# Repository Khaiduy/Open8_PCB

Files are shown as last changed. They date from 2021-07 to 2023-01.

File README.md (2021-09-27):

# Open8_PCB

The folder TR4_PGA257 contain:
1. Schematic and layout for PGA257 Socket (PGA257_Socket).
2. Schematic and layout for TEE-PCB version 4.0(TR4).
3. Schematic of the TEE-PGA257_v3.0, used as reference.
4. Pin map and port declaration of chip.
5. Folder ROHM_PCB_thuc is the new PCB that apply Thuc's suggestion.
  - Change SD card and Flash to Pmod module.
    Link: SD card: https://digilent.com/reference/pmod/pmodmicrosd/reference-manual?redirect=1
          Flash: https://digilent.com/reference/pmod/pmodsf3/reference-manual?redirect=
  - Change USB-UART to module: https://www.marutsu.co.jp/GoodsDetail.jsp?q=PL2303SA&salesGoodsCode=137791&shopNo=3
  - Supply clock from SMA only.

Two PCBs for EAGLE is contained:
1. QFP160 socket: the socket and pin connection only.
2. demo_open8: demo board for Open8 in SOTB with pin connection to QFP160 socket.

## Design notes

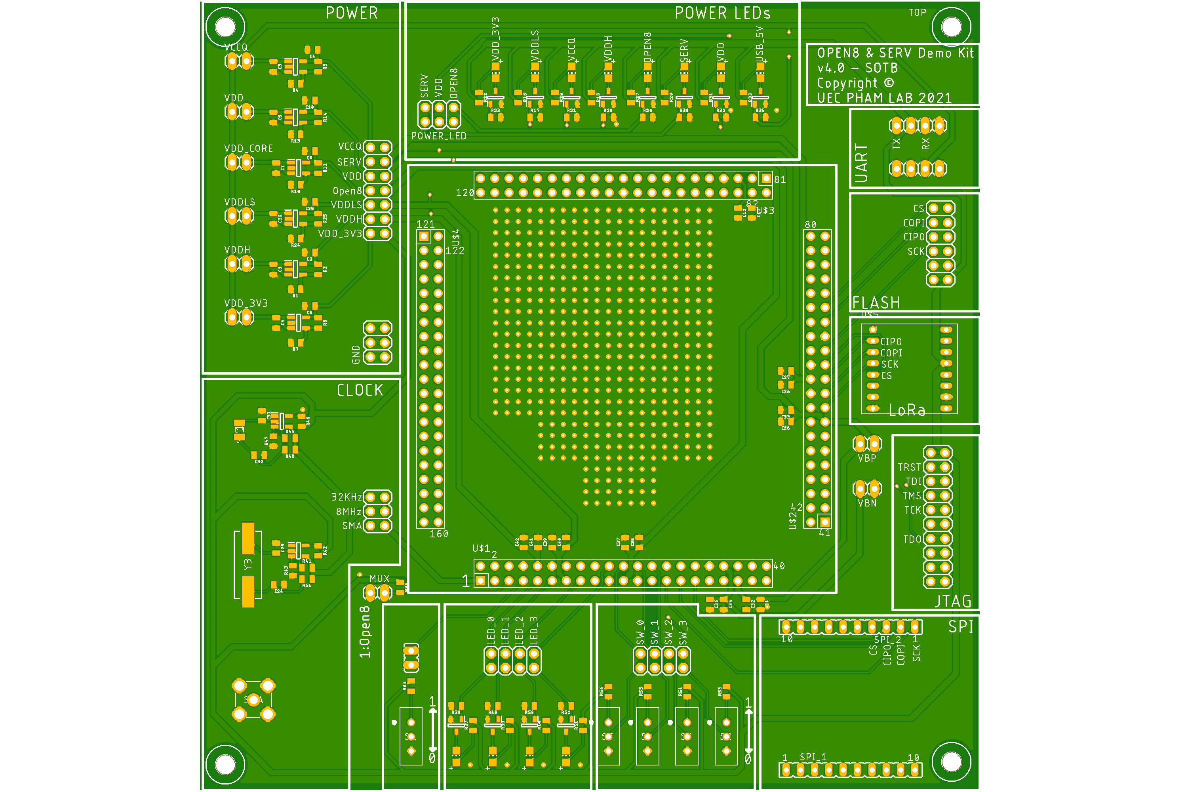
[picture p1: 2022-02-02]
SERV_Open8_SOTB_PCB/serv_open8_sotb_top.png

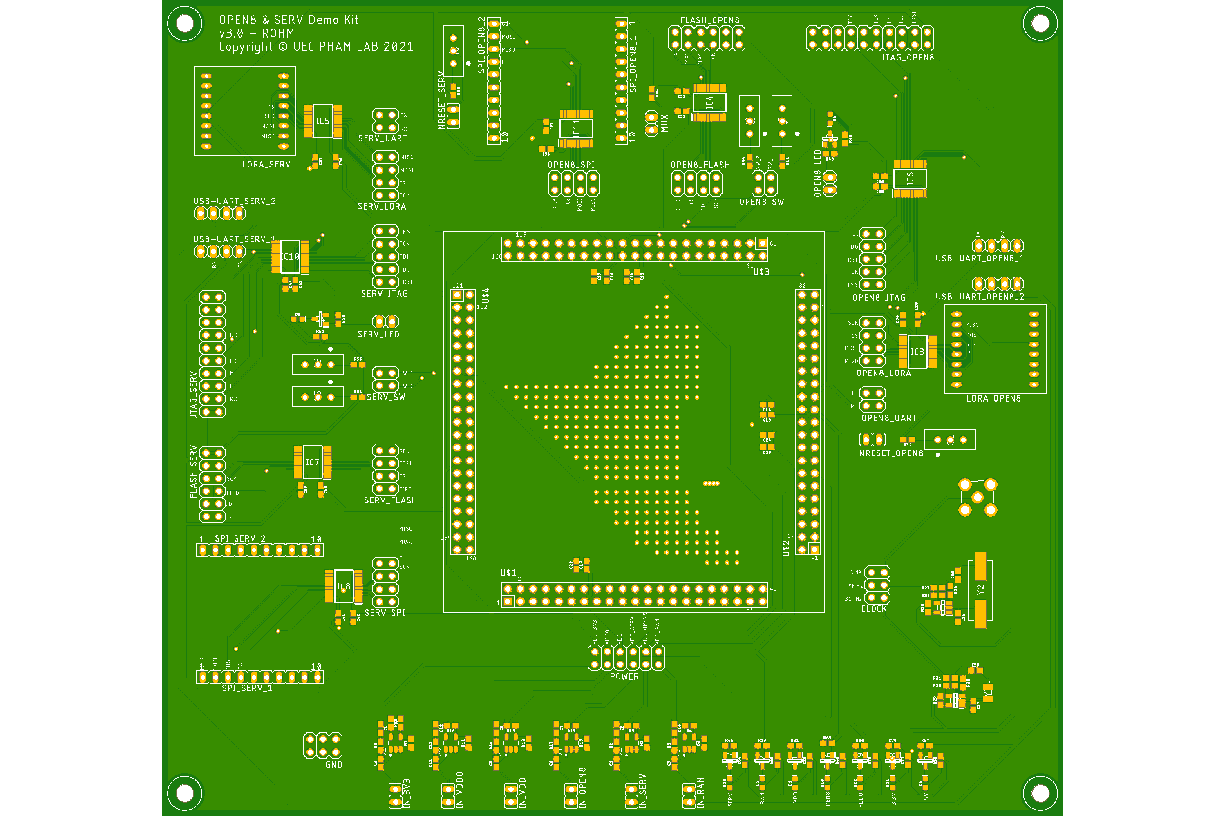
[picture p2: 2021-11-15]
SERV_Open8_ROHM_PCB/serv_open8_rohm_top.png

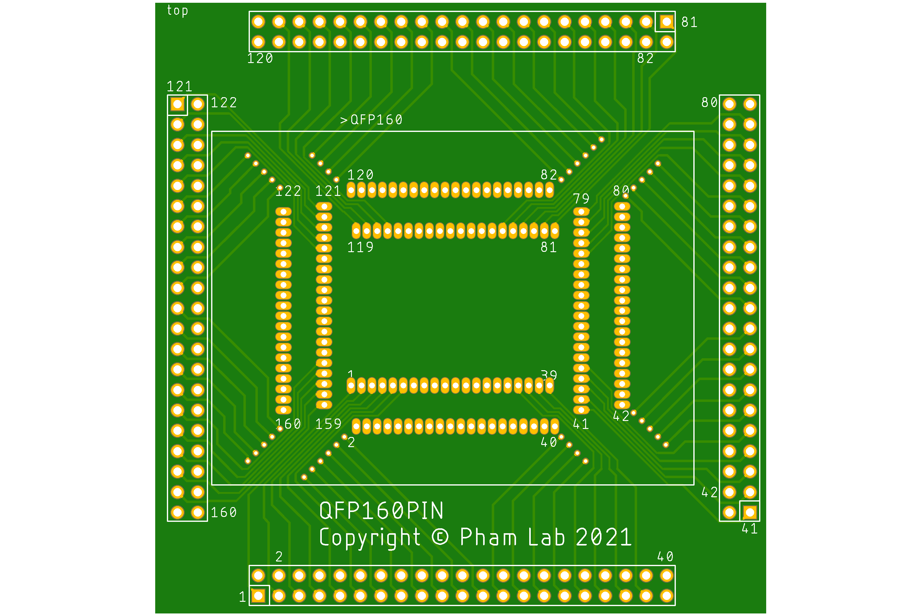
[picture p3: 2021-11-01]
QFP160_new_socket/qfp160_socket_new_top.png

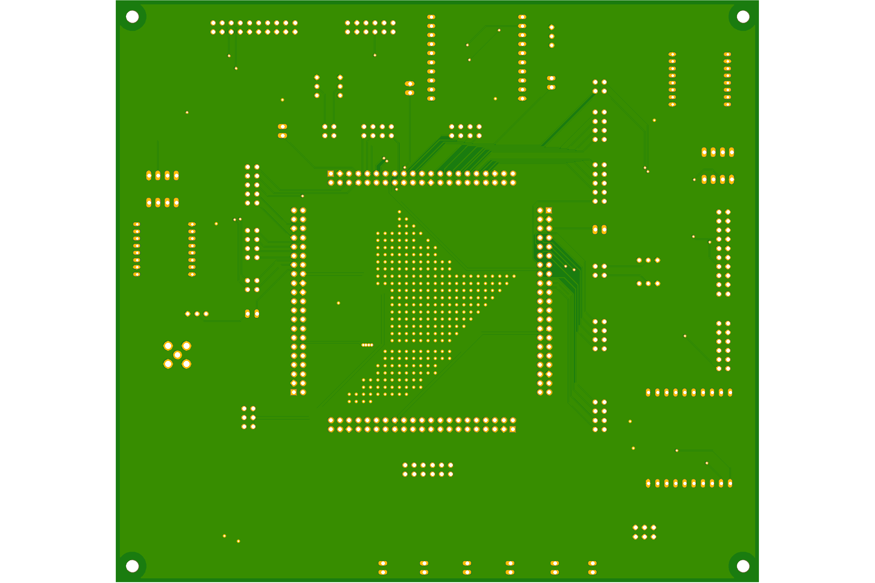
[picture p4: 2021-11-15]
SERV_Open8_ROHM_PCB/serv_open8_rohm_bottom.png

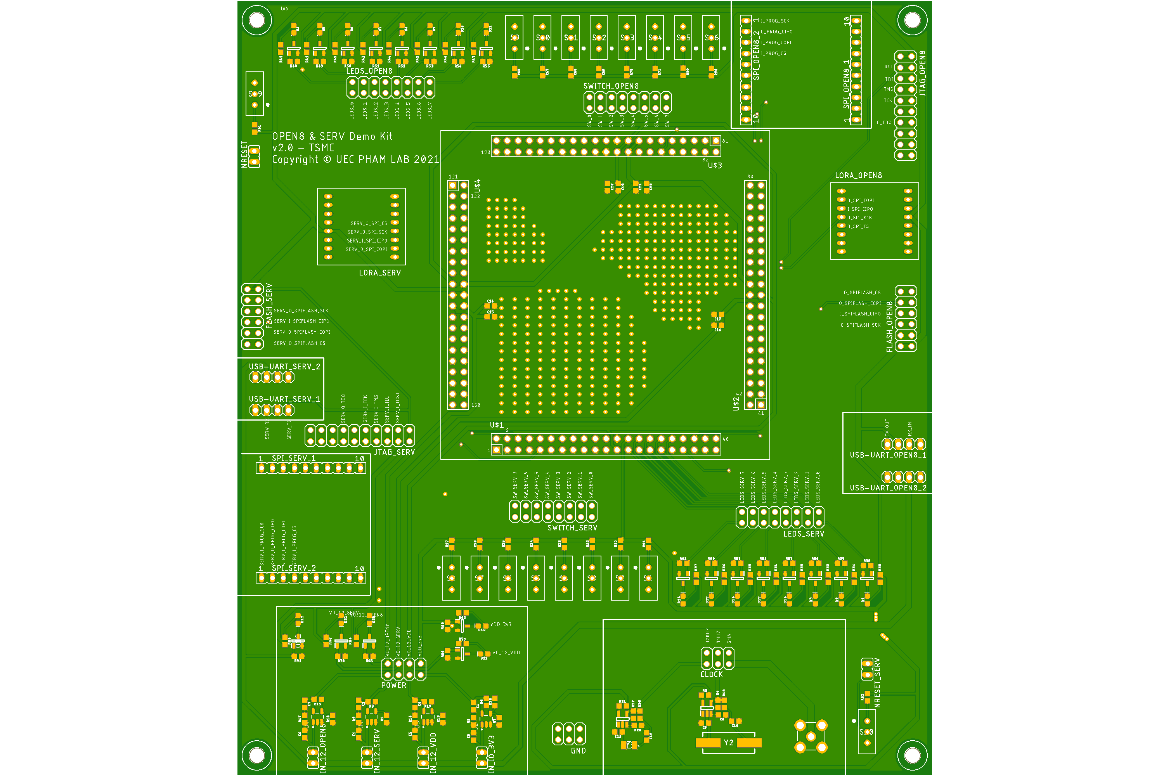
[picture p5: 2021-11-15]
SERV_Open8_TSMC_PCB/serv_open8_tsmc_top.png

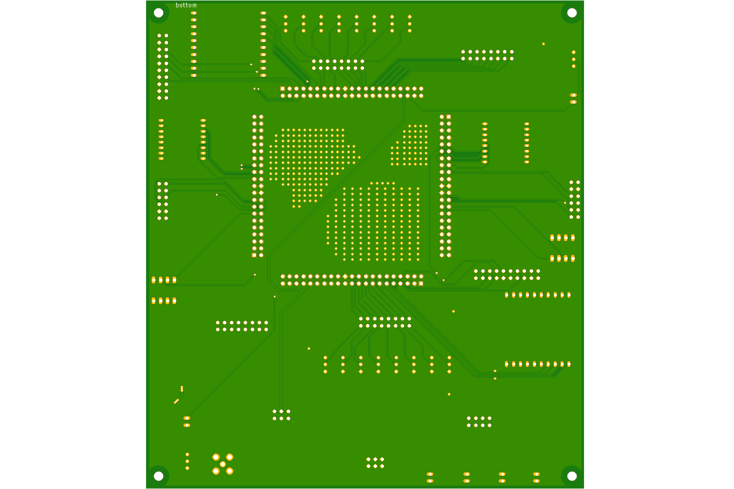
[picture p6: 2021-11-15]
SERV_Open8_TSMC_PCB/serv_open8_tsmc_bottom.png

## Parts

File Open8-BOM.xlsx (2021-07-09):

Comment | Designator | Footprint | LCSC Part #（optional）
100nF | C12, C14, C16, C17, C18, C19 | 603 | C14663
1Ω | R14, R17, R21 | 603 | C22936
1uF | C1, C3, C6, C9 | 603 | C105504
1.5kΩ | R11 | 603 | C22843
10kΩ | R18 | 603 | C25804
10uF | C5, C11, C13, C15, C20, C21, C22 | 603 | C96446
240Ω | R19 | 603 | C23350
27Ω | R9, R10 | 603 | C25190
3.3kΩ | R12 | 603 | C22978
330Ω | R1, R2, R3, R4, R5, R6, R7, R8, R22, R23, R24, R25, R26, R27 | 603 | C23138
4.7uF | C4, C7, C10 | 603 | C19666
43kΩ | R15 | 603 | C23172
62kΩ | R13, R16, R20 | 603 | C23221
BSH103,235 | FPGA_33, Q1, Q2, Q4, Q5 | SOT-23-3 | C88711
LED | D1 , D2, D3, D4, D5, D6, D7, D8, D9, D10, D11, D12, D13, D14 | LED_0603 | C72044
USB SOP-8 | IC1 | SOP-8_3.9x4.9x1.27P | C57946
Dropout Regulators | U3, U4, U5 | SOT-23-5 | C13997
USB Connectors | J3 | USB-MINI-SMD | C145778
Pin Header 2 1 | LORA_DIO0, LORA_NSS, LORA_RESET, J1, IN_33, IN_07, IN_12, OUT_07, OUT_12, VBN, VBP, VDD, VCCQ, VDDH, VDDLS | HDR-TH_2P-P2.54-V | C160332
Pin Header 6 1 | SV3, SV4 | 2.54mm 1X6 | C37208
Pin Header 40 2 | JP1, JP2, JP3, JP4 | HDR-TH_40P-P2.54-V-M-R2-C20-S2.54 | C124383
Pin Header 6 2 | GND | HDR-TH_6P-P2.54-V-R2-C3-S2.54 | C124384
Pin Header 3 1 | PIN_OUT | HDR-TH_3P-P2.54-V | C124376
Female Header 10 1 Straight | SV1, SV2 | 2.54mm | C35445
Pin Header 8 2 | SWITCH | HDR-TH_8P-P2.54-V-R2-C4-S2.54 | C124386
Pin Header 4 2 Straight | UART, OUT_33 | HDR-TH_4P-P2.54-V-R2-C2-S2.54 | C124362

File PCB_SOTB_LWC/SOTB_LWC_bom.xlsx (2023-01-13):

Comment | Designator | Footprint | LCSC Part #（optional）
LEDCHIPLED_0805 | LED3, LED4, LED5, LW_O0, LW_O1 | 805 | C34499
0.1uF | C15, C17, C19, C21, C23, C27, C29, C31, C33, C35, C37, C39, C41, C43, C45, C47, C49, C51, C53 | 1206 | C110255
10uF | C1, C3, C4, C6, C7, C9, C14, C16, C18, C20, C22, C26, C28, C30, C32, C34, C36, C38, C40, C42, C44, C46, C48, C50, C52 | 1206 | C13585
100pF | C54 | 805 | C1790
25pF | C24, C25 | 805 | C1807
50pF | C55 | 805 | C1823
2.7nF | C8 | 1206 | C1860
3.3nF | C5 | 1206 | C282859
4.7nF | C2 | 1206 | C9192
1.07k | R1 | 1206 | C290176
1.4k | R3 | 1206 | C102090
1.78k | R2 | 1206 | C706404
100 | R10 | 1206 | C118845
10k | R9 | 1206 | C132649
1k | R4, R7, R11, R14, R18 | 1206 | C1469
2.2M | R8 | 1206 | C111535
2k | R5 | 1206 | C17944
330 | R20 | 1206 | C114944
357 | R6 | 1206 | C205334
LP38511MR-ADJ_NOPB | IC1, IC2, IC3 | SOIC127P600X170 | C113276
Q13FC1350000400 | Y2 | SMD3215-2P | C32346
SN74LVC1G14DCKR | IC5 | SOT65P210X110-5N | C2976657
SN74LVC1GU04DCKR | IC4 | SOT65P210X110-5N | C485082

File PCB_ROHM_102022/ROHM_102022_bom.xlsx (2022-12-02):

Comment | Designator | Footprint | LCSC Part #（optional）
LEDCHIPLED_0805 | LED1, LED2, LED3, LED4, LOADED | 805 | C84256
0.1uF | C11, C12, C23, C25, C26, C29, C30, C33, C34, C15, C16, C17, C18, C21, C37, C38, C39, C40, C41, C42 | 1206 | C110255
100uF | C7, C9, C19 | 1206 | C15008
10pF | C3, C4 | 1206 | C107172
10uF | C13, C14, C24, C27, C28, C31, C32, C35, C36, C22 | 1206 | C13585
15pF | C5, C6 | 1206 | C1887
22uF | C8, C10, C20 | 1206 | C12891
10k | R1, R2, R11 | 1206 | C17902
330 | R3, R4, R5, R6, R14 | 1206 | C114944
AMS1117-1.8 | IC1, IC4, IC5 | SOT-223 | C6185
Q13FC1350000400 | Y2 | SMD3215-2P | C32346
Q22FA1280034500 | Y1 | SMD2016-4P | C255901
TXB0108PWR | IC7, IC10 | TSSOP-20 | C53406
W9825G6KH-6I | IC3 | TSOP-54 | C97572

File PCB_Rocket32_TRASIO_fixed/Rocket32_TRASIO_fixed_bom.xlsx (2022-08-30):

Comment | Designator | Footprint | LCSC Part #（optional）
LED | D1, D2, D3, D4 | 1206 | C434439
0.1uF | C1, C2, C3, C4, C11, C12 | 1206 | C110255
100uF | C5, C9 | 1206 | C15008
10k | R10, R12, R14, R16 | 1206 | C17902
10uF | C13, C14 | 1206 | C13585
22uF | C6, C10 | 1206 | C90146
330 | R11, R13, R15, R17 | 1206 | C25374
AMS1117-1.8 | IC3, IC5 | SOT-223 | C6185
2N7002K-7 | Q5, Q6, Q7, Q8 | SOT-23-3 | C705095
TXB0108PWR | IC1, IC2 | TSSOP-20 | C53406

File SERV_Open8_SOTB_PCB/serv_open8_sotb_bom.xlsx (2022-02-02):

Comment | Designator | Footprint | LCSC Part #（optional）
LED | LED1, LED2, LED3, LED4, LED5, LED6, LED7, LED8, LED9, LED10, LED11, LED12 | 805 | C2290
0.1uF | C12, C27, C33, C34, C36, C38, C40, C42 | 805 | C476766
1.0uF | C1, C3, C5, C7, C9, C22 | 805 | C24123
10M | R41, R45 | 805 | C26108
10k | R17, R19, R21, R23, R28, R30, R32, R34, R35, R36, R38, R40, R50, R52, R53, R54, R55, R56 | 805 | C115309
10uF | C11, C26, C28, C32, C35, C37, C39, C41 | 805 | C15850
133k | R2, R11, R14 | 805 | C17452
22pF | C30, C31 | 805 | C1804
2k | R44 | 805 | C17604
300k | R48 | 805 | C17616
330 | R16, R18, R20, R22, R27, R29, R31, R33, R37, R39, R49, R51 | 805 | C17630
36pF | C24, C29 | 805 | C327231
4.7uF | C2, C4, C6, C8, C10, C25 | 805 | C1779
47k | R42, R43, R46, R47 | 805 | C17713
482k | R5, R8 | 805 | C17717
66.5k | R1, R4, R7, R10, R13, R24, R25 | 805 | C17791
AP7331-WG-7 | IC1, IC2, IC5, IC7, IC8, IC9 | SOT-25 | C212322
BSH103,235 | Q1, Q2, Q3, Q4, Q5, Q6, Q7, Q8, Q9, Q10, Q11, Q12 | SOT-23-3 | C88711
HC-49SM8MHZ20PF30PPM | Y3 | SMD-CRY-3.8x13.5_2P | C107426
SN74LVC1GU04DBVR | IC12, IC13 | SOT-23-5 | C81934
Q13FC1350000400 | Y1 | SMD-3215_2P | C32346

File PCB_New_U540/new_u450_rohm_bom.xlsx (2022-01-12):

Comment | Designator | Footprint | LCSC Part #（optional）
LED | D1, D2, D3, D4 | 1206 | C93094
0.1uF | C1, C2, C3, C4, C11, C12 | 1206 | C110253
100uF | C5, C7, C9 | 1206 | C76656
10uF | C13, C14 | 1206 | C92797
10kOhm | R10, R12, R14, R16 | 1206 | C118075
22uF | C6, C8, C10 | 1206 | C386093
300Ohm | R11, R13, R15, R17 | 1206 | C229537
AMS1117-1.8 | IC3, IC4, IC5 | SOT-223 | C6185
CJ2301 S1 | Q1, Q2, Q3, Q4 | SOT-23-3 | C8547
TXB0108PWR | IC1, IC2 | SSOP-20_4 | C53406

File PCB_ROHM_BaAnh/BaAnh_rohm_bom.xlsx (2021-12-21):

Comment | Designator | Footprint | LCSC Part #（optional）
LED | LED1, LED2, LED3, LED4, LED5, LED6, LED7, LED8, LED9, LED10, LED11, LED12, LED13, LED14, LED15, LED16, LED17, LED18, LED19, LED20, LED21 | 805 | C165984
0.1uF | C1, C2, C3, C4, C5, C6, C7, C8 | 805 | C476766
1ohm | R45, R48, R59 | 805 | C247113
1uF | C9, C11, C13, C15, C17, C19, C21, C22, C24, C27, C29 | 805 | C28323
10k | R2, R4, R6, R8, R10, R12, R14, R16, R18, R20, R22, R24, R25, R26, R27, R28, R29, R30, R31, R32, R33, R34, R35, R36, R38, R40, R41, R42, R50, R52, R53, R54, R55, R56, R61, R63, R65, R67, R69 | 805 | C17414
10pF | C14, C16, C18, C20, C23, C26, C28, C30 | 805 | C1785
113k | R44, R47 | 805 | C17424
2198LPST | S1, S2 | 2198LPST | C314503
243k | R58 | 805 | C17573
330ohm | R1, R3, R5, R7, R9, R11, R13, R15, R17, R19, R21, R23, R37, R39, R49, R51, R60, R62, R64, R66, R68 | 805 | C17630
4.7uF | C10, C12, C25 | 805 | C98195
66.5k | R43, R46, R57 | 805 | C17791
BSH103,235 | Q1, Q2, Q3, Q4, Q5, Q6, Q7, Q8, Q9, Q10, Q11, Q12, Q13, Q14, Q15, Q16, Q17, Q18, Q19, Q20, Q21 | SOT-23-3 | C88711
TPS76201DBVR | IC3, IC5, IC7 | SOT-23-5 | C13997
TXB0108PWR | IC1, IC2, IC4, IC6 | TSSOP-20_4.4x6.5x0.65P | C53406

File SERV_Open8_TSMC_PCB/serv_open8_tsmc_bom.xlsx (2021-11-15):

Comment | Designator | Footprint | LCSC Part #（optional）
0.1uF | C14, C16, C19, C21 | 603 | C77055
1 OHM | R2, R8, R14, R17 | 603 | C247057
1.0uF | C1, C3, C5, C6 | 603 | C1689
10M OHM | R4, R20 | 603 | C7250
10kOHM | R11, R12, R22, R23, R24, R25, R26, R27, R38, R39, R48, R49, R50, R51, R52, R53, R54, R55, R56, R57, R58, R59, R60, R61, R63, R65, R66, R67, R68, R69, R70, R71, R78, R80, R81, R82, R89, R90, R91 | 603 | C25804
10uF | C15, C17, C20, C22 | 603 | C85713
22pF | C11, C12 | 603 | C1653
243kOHM | R10 | 603 | C23351
2kOHM | R18 | 603 | C22900
300kOHM | R29 | 603 | C23024
330OHM | R30, R31, R32, R33, R34, R35, R36, R37, R40, R41, R42, R43, R44, R45, R46, R47, R62, R64, R77, R79, R88 | 603 | C23138
36pF | C9, C10 | 603 | C159790
3kOHM | R9 | 603 | C4211
4.7uF | C2, C4, C7, C8 | 603 | C19666
47kOHM | R5, R6, R21, R28 | 603 | C25819
53.6kOHM | R3, R15, R19 | 603 | C23074
66.5KOHM | R1, R7, R13, R16 | 603 | C23225
BSH103,235 | Q1, Q2, Q3, Q4, Q5, Q6, Q7, Q8, Q9, Q10, Q11, Q14, Q15, Q16, Q17, Q18, Q19, Q25, Q26, Q27, Q28 | SOT-23-3 | C88711
HC-49SM8MHZ20PF30PPM | Y2 | SMD-CRY-3.8x13.5_2P | C107426
LED | D1, D2, D3, D4, D5, D6, D7, D8, D9, D10, D11, D12, D16, D17, D18, D19, D20, D21, D22, D27, D28 | 603 | C2286
Q13FC1350000400 | Y3 | SMD-3215_2P | C32346
SN74LVC1GU04DBVR | IC1, IC2 | SOT-23-5 | C81934
TPS76201DBVR | U1, U2, U3, U4 | SOT-23-5 | C13997

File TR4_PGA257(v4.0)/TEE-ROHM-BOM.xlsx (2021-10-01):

Comment | Designator | Footprint | LCSC Part #（optional）
0.1uF | C1, C2, C3, C4, C5, C6, C19, C21 | 603 | C77055
100uF | C14, C16, C18 | 603
10KOHM | R7, R8, R9, R22, R23, R24, R25, R26, R27, R28, R29, R30, R31, R32, R33, R58, R59, R60, R61, R62, R63, R64, R65, R66, R67, R68, R69, R70, R71 | 603 | C25804
10uF | C13, C15, C17, C20, C22 | 603 | C1691
15KOHM | R1, R3, R5 | 603 | C22809
Switch | S1_DIP8 | 2198LPST | C314503
330OHM | R46, R47, R48, R49, R50, R51, R52, R53, R54, R55, R56, R57 | 603 | C23138
6.8KOHM | R2, R4, R6 | 603 | C23212
BSH103,235 | Q3, Q4, Q5, Q6, Q7, Q8, Q9, Q10, Q11, Q12, Q13 | SOT-23-3 | C88711
DSHP03TSGET | S1 | SW-SMD | C50844
LED0 | D4, D5, D6, D7, D8, D9, D10, D11, D12, D13, D14, D15 | LED-0603 | C2286
LM1117IMPX-ADJ/NOPB | IC7, IC8, IC9 | SOT-223 | C19228
SN74AVC4T774RSVR | IC1, IC2, IC3 | UQFN-16 | C779392

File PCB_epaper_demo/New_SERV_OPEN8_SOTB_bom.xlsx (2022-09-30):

Comment | Designator | Footprint | LCSC Part #（optional）
0.01uF | C17 | 805 | C1710
0.1uF | C9, C12, C27, C33, C34, C36, C38, C40, C42 | 805 | C49678
1uF | C1, C3 | 805 | C24123
100uF | C16 | 805 | C141660
10uF | C5, C6, C7, C8, C10, C11, C26, C28, C32, C35, C37, C39, C41 | 805 | C17024
2.2uF | C2 | 805 | C87994
4.7uF | C4 | 805 | C92762
100k | R4, R3 | 805 | C149504
10k | R5, R7, R36 | 805 | C17414
560k | R2 | 805 | C352198
SN74AUP1G00DCKR | IC4, IC5 | SC-70-5 | C206053
SN74AUP1G14DBVR | U3 | SOT-23-5 | C2682131
SN74LVC1G32DBVR | U1 | SOT-23-5 | C10096
LM358AMX_NOPB | IC6 | SOIC-8 | C5423
1k | R11 | 805 | C17513
2.2k | R6 | 805 | C17520
110k | R1 | 805 | C413317

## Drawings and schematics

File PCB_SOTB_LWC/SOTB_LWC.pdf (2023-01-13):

2985-6004

## SN74LVC1GU04DCKR

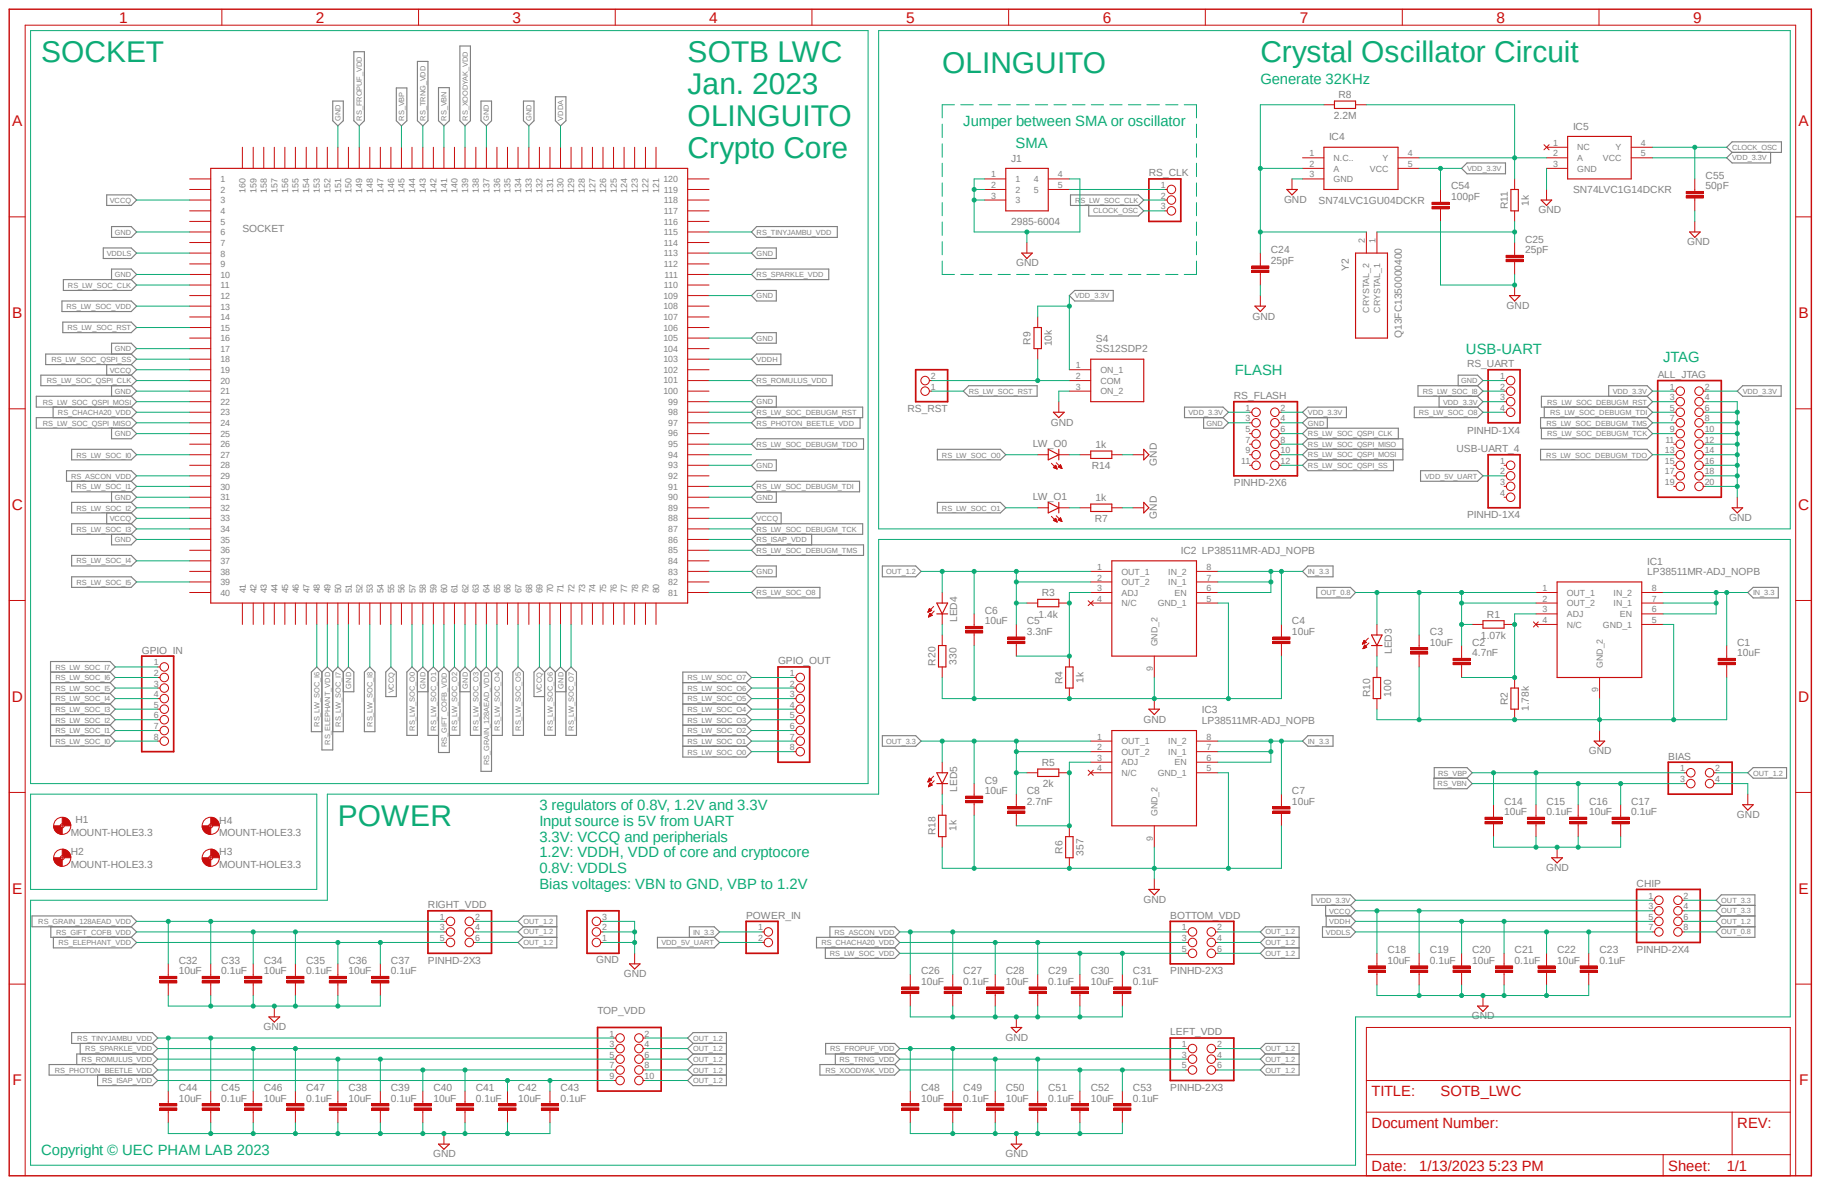
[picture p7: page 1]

Jumper between SMA or oscillator

3 | RS_LW_SOC_CLK CLOCK_OSC | 2 3

CHIP R¹⁰ R²⁰ R¹⁸
PINHD-2X4 ¹⁰⁰ ³³⁰ ¹k

Input source is 5V from UART
3.3V: VCCQ and peripherials
1.2V: VDDH, VDD of core and cryptocore
0.8V: VDDLS
Bias voltages: VBN to GND, VBP to 1.2V

Document Number: | REV:

Copyright © UEC PHAM LAB 2023

Date: 1/13/2023 5:23 PM | Sheet: 1/1

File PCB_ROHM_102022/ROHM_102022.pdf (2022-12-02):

## W9825G6KH-6I

## GND

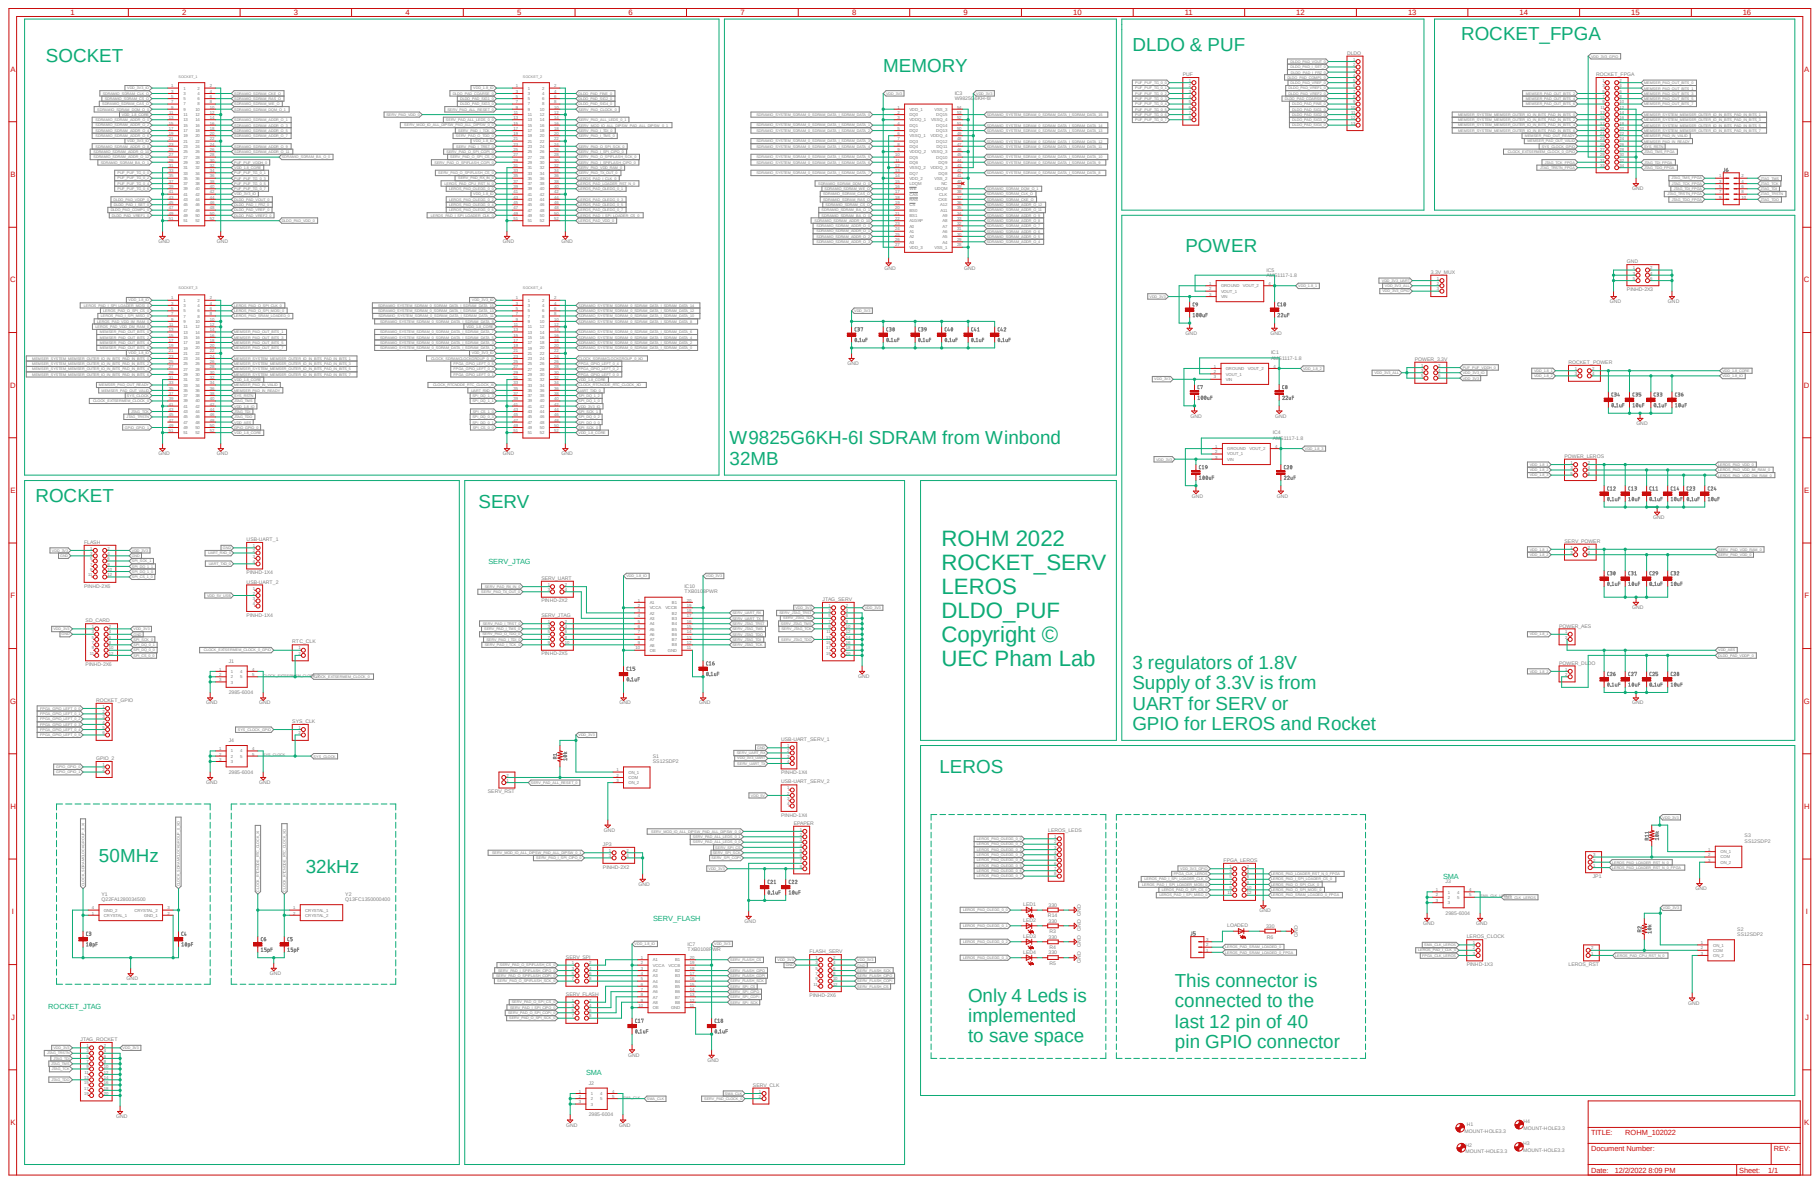
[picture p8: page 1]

3 regulators of 1.8V
Supply of 3.3V is from
UART for SERV or
GPIO for LEROS and Rocket

Document Number: | REV:

Date: 12/2/2022 8:09 PM | Sheet: 1/1

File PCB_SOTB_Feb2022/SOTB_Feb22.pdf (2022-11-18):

# GND ¹⁰k

# K_LEROS_RAM_2_VDD K_FL_ADDR[3]

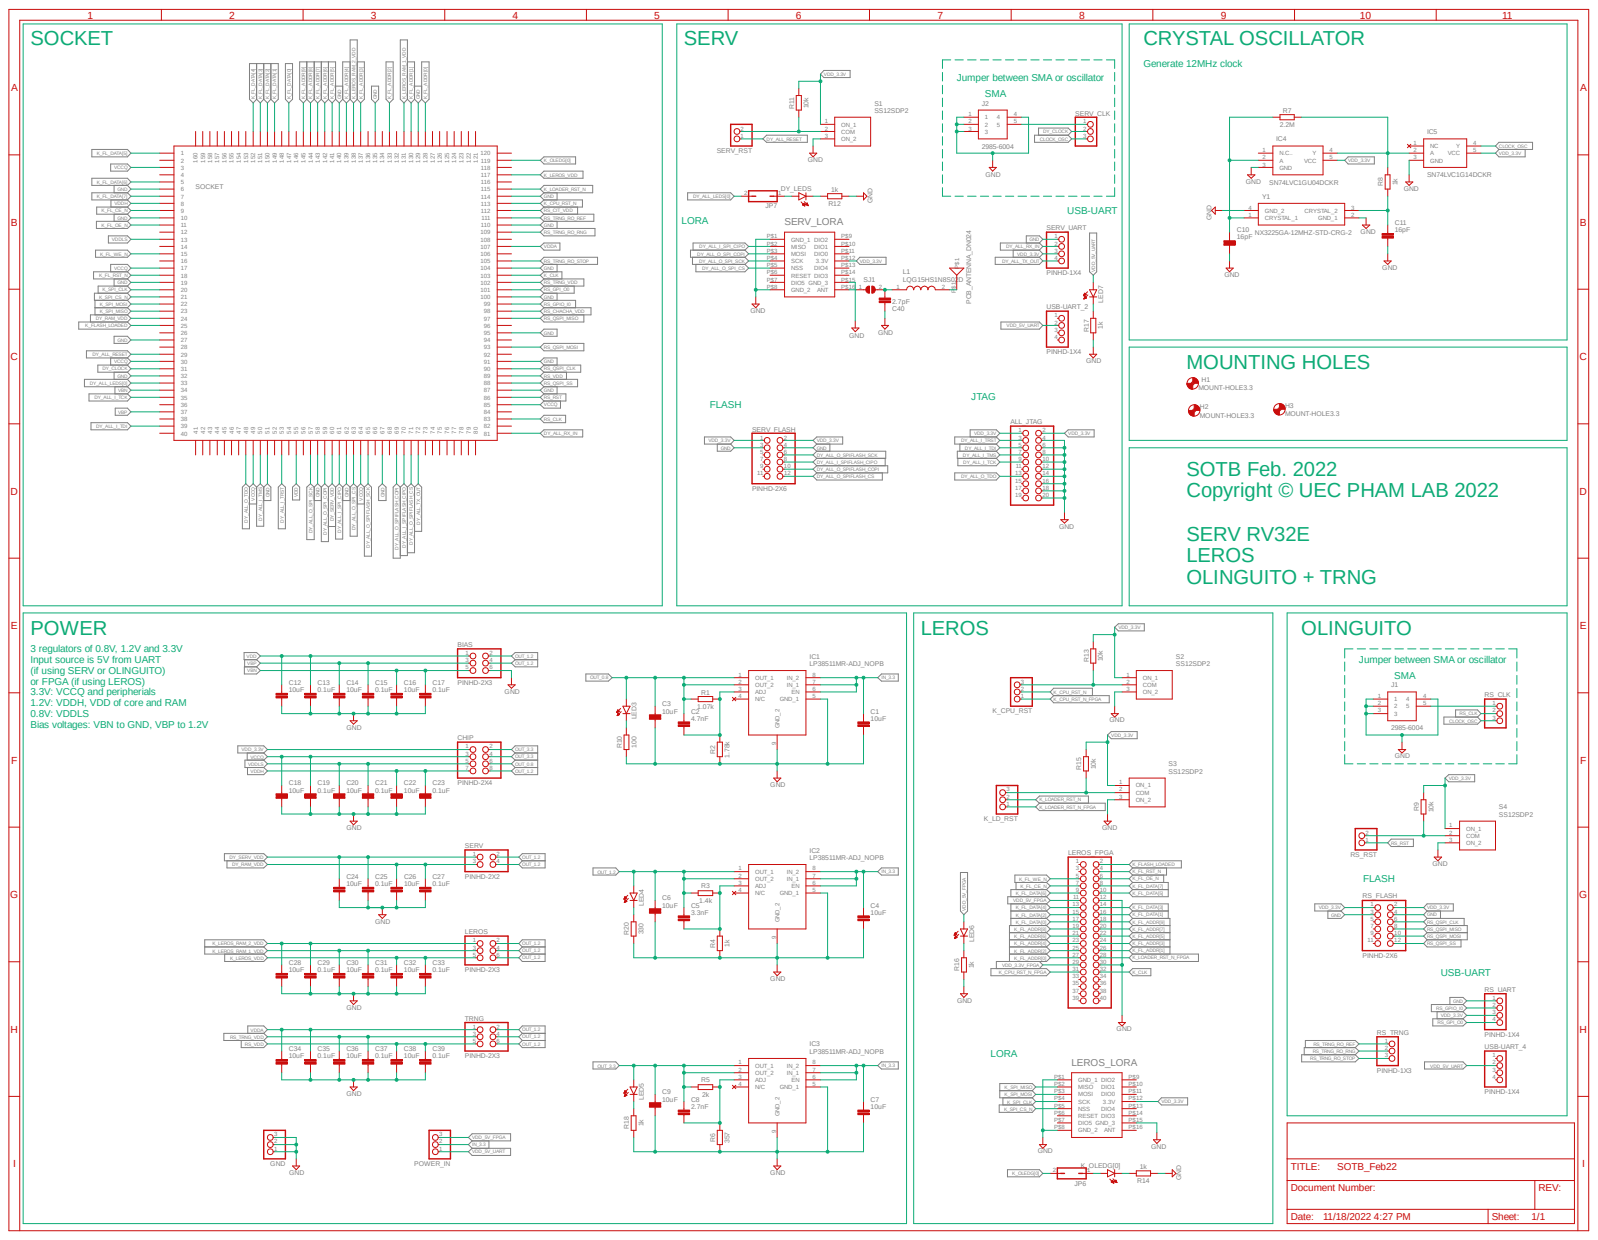
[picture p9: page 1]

Jumper between SMA or oscillator | Generate 12MHz clock

Copyright © UEC PHAM LAB 2022

VDD | | DY_ALL_O_SPI_SCK

BIAS | VDD_3.3V | | Jumper between SMA or oscillator SMA J1

3 regulators of 0.8V, 1.2V and 3.3V
Input source is 5V from UART
(if using SERV or OLINGUITO)
or FPGA (if using LEROS)
3.3V: VCCQ and peripherials
1.2V: VDDH, VDD of core and RAM
0.8V: VDDLS

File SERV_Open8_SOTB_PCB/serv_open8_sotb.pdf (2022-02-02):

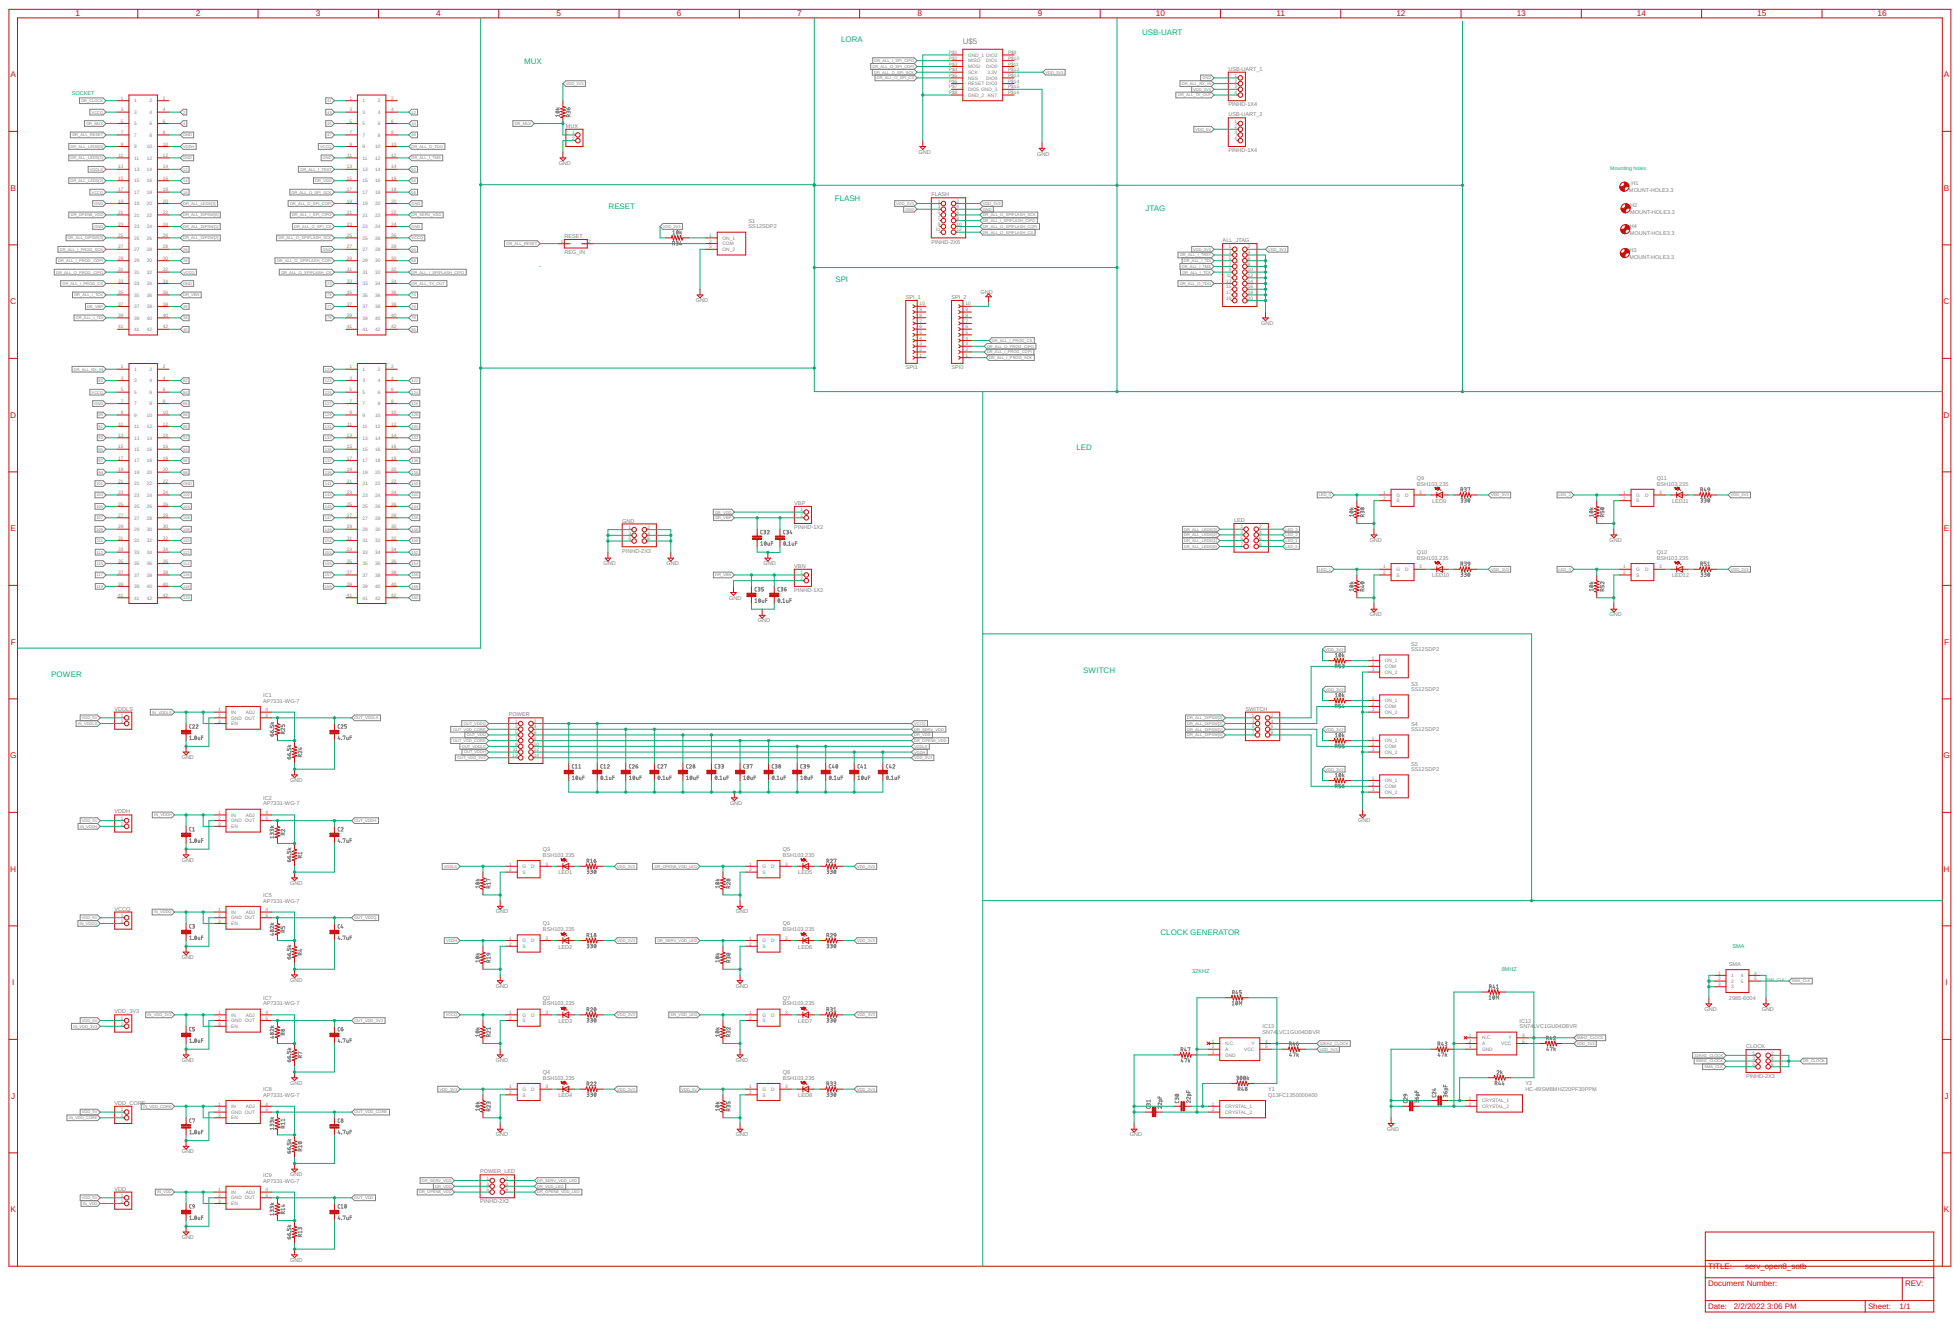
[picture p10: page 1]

Mounting holes
MOUNT-HOLE3.3 MOUNT-HOLE3.3

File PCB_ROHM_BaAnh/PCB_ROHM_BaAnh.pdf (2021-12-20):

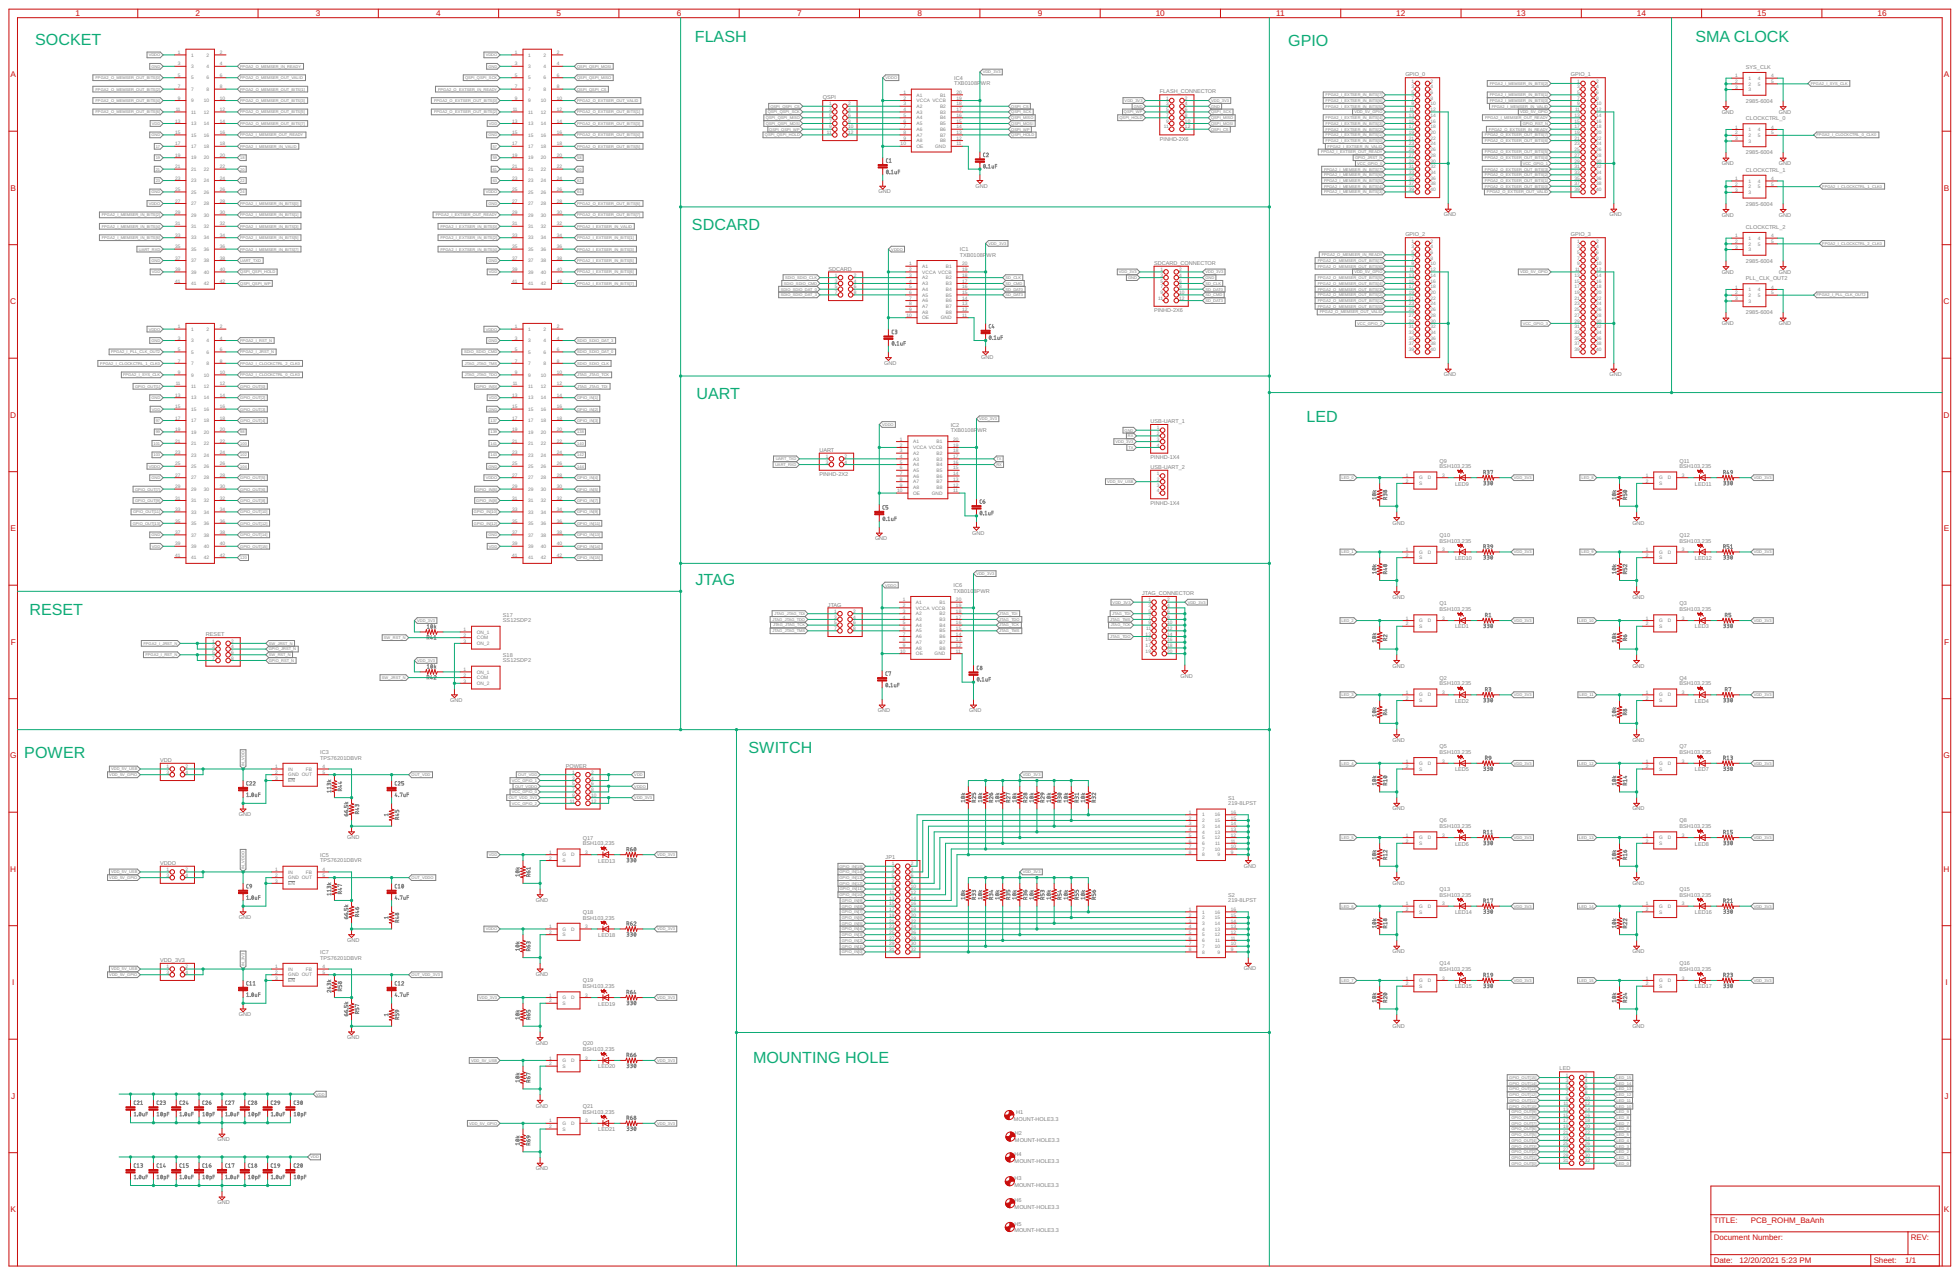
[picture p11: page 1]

MOUNT-HOLE3.3 MOUNT-HOLE3.3 MOUNT-HOLE3.3 MOUNT-HOLE3.3 GND

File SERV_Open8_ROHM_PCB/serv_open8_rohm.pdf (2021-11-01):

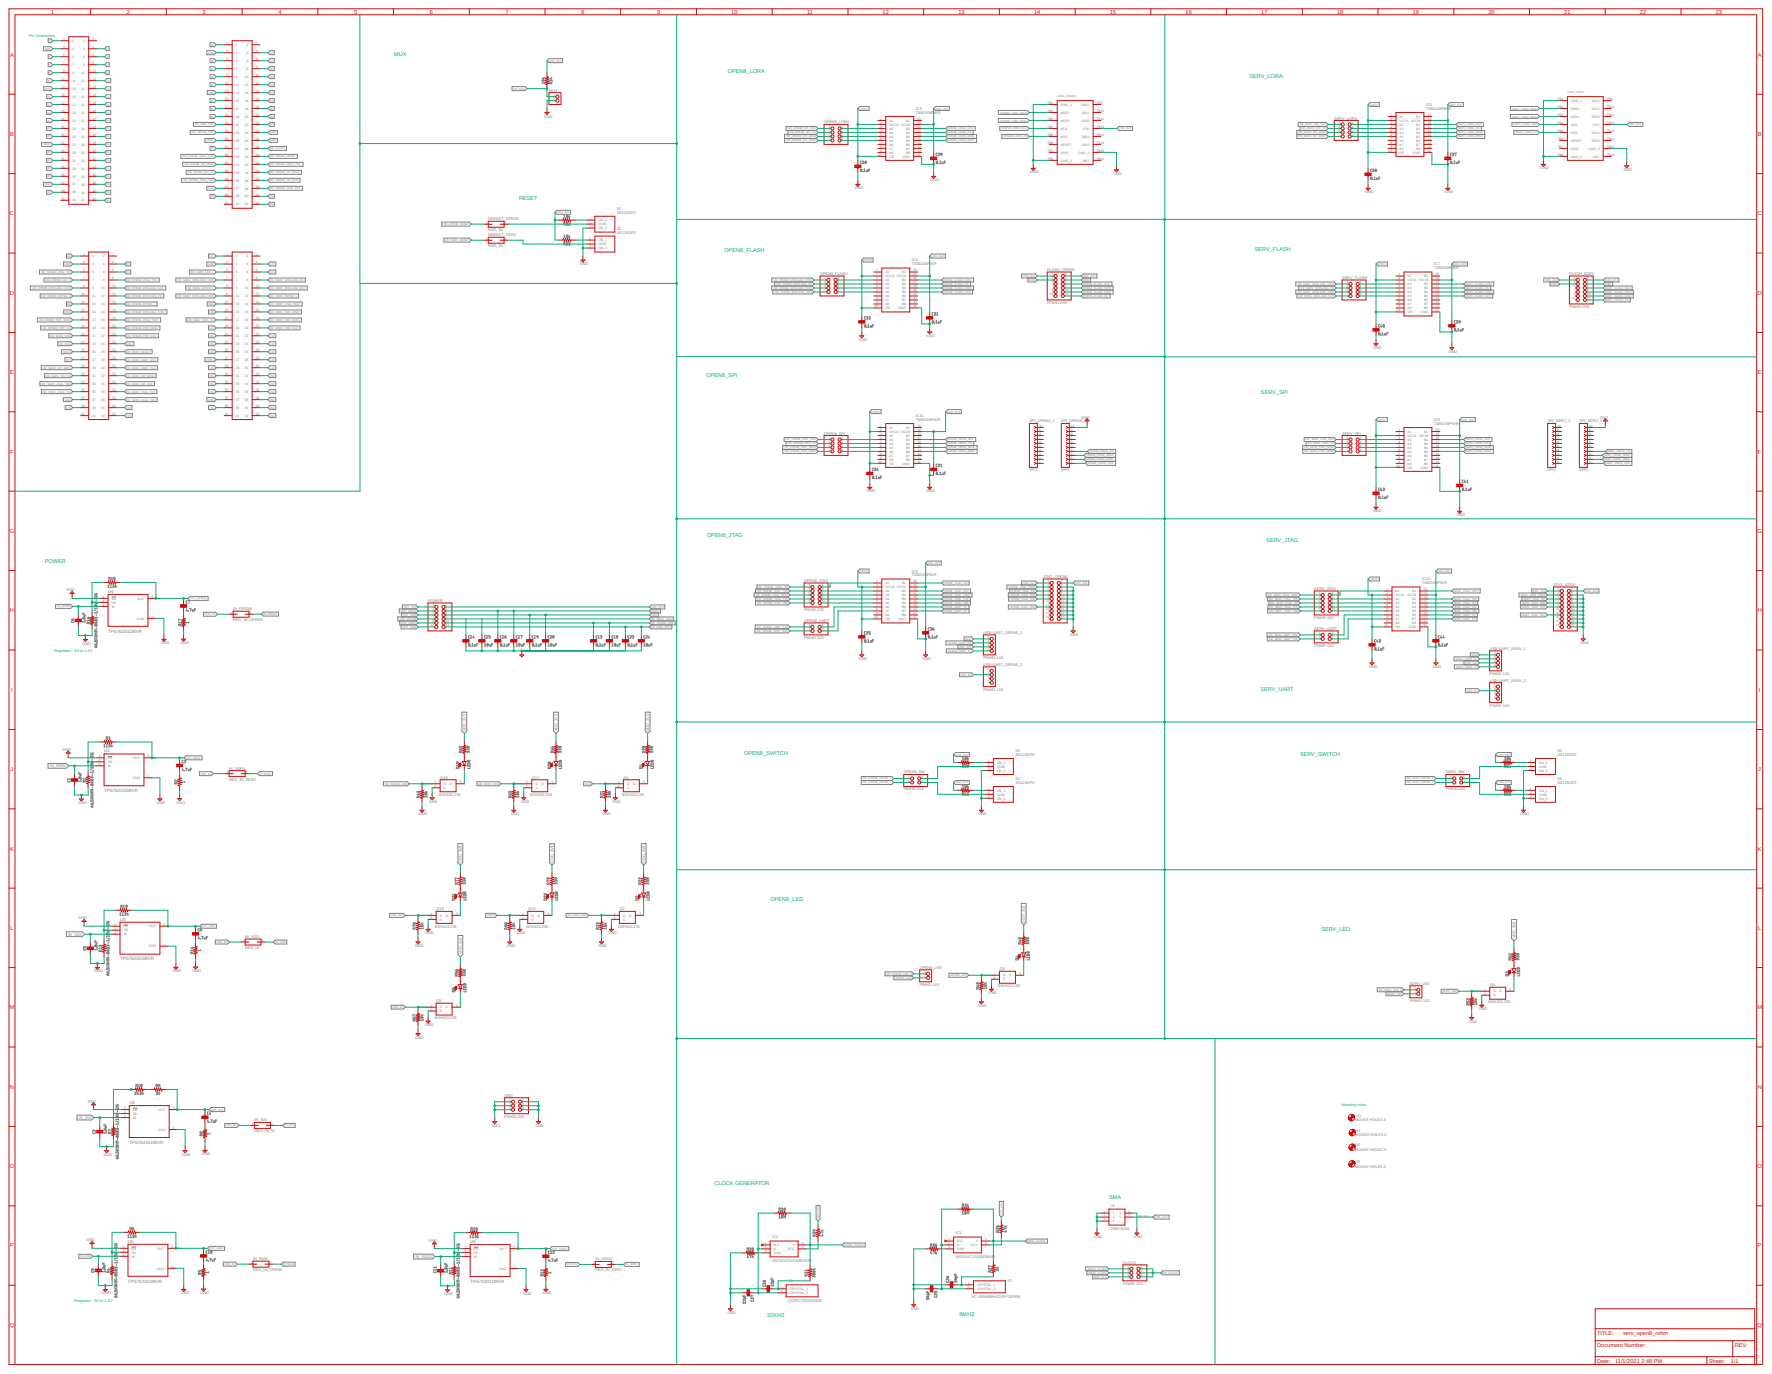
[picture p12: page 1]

Mounting holes
MOUNT-HOLE3.3 MOUNT-HOLE3.3

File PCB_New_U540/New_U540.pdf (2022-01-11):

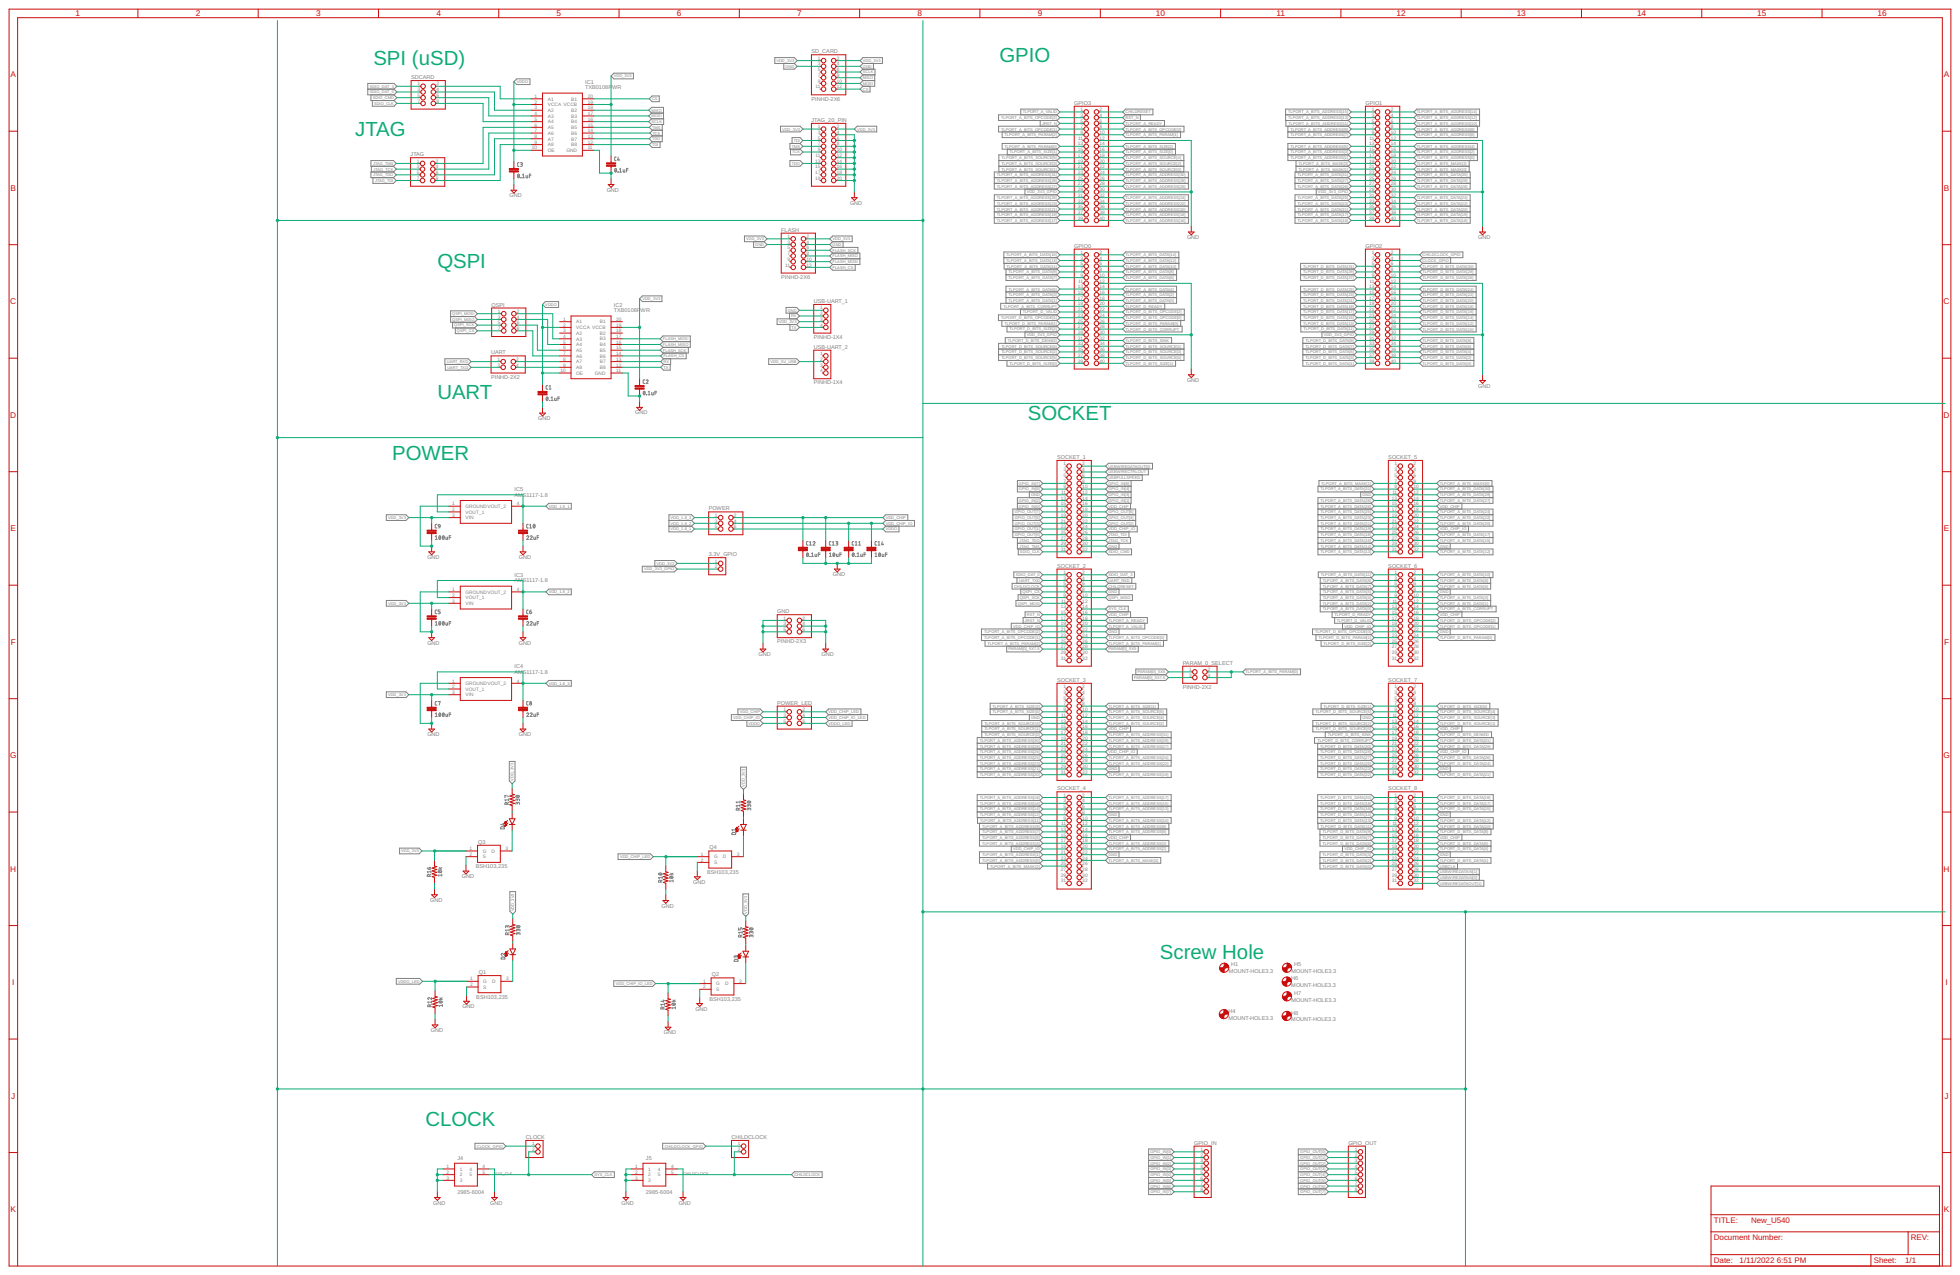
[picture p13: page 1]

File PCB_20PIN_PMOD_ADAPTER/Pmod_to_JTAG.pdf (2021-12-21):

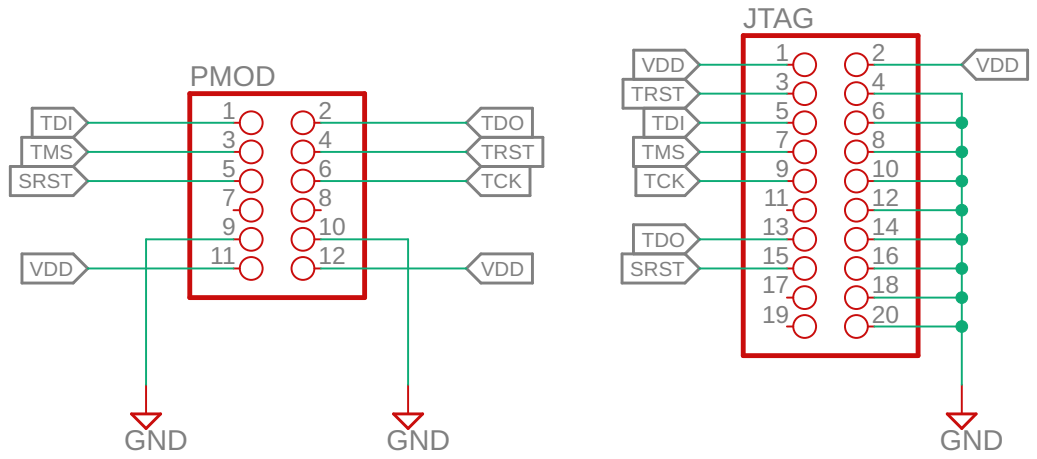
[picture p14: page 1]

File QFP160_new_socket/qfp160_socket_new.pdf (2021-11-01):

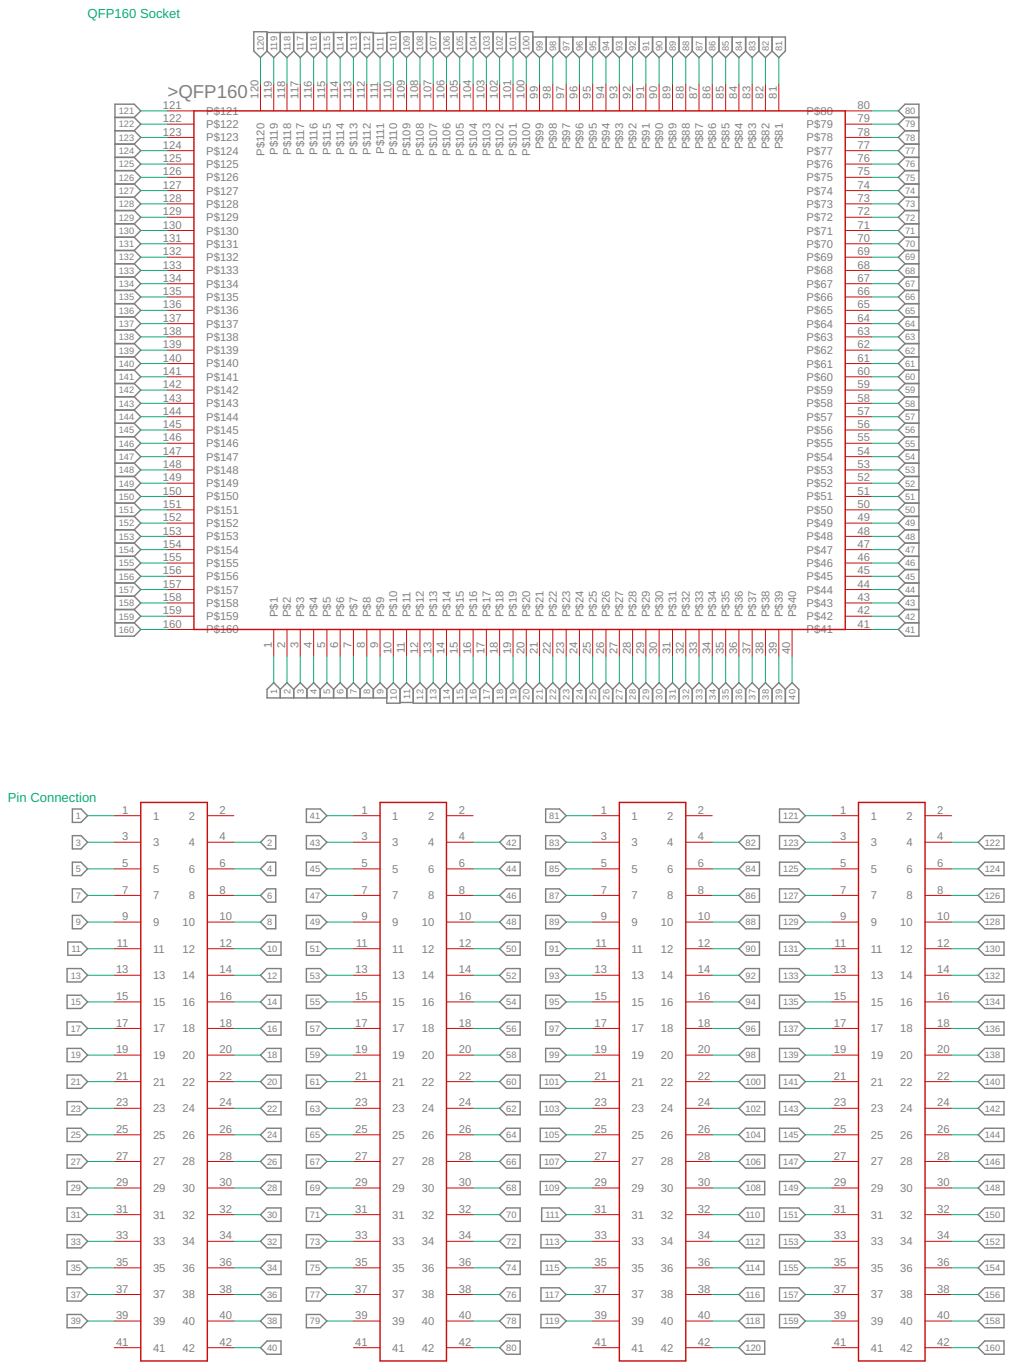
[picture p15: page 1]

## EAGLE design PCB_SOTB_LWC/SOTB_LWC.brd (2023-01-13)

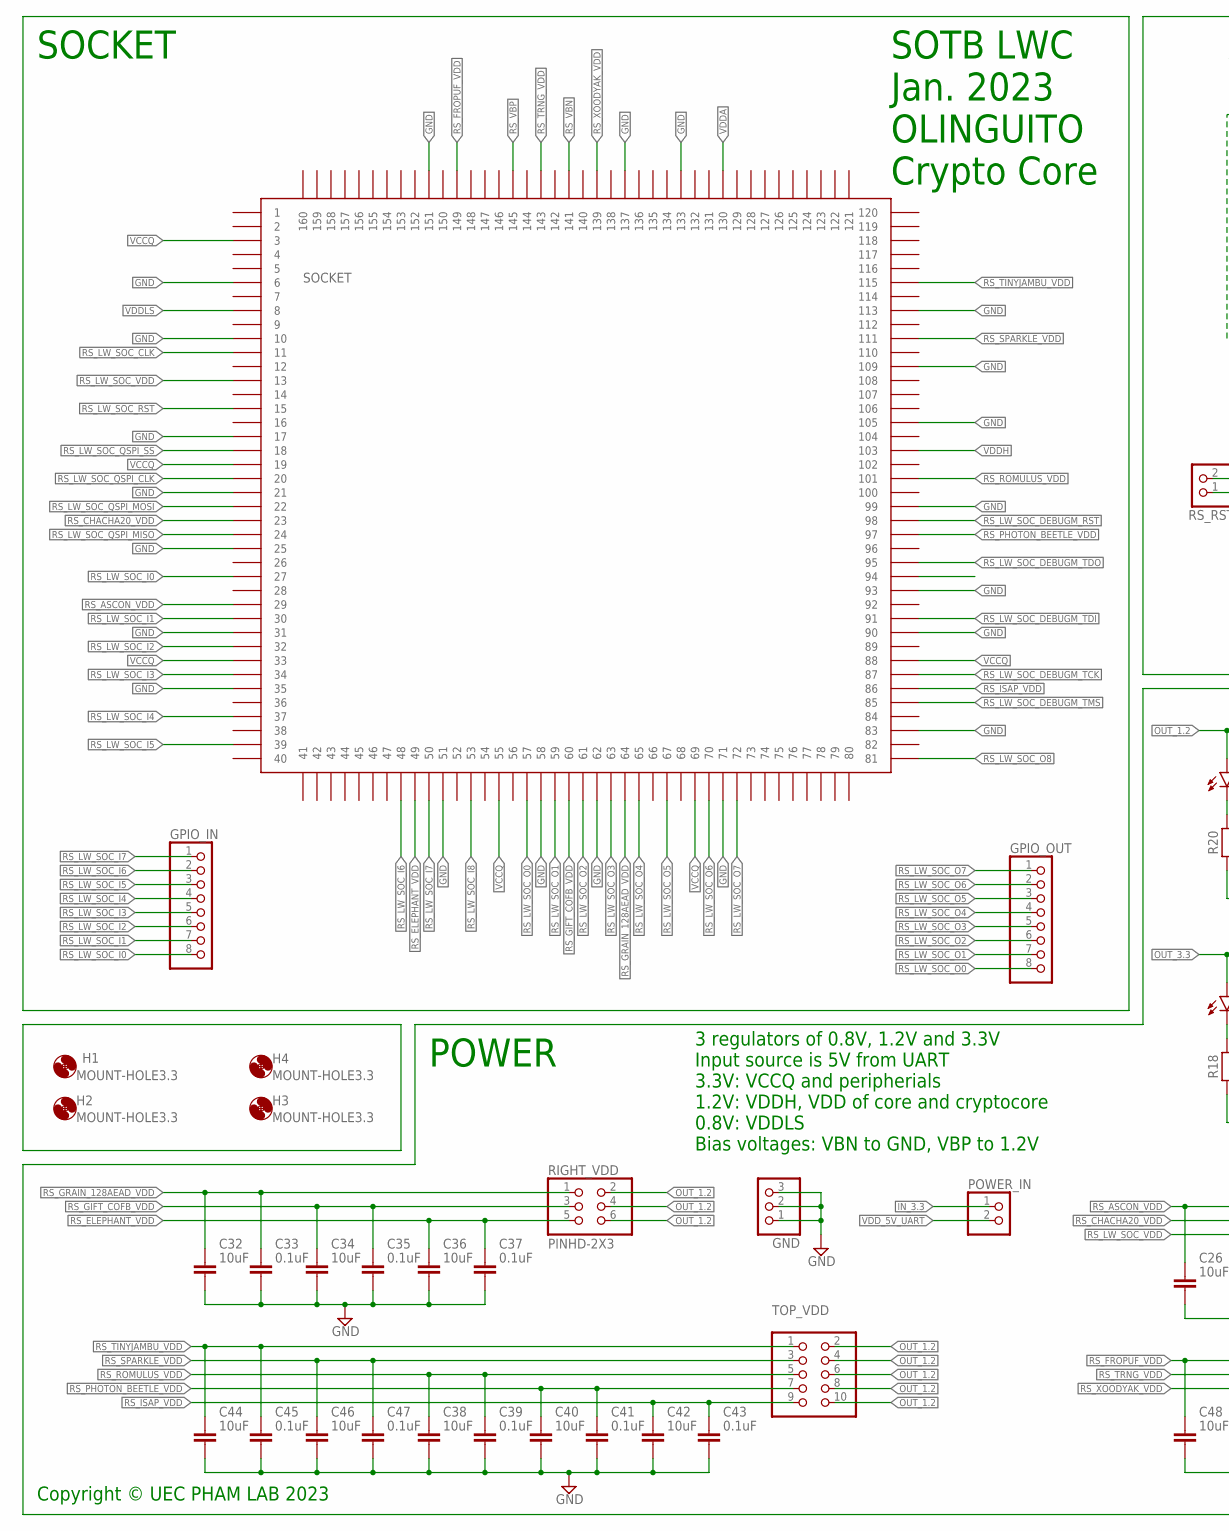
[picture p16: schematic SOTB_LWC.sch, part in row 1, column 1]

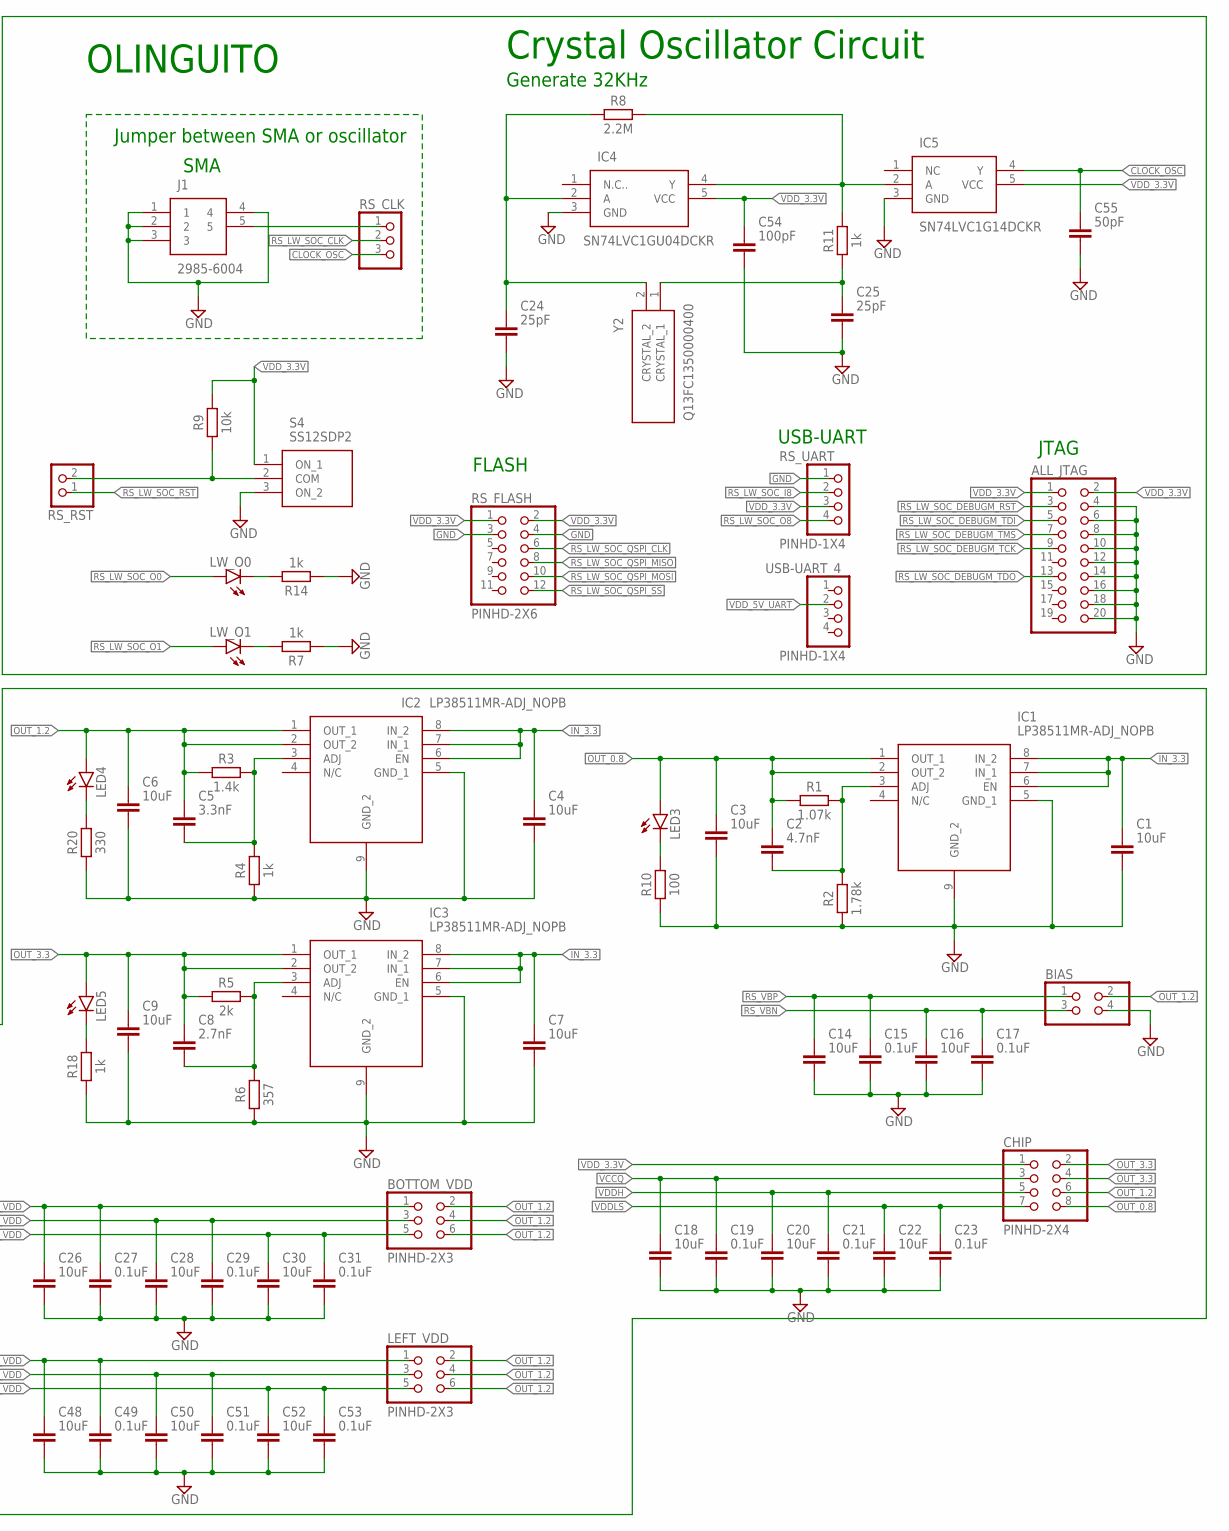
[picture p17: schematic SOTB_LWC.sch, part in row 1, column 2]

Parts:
ALL_JTAG: PINHD-2X10; 2X10
BIAS: PINHD-2X2; 2X02
BOTTOM_VDD: PINHD-2X3; 2X03
C1, C3, C4, C6, C7, C9, C14, C16, C18, C20, C22, C26, C28, C30, C32, C34, C36, C38, C40, C42, C44, C46, C48, C50, C52: 10uF; CAPC3216X135
C2: 4.7nF; CAPC3216X135
C5: 3.3nF; CAPC3216X135
C8: 2.7nF; CAPC3216X135
C15, C17, C19, C21, C23, C27, C29, C31, C33, C35, C37, C39, C41, C43, C45, C47, C49, C51, C53: 0.1uF; CAPC3216X135
C24, C25: 25pF; CAPC2012X110
C54: 100pF; CAPC2012X110
C55: 50pF; CAPC2012X110
CHIP: PINHD-2X4; 2X04
GND: PINHD-1X3; 1X03
GPIO_IN: PINHD-1X8; 1X08
GPIO_OUT: PINHD-1X8; 1X08
H1, H2, H3, H4: MOUNT-HOLE3.3; 3,3
IC1, IC2, IC3: LP38511MR-ADJ_NOPB; SOIC127P600X170-9N
IC4: SN74LVC1GU04DCKR; SOT65P210X110-5N
IC5: SN74LVC1G14DCKR; SOT65P210X110-5N
J1: 2985-6004; 29856004
LED3, LED4, LED5: LEDCHIPLED_0805; CHIPLED_0805
LEFT_VDD: PINHD-2X3; 2X03
LW_O0, LW_O1: LEDCHIPLED_0805; CHIPLED_0805
POWER_IN: PINHD-1X2; 1X02
R1: 1.07k; RESC3216X70
R2: 1.78k; RESC3216X70
R3: 1.4k; RESC3216X70
R4, R7, R11, R14, R18: 1k; RESC3216X70
R5: 2k; RESC3216X70
R6: 357; RESC3216X70
R8: 2.2M; RESC3216X70
R9: 10k; RESC3216X70
R10: 100; RESC3216X70
R20: 330; RESC3216X70
RIGHT_VDD: PINHD-2X3; 2X03
RS_CLK: PINHD-1X3; 1X03
RS_FLASH: PINHD-2X6; 2X06
RS_RST: PINHD-1X2; 1X02
RS_UART: PINHD-1X4; 1X04
S4: SS12SDP2
SOCKET: QFP28-160PIN
TOP_VDD: PINHD-2X5; 2X05
USB-UART_4: PINHD-1X4; 1X04
Y2: Q13FC1350000400

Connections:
CLOCK_OSC: C55.1, IC5.4 (Y), RS_CLK.3
GND: ALL_JTAG.4, ALL_JTAG.6, ALL_JTAG.8, ALL_JTAG.10, ALL_JTAG.12, ALL_JTAG.14, ALL_JTAG.16, ALL_JTAG.18, ALL_JTAG.20, BIAS.4, C1.2, C3.2, C4.2, C6.2, C7.2, C9.2, C14.2, C15.2, C16.2, C17.2, C18.2, C19.2, C20.2, C21.2, C22.2, C23.2, C24.2, C25.2, C26.2, C27.2, C28.2, C29.2, C30.2, C31.2, C32.2, C33.2, C34.2, C35.2, C36.2, C37.2, C38.2, C39.2, C40.2, C41.2, C42.2, C43.2, C44.2, C45.2, C46.2, C47.2, C48.2, C49.2, C50.2, C51.2, C52.2, C53.2, C54.2, C55.2, GND.1, GND.2, GND.3, IC1.5 (GND_1), IC1.9 (GND_2), IC2.5 (GND_1), IC2.9 (GND_2), IC3.5 (GND_1), IC3.9 (GND_2), IC4.3 (GND), IC5.3 (GND), J1.1, J1.2, J1.3, J1.4, R2.1, R4.1, R6.1, R7.1, R10.1, R14.1, R18.1, R20.1, RS_FLASH.3, RS_FLASH.4, RS_UART.1, S4.3 (ON_2), SOCKET.P$6 (6), SOCKET.P$10 (10), SOCKET.P$17 (17), SOCKET.P$21 (21), SOCKET.P$25 (25), SOCKET.P$31 (31), SOCKET.P$35 (35), SOCKET.P$51 (51), SOCKET.P$58 (58), SOCKET.P$62 (62), SOCKET.P$71 (71), SOCKET.P$83 (83), SOCKET.P$90 (90), SOCKET.P$93 (93), SOCKET.P$99 (99), SOCKET.P$105 (105), SOCKET.P$109 (109), SOCKET.P$113 (113), SOCKET.P$133 (133), SOCKET.P$137 (137), SOCKET.P$151 (151)
IN_3.3: C1.1, C4.1, C7.1, IC1.6 (EN), IC1.7 (IN_1), IC1.8 (IN_2), IC2.6 (EN), IC2.7 (IN_1), IC2.8 (IN_2), IC3.6 (EN), IC3.7 (IN_1), IC3.8 (IN_2), POWER_IN.1
unnamed: C2.2, IC1.3 (ADJ), R1.2, R2.2
unnamed: C5.2, IC2.3 (ADJ), R3.2, R4.2
unnamed: C8.2, IC3.3 (ADJ), R5.2, R6.2
unnamed: LW_O1.C, R7.2
unnamed: LW_O0.C, R14.2
unnamed: C24.1, IC4.2 (A), R8.1, Y2.2 (CRYSTAL_2)
unnamed: IC4.4 (Y), IC5.2 (A), R8.2, R11.2
unnamed: LED3.C, R10.2
unnamed: LED4.C, R20.2
unnamed: LED5.C, R18.2
unnamed: C25.1, R11.1, Y2.1 (CRYSTAL_1)
OUT_0.8: C2.1, C3.1, CHIP.8, IC1.1 (OUT_1), IC1.2 (OUT_2), LED3.A, R1.1
OUT_1.2: BIAS.2, BOTTOM_VDD.2, BOTTOM_VDD.4, BOTTOM_VDD.6, C5.1, C6.1, CHIP.6, IC2.1 (OUT_1), IC2.2 (OUT_2), LED4.A, LEFT_VDD.2, LEFT_VDD.4, LEFT_VDD.6, R3.1, RIGHT_VDD.2, RIGHT_VDD.4, RIGHT_VDD.6, TOP_VDD.2, TOP_VDD.4, TOP_VDD.6, TOP_VDD.8, TOP_VDD.10
OUT_3.3: C8.1, C9.1, CHIP.2, CHIP.4, IC3.1 (OUT_1), IC3.2 (OUT_2), LED5.A, R5.1
RST_SW3: R9.1, RS_RST.2, S4.2 (COM)
RS_ASCON_VDD: BOTTOM_VDD.1, C26.1, C27.1, SOCKET.P$29 (29)
RS_CHACHA20_VDD: BOTTOM_VDD.3, C28.1, C29.1, SOCKET.P$23 (23)
RS_ELEPHANT_VDD: C36.1, C37.1, RIGHT_VDD.5, SOCKET.P$49 (49)
RS_FROPUF_VDD: C48.1, C49.1, LEFT_VDD.1, SOCKET.P$149 (149)
RS_GIFT_COFB_VDD: C34.1, C35.1, RIGHT_VDD.3, SOCKET.P$60 (60)
RS_GRAIN_128AEAD_VDD: C32.1, C33.1, RIGHT_VDD.1, SOCKET.P$64 (64)
RS_ISAP_VDD: C42.1, C43.1, SOCKET.P$86 (86), TOP_VDD.9
RS_LW_SOC_CLK: RS_CLK.2, SOCKET.P$11 (11)
RS_LW_SOC_DEBUGM_RST: ALL_JTAG.3, SOCKET.P$98 (98)
RS_LW_SOC_DEBUGM_TCK: ALL_JTAG.9, SOCKET.P$87 (87)
RS_LW_SOC_DEBUGM_TDI: ALL_JTAG.5, SOCKET.P$91 (91)
RS_LW_SOC_DEBUGM_TDO: ALL_JTAG.13, SOCKET.P$95 (95)
RS_LW_SOC_DEBUGM_TMS: ALL_JTAG.7, SOCKET.P$85 (85)
RS_LW_SOC_I0: GPIO_IN.8, SOCKET.P$27 (27)
RS_LW_SOC_I1: GPIO_IN.7, SOCKET.P$30 (30)
RS_LW_SOC_I2: GPIO_IN.6, SOCKET.P$32 (32)
RS_LW_SOC_I3: GPIO_IN.5, SOCKET.P$34 (34)
RS_LW_SOC_I4: GPIO_IN.4, SOCKET.P$37 (37)
RS_LW_SOC_I5: GPIO_IN.3, SOCKET.P$39 (39)
RS_LW_SOC_I6: GPIO_IN.2, SOCKET.P$48 (48)
RS_LW_SOC_I7: GPIO_IN.1, SOCKET.P$50 (50)
RS_LW_SOC_I8: RS_UART.2, SOCKET.P$53 (53)
RS_LW_SOC_O0: GPIO_OUT.8, LW_O0.A, SOCKET.P$57 (57)
RS_LW_SOC_O1: GPIO_OUT.7, LW_O1.A, SOCKET.P$59 (59)
RS_LW_SOC_O2: GPIO_OUT.6, SOCKET.P$61 (61)
RS_LW_SOC_O3: GPIO_OUT.5, SOCKET.P$63 (63)
RS_LW_SOC_O4: GPIO_OUT.4, SOCKET.P$65 (65)
RS_LW_SOC_O5: GPIO_OUT.3, SOCKET.P$67 (67)
RS_LW_SOC_O6: GPIO_OUT.2, SOCKET.P$70 (70)
RS_LW_SOC_O7: GPIO_OUT.1, SOCKET.P$72 (72)
RS_LW_SOC_O8: RS_UART.4, SOCKET.P$81 (81)
RS_LW_SOC_QSPI_CLK: RS_FLASH.6, SOCKET.P$20 (20)
RS_LW_SOC_QSPI_MISO: RS_FLASH.8, SOCKET.P$24 (24)
RS_LW_SOC_QSPI_MOSI: RS_FLASH.10, SOCKET.P$22 (22)
RS_LW_SOC_QSPI_SS: RS_FLASH.12, SOCKET.P$18 (18)
RS_LW_SOC_RST: RS_RST.1, SOCKET.P$15 (15)
RS_LW_SOC_VDD: BOTTOM_VDD.5, C30.1, C31.1, SOCKET.P$13 (13)
RS_PHOTON_BEETLE_VDD: C40.1, C41.1, SOCKET.P$97 (97), TOP_VDD.7
RS_ROMULUS_VDD: C38.1, C39.1, SOCKET.P$101 (101), TOP_VDD.5
RS_SPARKLE_VDD: C46.1, C47.1, SOCKET.P$111 (111), TOP_VDD.3
RS_TINYJAMBU_VDD: C44.1, C45.1, SOCKET.P$115 (115), TOP_VDD.1
RS_TRNG_VDD: C50.1, C51.1, LEFT_VDD.3, SOCKET.P$143 (143)
RS_VBN: BIAS.3, C16.1, C17.1, SOCKET.P$141 (141)
RS_VBP: BIAS.1, C14.1, C15.1, SOCKET.P$145 (145)
RS_XOODYAK_VDD: C52.1, C53.1, LEFT_VDD.5, SOCKET.P$139 (139)
SMA_CLK1: J1.5, RS_CLK.1
VCCQ: C18.1, C19.1, CHIP.3, SOCKET.P$3 (3), SOCKET.P$19 (19), SOCKET.P$33 (33), SOCKET.P$55 (55), SOCKET.P$69 (69), SOCKET.P$88 (88)
VDDA: SOCKET.P$130 (130)
VDDH: C20.1, C21.1, CHIP.5, SOCKET.P$103 (103)
VDDLS: C22.1, C23.1, CHIP.7, SOCKET.P$8 (8)
VDD_3.3V: ALL_JTAG.1, ALL_JTAG.2, C54.1, CHIP.1, IC4.5 (VCC), IC5.5 (VCC), R9.2, RS_FLASH.1, RS_FLASH.2, RS_UART.3, S4.1 (ON_1)
VDD_5V_UART: POWER_IN.2, USB-UART_4.2

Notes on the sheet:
SMA
FLASH
OLINGUITO
Jumper between SMA or oscillator
USB-UART
POWER
3 regulators of 0.8V, 1.2V and 3.3V Input source is 5V from UART 3.3V: VCCQ and peripherials 1.2V: VDDH, VDD of core and cryptocore 0.8V: VDDLS Bias voltages: VBN to GND, VBP to 1.2V
JTAG
Crystal Oscillator Circuit
Generate 32KHz
SOCKET
SOTB LWC Jan. 2023 OLINGUITO Crypto Core
Copyright © UEC PHAM LAB 2023

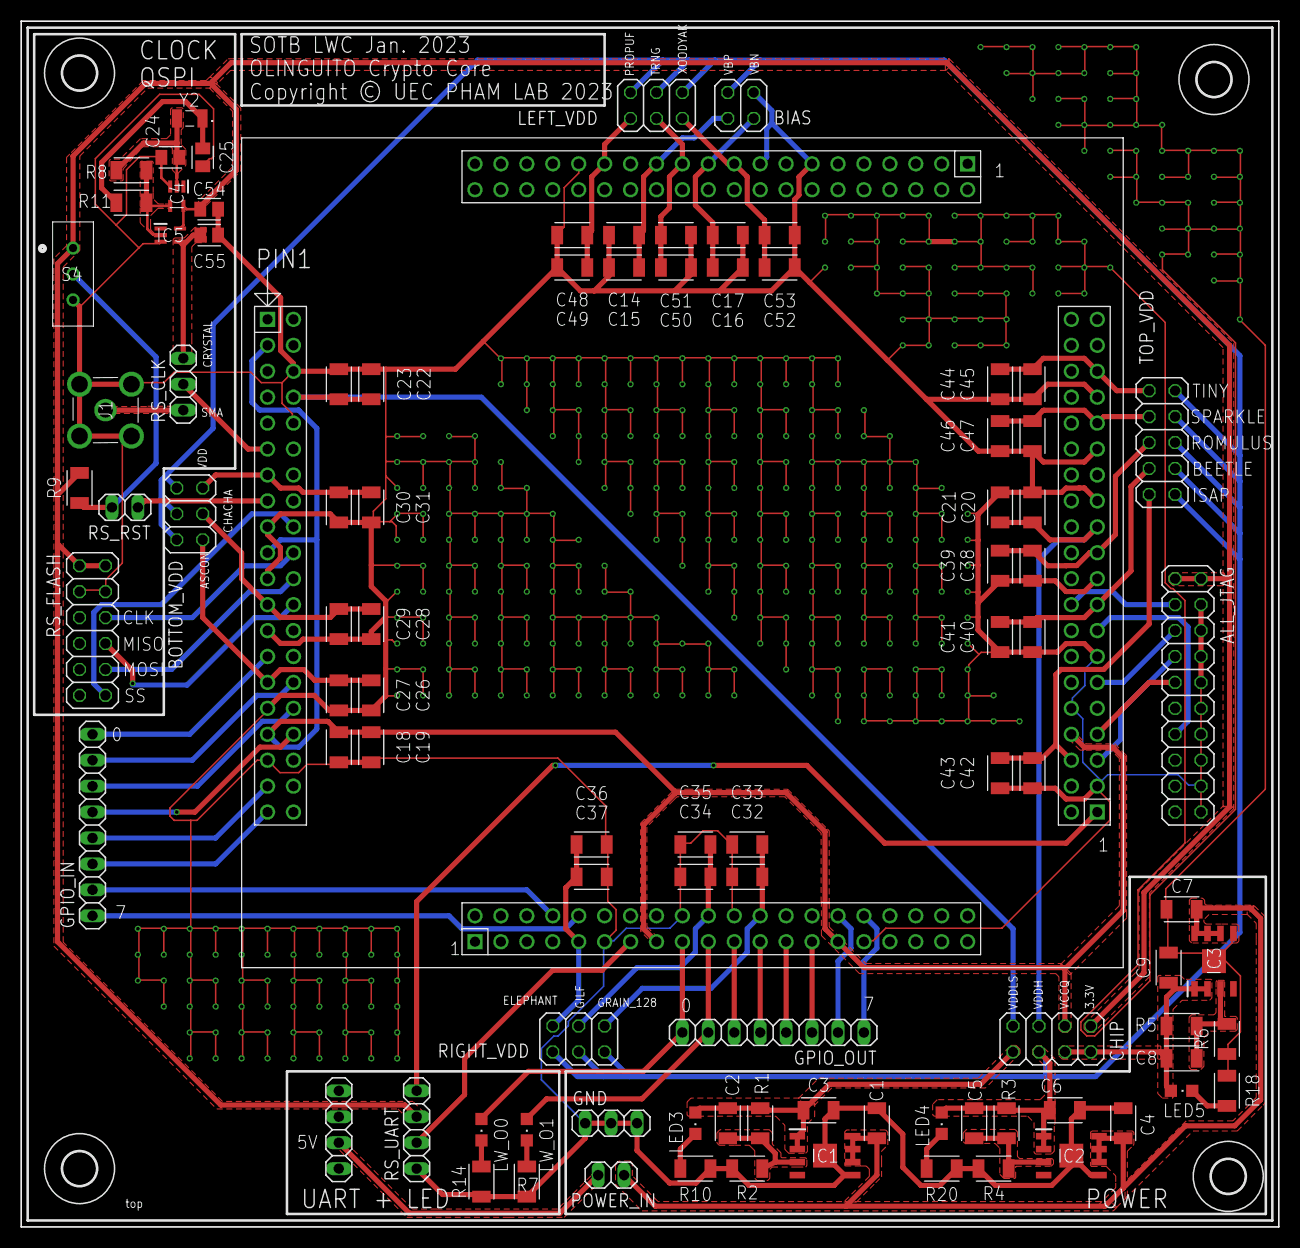
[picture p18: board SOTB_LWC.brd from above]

Board: 2 copper layers, 123.2 x 118.1 mm, 99 parts (0 on the bottom side), 69 nets.

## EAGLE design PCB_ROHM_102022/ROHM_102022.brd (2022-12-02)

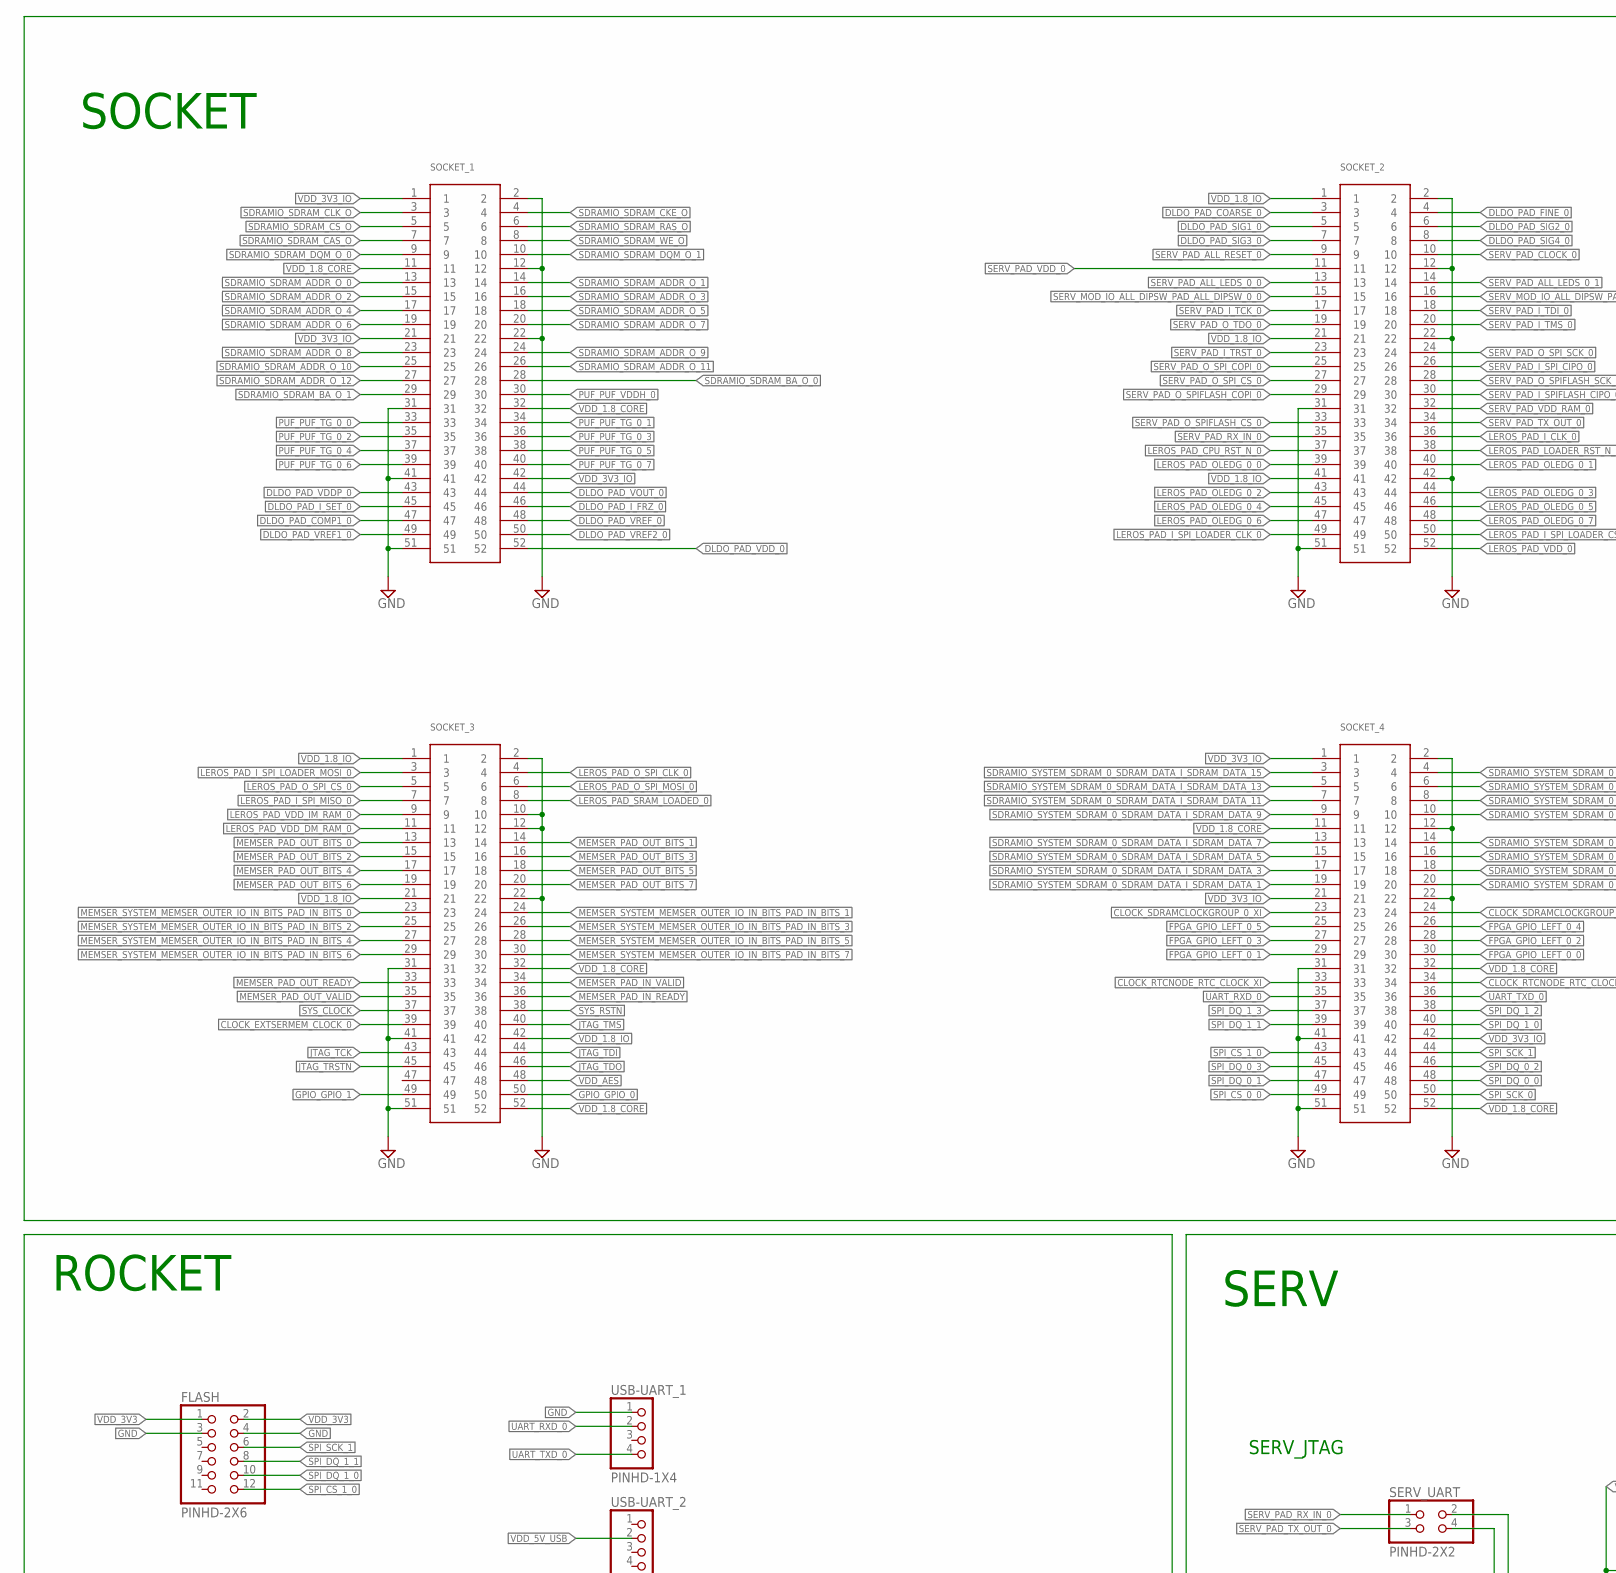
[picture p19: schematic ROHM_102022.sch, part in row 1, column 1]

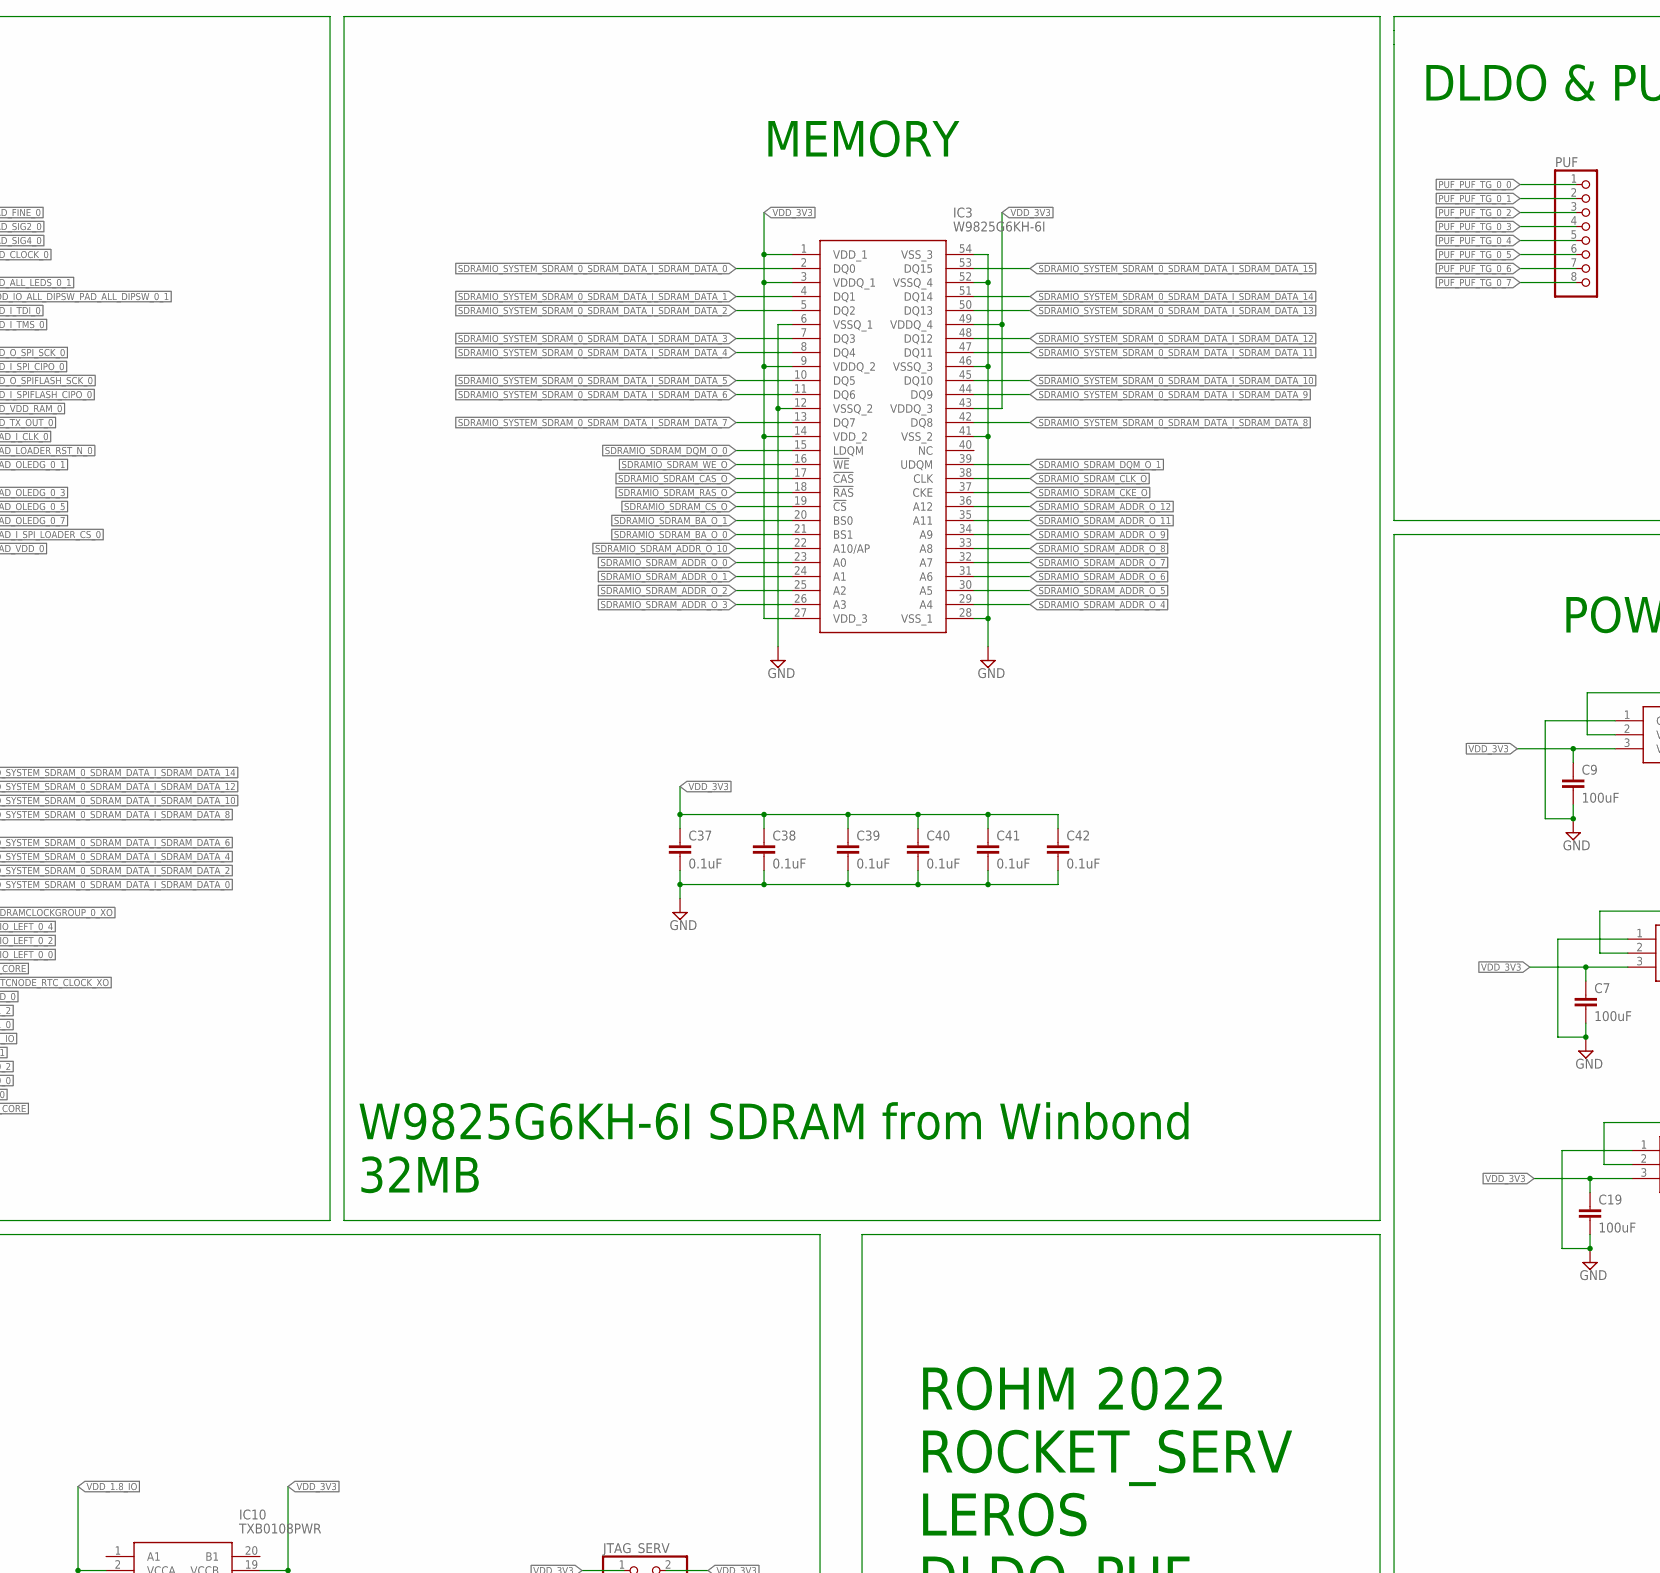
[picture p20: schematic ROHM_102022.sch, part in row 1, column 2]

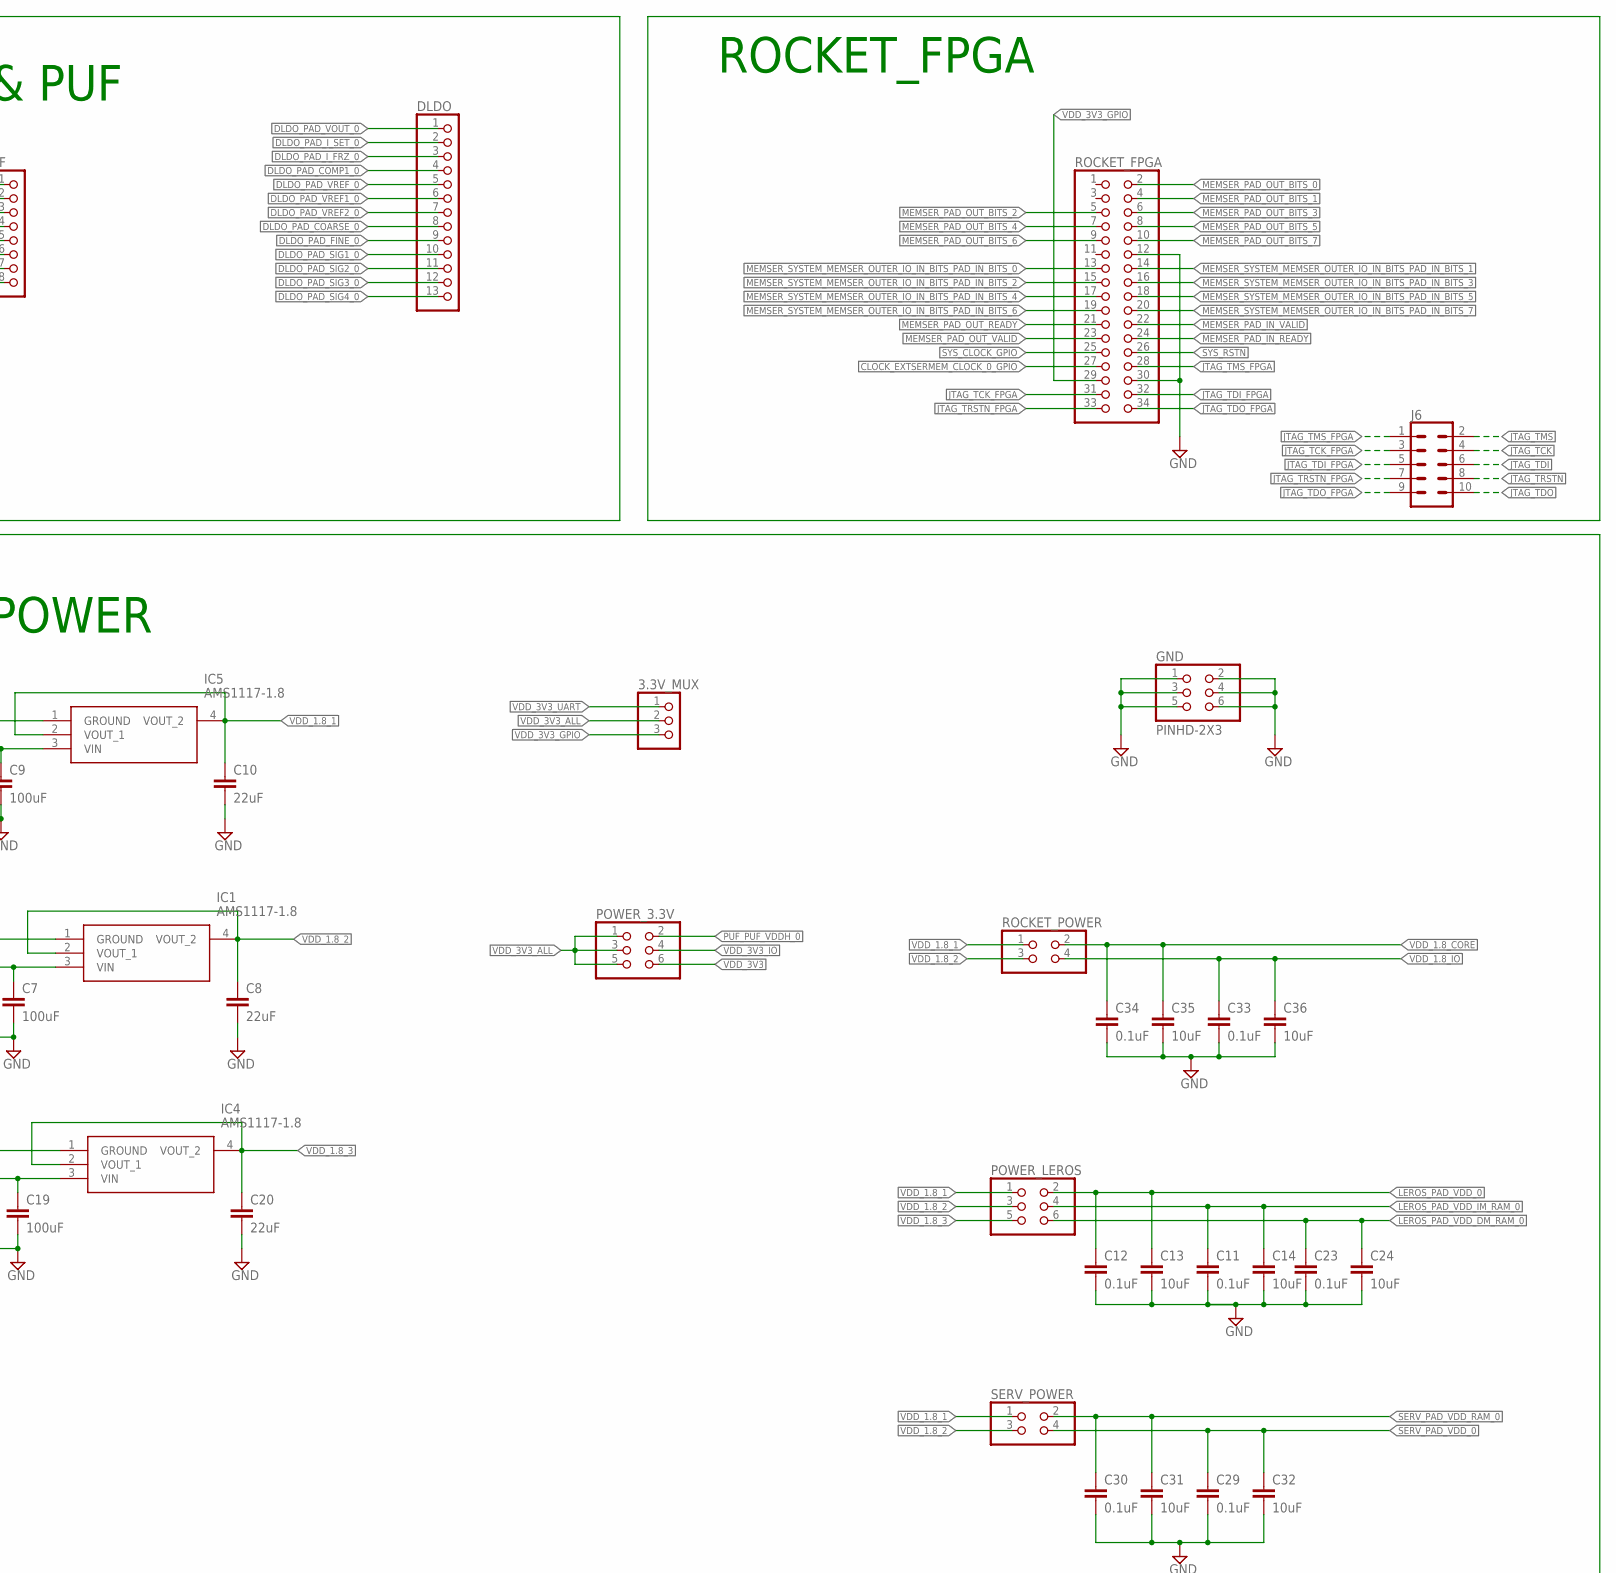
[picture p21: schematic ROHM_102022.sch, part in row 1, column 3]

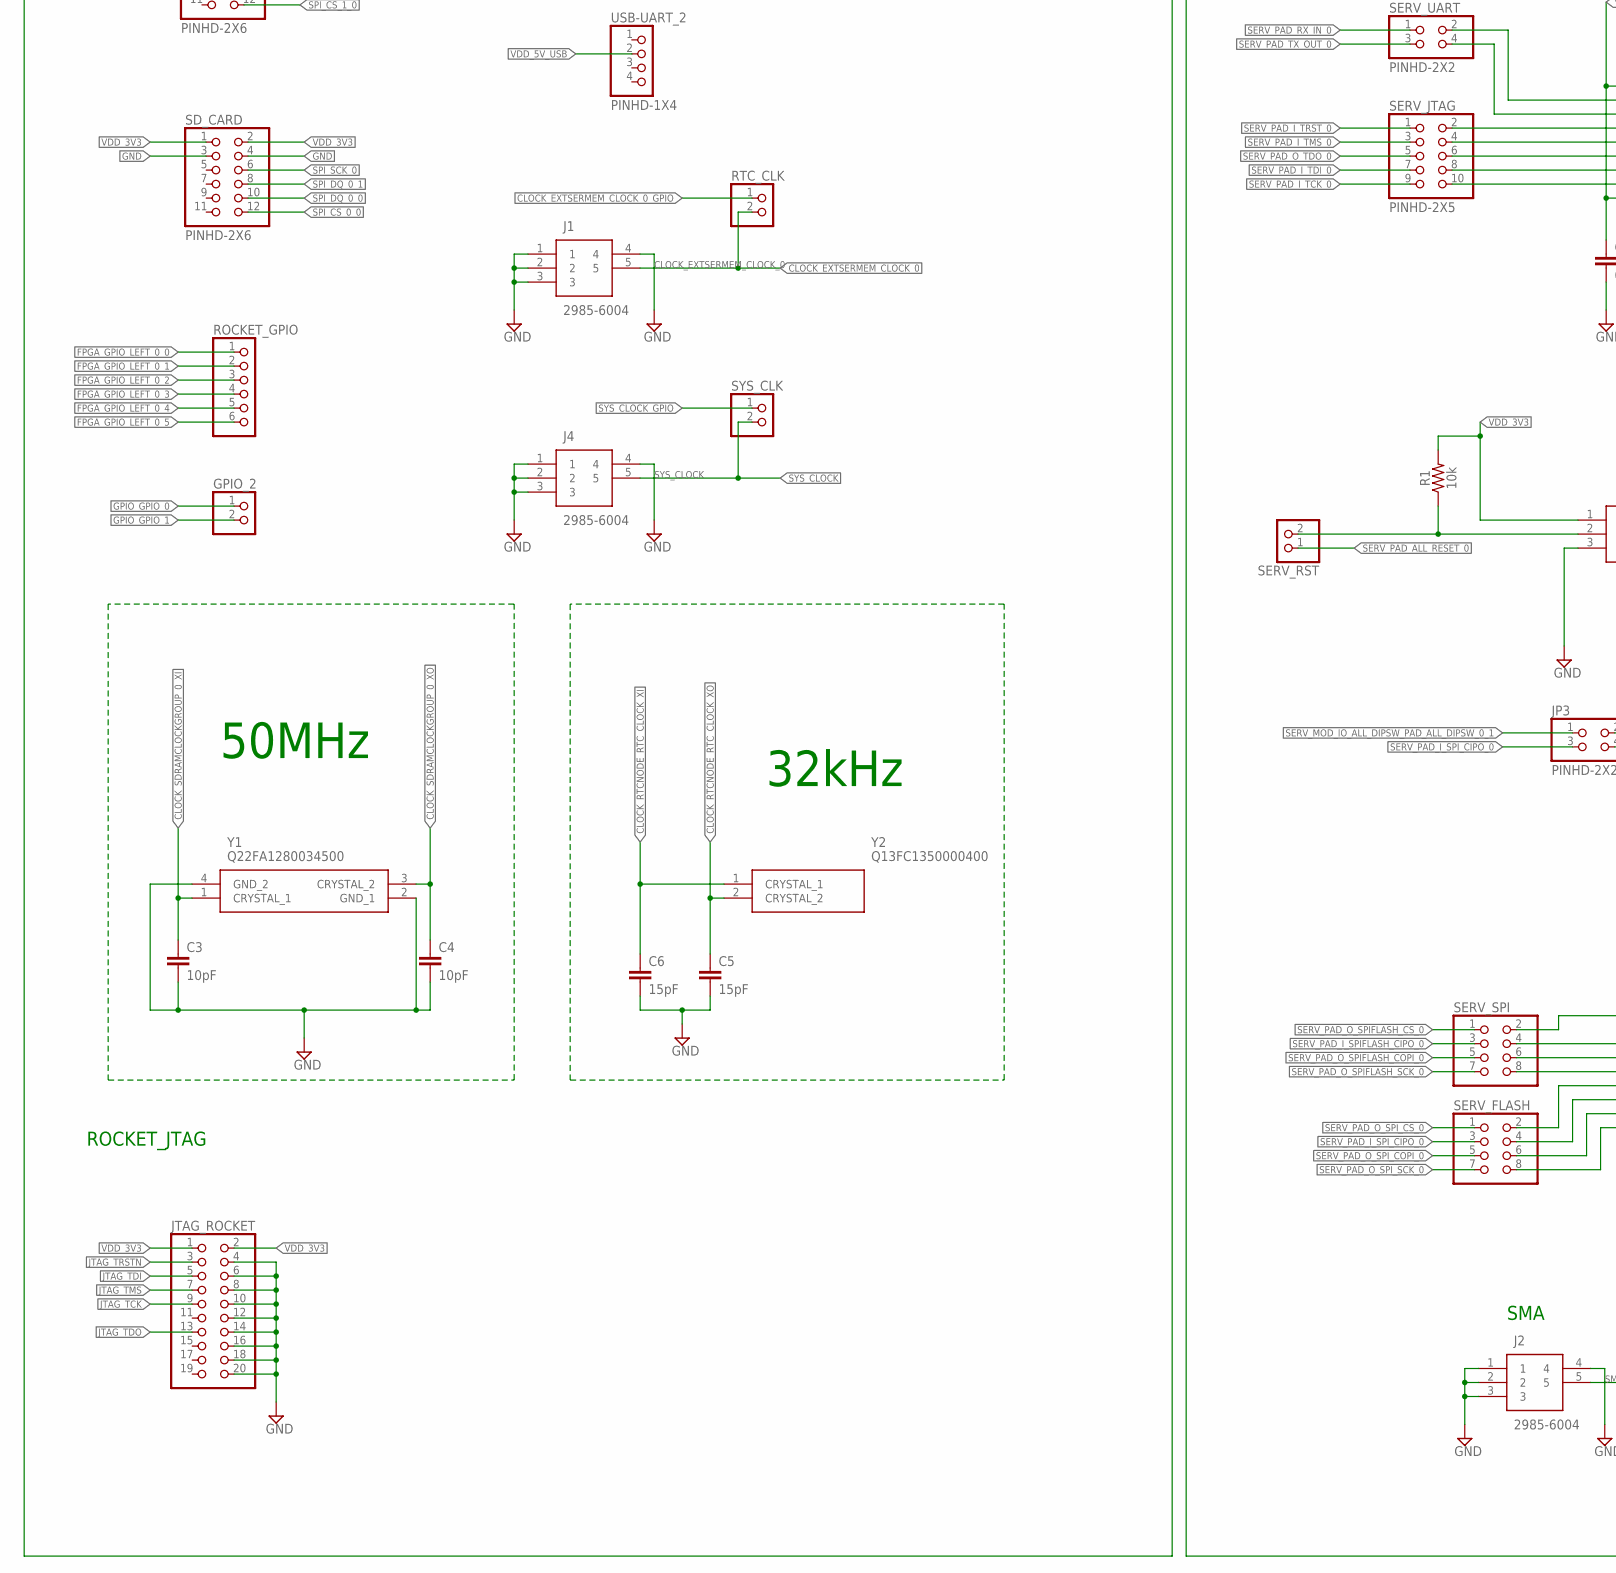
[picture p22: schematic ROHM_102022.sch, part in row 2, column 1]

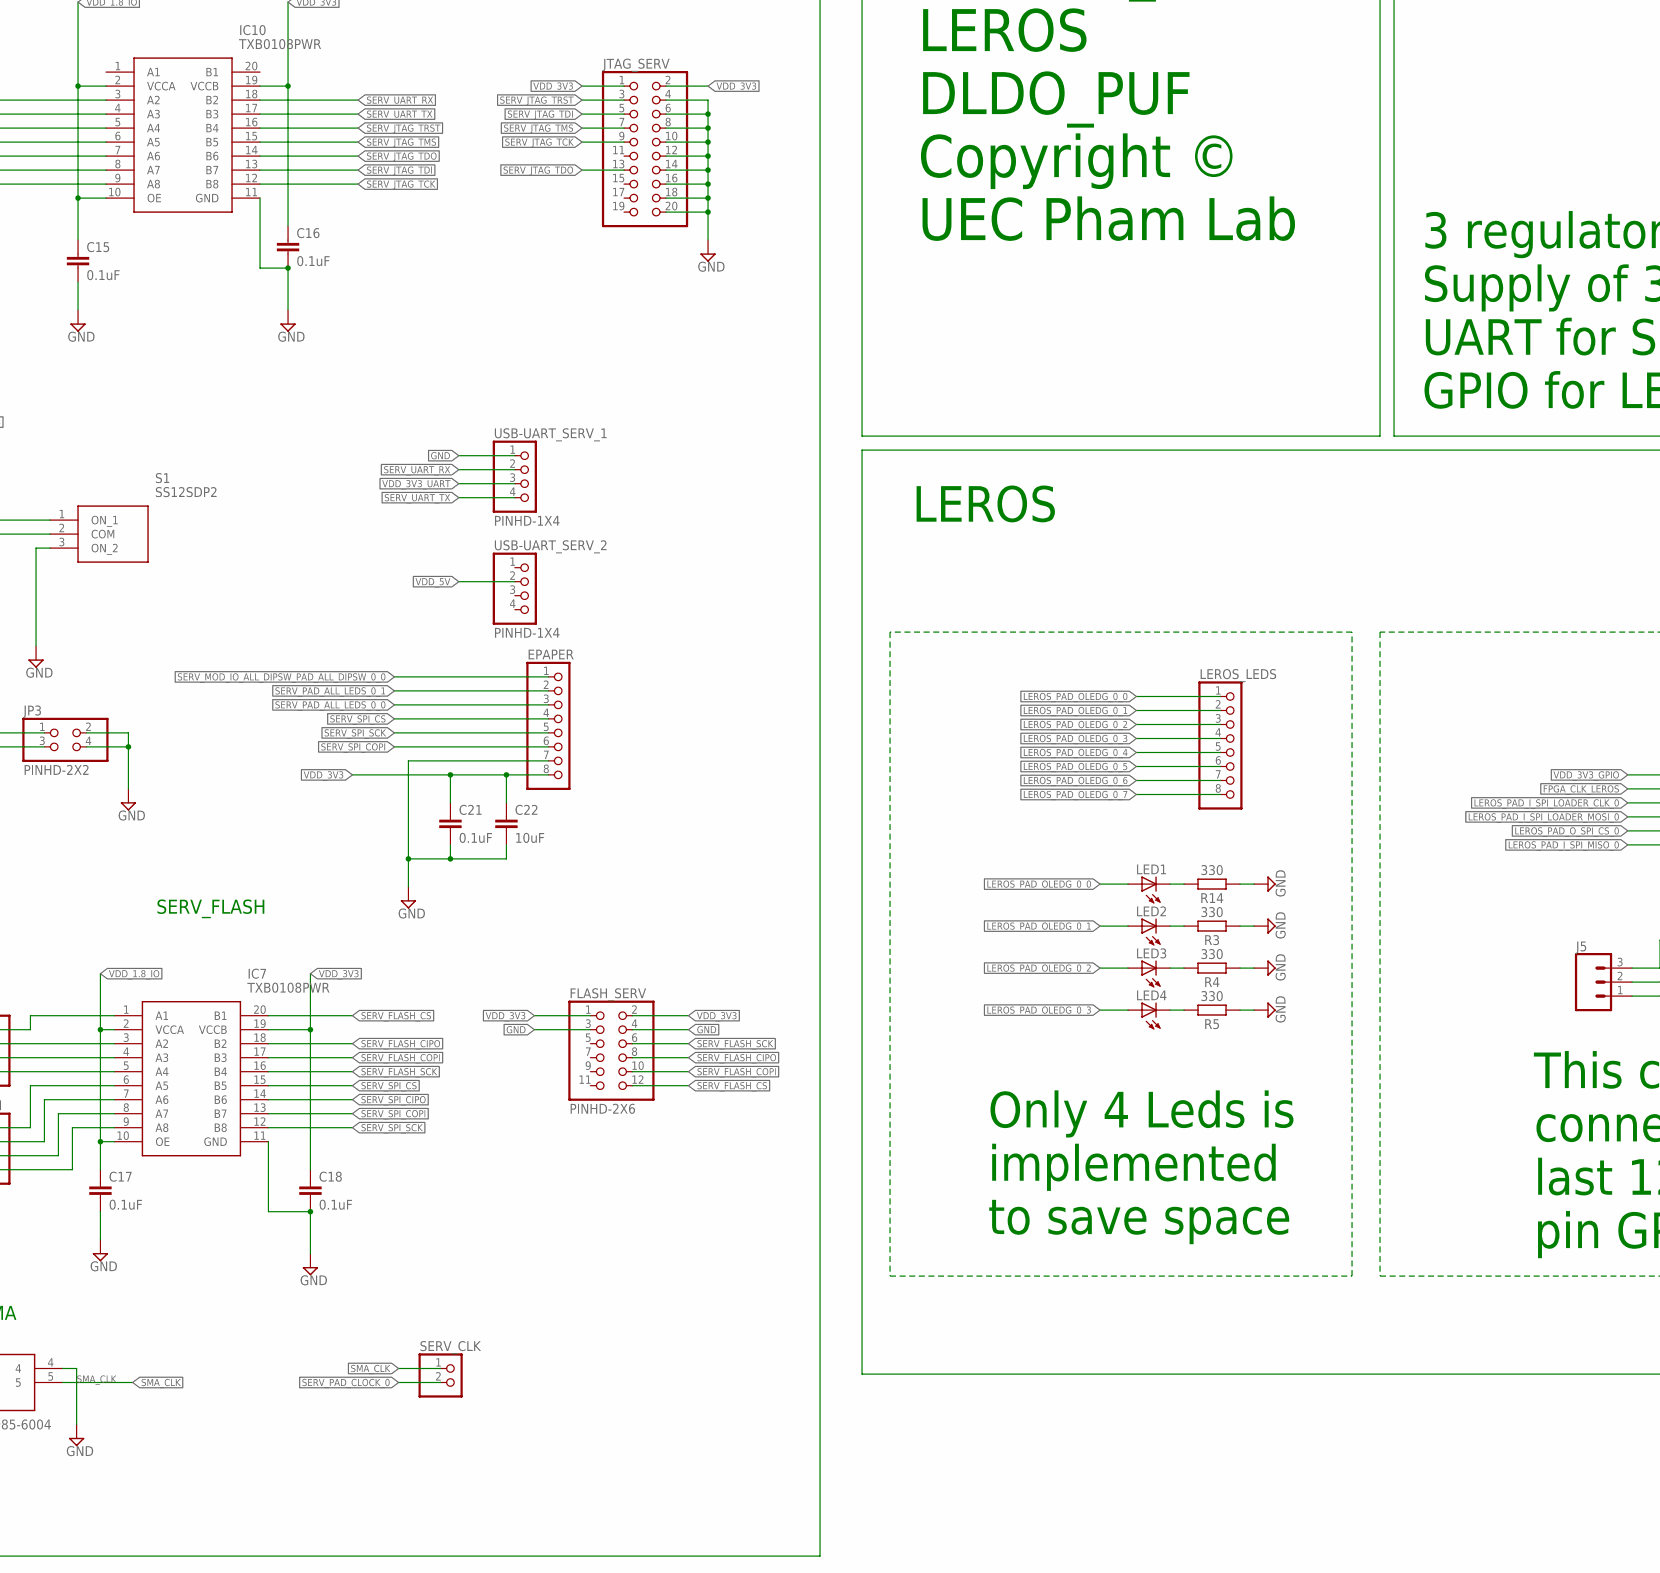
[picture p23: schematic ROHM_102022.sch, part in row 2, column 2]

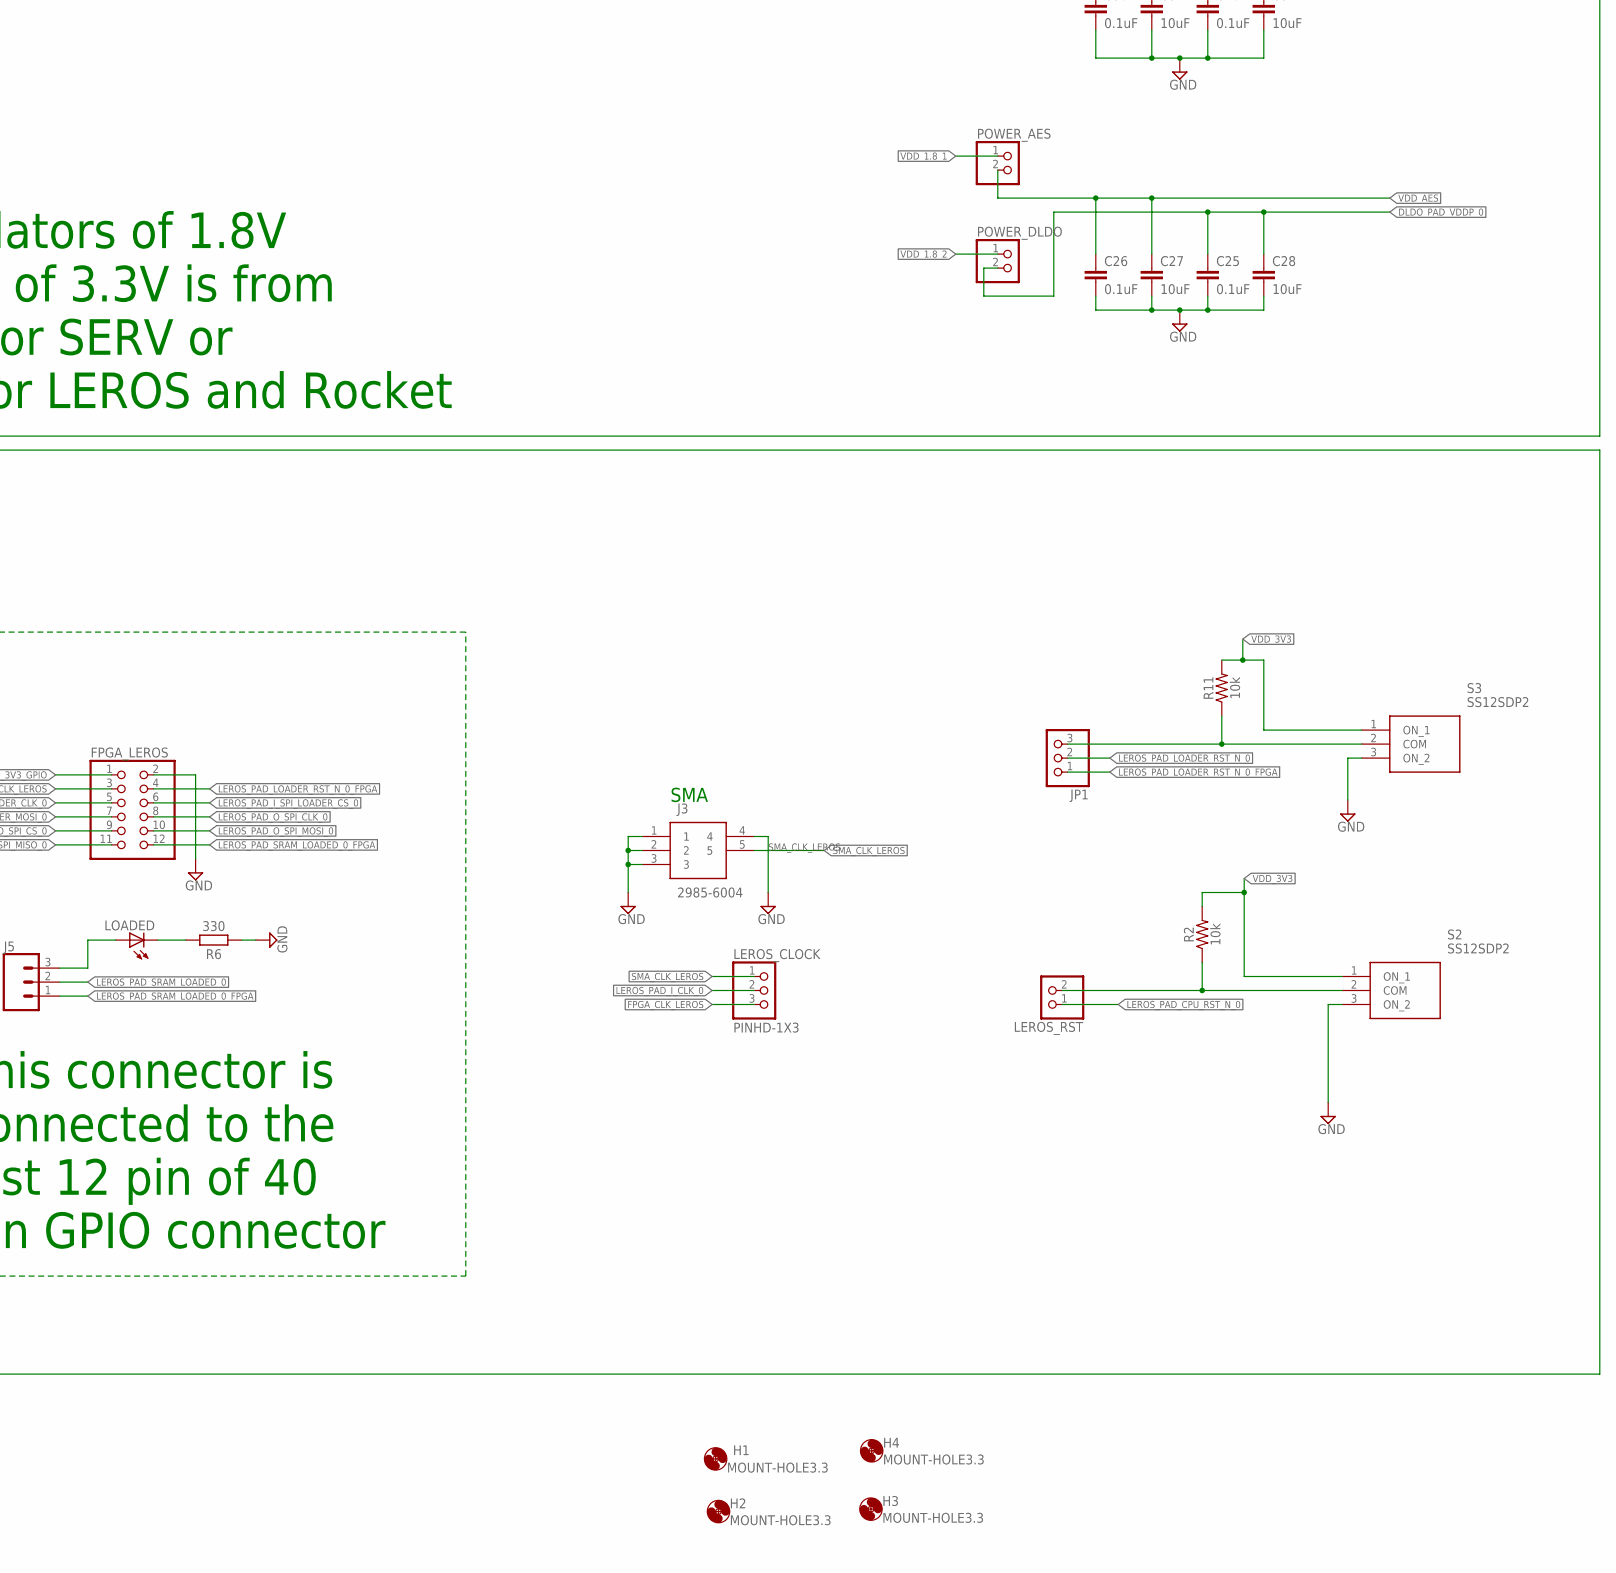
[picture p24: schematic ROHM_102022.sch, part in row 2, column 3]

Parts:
3.3V_MUX: PINHD-1X3; 1X03
C3, C4: 10pF; 1206
C5, C6: 15pF; 1206
C7, C9, C19: 100uF; 1206
C8, C10, C20: 22uF; 1206
C11, C12, C15, C16, C17, C18, C21, C23, C25, C26, C29, C30, C33, C34, C37, C38, C39, C40, C41, C42: 0.1uF; 1206
C13, C14, C22, C24, C27, C28, C31, C32, C35, C36: 10uF; 1206
DLDO: PINHD-1X13; 1X13
EPAPER: PINHD-1X8; 1X08
FLASH: PINHD-2X6; 2X06
FLASH_SERV: PINHD-2X6; 2X06
FPGA_LEROS: PINHD-2X6; 2X06
GND: PINHD-2X3; 2X03
GPIO_2: PINHD-1X2; 1X02
H1, H2, H3, H4: MOUNT-HOLE3.3; 3,3
IC1, IC4, IC5: AMS1117-1.8; SOT229P700X180-4N
IC3: W9825G6KH-6I; SOP80P1176X120-54N
IC7, IC10: TXB0108PWR; SOP65P640X120-20N
J1, J2, J3, J4: 2985-6004; 29856004
J5: CONN_03; 1X03
J6: CONN_05X2PTH; 2X5
JP1: PINHD-1X3; 1X03
JP3: PINHD-2X2; 2X02
JTAG_ROCKET: PINHD-2X10; 2X10
JTAG_SERV: PINHD-2X10; 2X10
LED1, LED2, LED3, LED4: LEDCHIPLED_0805; CHIPLED_0805
LEROS_CLOCK: PINHD-1X3; 1X03
LEROS_LEDS: PINHD-1X8; 1X08
LEROS_RST: PINHD-1X2; 1X02
LOADED: LEDCHIPLED_0805; CHIPLED_0805
POWER_3.3V: PINHD-2X3; 2X03
POWER_AES: PINHD-1X2; 1X02
POWER_DLDO: PINHD-1X2; 1X02
POWER_LEROS: PINHD-2X3; 2X03
PUF: PINHD-1X8; 1X08
R1, R2, R11: 10k; 1206
R3, R4, R5, R6, R14: 330; RESC3216X70
ROCKET_FPGA: PINHD-2X17; 2X17
ROCKET_GPIO: PINHD-1X6; 1X06
ROCKET_POWER: PINHD-2X2; 2X02
RTC_CLK: PINHD-1X2; 1X02
S1, S2, S3: SS12SDP2
SD_CARD: PINHD-2X6; 2X06
SERV_CLK: PINHD-1X2; 1X02
SERV_FLASH: PINHD-2X4; 2X04
SERV_JTAG: PINHD-2X5; 2X05
SERV_POWER: PINHD-2X2; 2X02
SERV_RST: PINHD-1X2; 1X02
SERV_SPI: PINHD-2X4; 2X04
SERV_UART: PINHD-2X2; 2X02
SOCKET_1, SOCKET_2, SOCKET_3, SOCKET_4: 2X26_HEADER
SYS_CLK: PINHD-1X2; 1X02
USB-UART_1, USB-UART_2: PINHD-1X4; 1X04
USB-UART_SERV_1, USB-UART_SERV_2: PINHD-1X4; 1X04
Y1: Q22FA1280034500
Y2: Q13FC1350000400

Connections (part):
CLOCK_EXTSERMEM_CLOCK_0: J1.5, RTC_CLK.2, SOCKET_3.39
CLOCK_EXTSERMEM_CLOCK_0_GPIO: ROCKET_FPGA.27, RTC_CLK.1
CLOCK_RTCNODE_RTC_CLOCK_XI: C6.1, SOCKET_4.33, Y2.1 (CRYSTAL_1)
CLOCK_RTCNODE_RTC_CLOCK_XO: C5.1, SOCKET_4.34, Y2.2 (CRYSTAL_2)
CLOCK_SDRAMCLOCKGROUP_0_XI: C3.1, SOCKET_4.23, Y1.1 (CRYSTAL_1)
CLOCK_SDRAMCLOCKGROUP_0_XO: C4.1, SOCKET_4.24, Y1.3 (CRYSTAL_2)
DLDO_PAD_COARSE_0: DLDO.8, SOCKET_2.3
DLDO_PAD_COMP1_0: DLDO.4, SOCKET_1.47
DLDO_PAD_FINE_0: DLDO.9, SOCKET_2.4
DLDO_PAD_I_FRZ_0: DLDO.3, SOCKET_1.46
DLDO_PAD_I_SET_0: DLDO.2, SOCKET_1.45
DLDO_PAD_SIG1_0: DLDO.10, SOCKET_2.5
DLDO_PAD_SIG2_0: DLDO.11, SOCKET_2.6
DLDO_PAD_SIG3_0: DLDO.12, SOCKET_2.7
DLDO_PAD_SIG4_0: DLDO.13, SOCKET_2.8
DLDO_PAD_VDDP_0: C25.1, C28.1, POWER_DLDO.2, SOCKET_1.43
DLDO_PAD_VDD_0: SOCKET_1.52
DLDO_PAD_VOUT_0: DLDO.1, SOCKET_1.44
DLDO_PAD_VREF1_0: DLDO.6, SOCKET_1.49
DLDO_PAD_VREF2_0: DLDO.7, SOCKET_1.50
DLDO_PAD_VREF_0: DLDO.5, SOCKET_1.48
FPGA_CLK_LEROS: FPGA_LEROS.3, LEROS_CLOCK.3
FPGA_GPIO_LEFT_0_0: ROCKET_GPIO.1, SOCKET_4.30
FPGA_GPIO_LEFT_0_1: ROCKET_GPIO.2, SOCKET_4.29
FPGA_GPIO_LEFT_0_2: ROCKET_GPIO.3, SOCKET_4.28
FPGA_GPIO_LEFT_0_3: ROCKET_GPIO.4, SOCKET_4.27
FPGA_GPIO_LEFT_0_4: ROCKET_GPIO.5, SOCKET_4.26
FPGA_GPIO_LEFT_0_5: ROCKET_GPIO.6, SOCKET_4.25
GND: C3.2, C4.2, C5.2, C6.2, C7.2, C8.2, C9.2, C10.2, C11.2, C12.2, C13.2, C14.2, C15.2, C16.2, C17.2, C18.2, C19.2, C20.2, C21.2, C22.2, C23.2, C24.2, C25.2, C26.2, C27.2, C28.2, C29.2, C30.2, C31.2, C32.2, C33.2, C34.2, C35.2, C36.2, C37.2, C38.2, C39.2, C40.2, C41.2, C42.2, EPAPER.7, FLASH.3, FLASH.4, FLASH_SERV.3, FLASH_SERV.4, FPGA_LEROS.2, GND.1, GND.2, GND.3, GND.4, GND.5, GND.6, IC1.1 (GROUND), IC3.6 (VSSQ_1), IC3.12 (VSSQ_2), IC3.28 (VSS_1), IC3.41 (VSS_2), IC3.46 (VSSQ_3), IC3.52 (VSSQ_4), IC3.54 (VSS_3), IC4.1 (GROUND), IC5.1 (GROUND), IC7.11 (GND), IC10.11 (GND), J1.1, J1.2, J1.3, J1.4, J2.1, J2.2, J2.3, J2.4, J3.1, J3.2, J3.3, J3.4, J4.1, J4.2, J4.3, J4.4, JP3.2, JP3.4, JTAG_ROCKET.4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
GPIO_GPIO_0: GPIO_2.1, SOCKET_3.50
GPIO_GPIO_1: GPIO_2.2, SOCKET_3.49
JTAG_TCK: J6.4, JTAG_ROCKET.9, SOCKET_3.43
JTAG_TCK_FPGA: J6.3, ROCKET_FPGA.31
JTAG_TDI: J6.6, JTAG_ROCKET.5, SOCKET_3.44
JTAG_TDI_FPGA: J6.5, ROCKET_FPGA.32
JTAG_TDO: J6.10, JTAG_ROCKET.13, SOCKET_3.46
JTAG_TDO_FPGA: J6.9, ROCKET_FPGA.34
JTAG_TMS: J6.2, JTAG_ROCKET.7, SOCKET_3.40
JTAG_TMS_FPGA: J6.1, ROCKET_FPGA.28
JTAG_TRSTN: J6.8, JTAG_ROCKET.3, SOCKET_3.45
JTAG_TRSTN_FPGA: J6.7, ROCKET_FPGA.33
LEROS_PAD_CPU_RST_N_0: LEROS_RST.1, SOCKET_2.37
LEROS_PAD_I_CLK_0: LEROS_CLOCK.2, SOCKET_2.36
LEROS_PAD_I_SPI_LOADER_CLK_0: FPGA_LEROS.5, SOCKET_2.49
LEROS_PAD_I_SPI_LOADER_CS_0: FPGA_LEROS.6, SOCKET_2.50
LEROS_PAD_I_SPI_LOADER_MOSI_0: FPGA_LEROS.7, SOCKET_3.3
LEROS_PAD_I_SPI_MISO_0: FPGA_LEROS.11, SOCKET_3.7
LEROS_PAD_LOADER_RST_N_0: JP1.2, SOCKET_2.38
LEROS_PAD_LOADER_RST_N_0_FPGA: FPGA_LEROS.4, JP1.1
LEROS_PAD_OLEDG_0_0: LED1.A, LEROS_LEDS.1, SOCKET_2.39
LEROS_PAD_OLEDG_0_1: LED2.A, LEROS_LEDS.2, SOCKET_2.40
LEROS_PAD_OLEDG_0_2: LED3.A, LEROS_LEDS.3, SOCKET_2.43
LEROS_PAD_OLEDG_0_3: LED4.A, LEROS_LEDS.4, SOCKET_2.44
LEROS_PAD_OLEDG_0_4: LEROS_LEDS.5, SOCKET_2.45
LEROS_PAD_OLEDG_0_5: LEROS_LEDS.6, SOCKET_2.46
LEROS_PAD_OLEDG_0_6: LEROS_LEDS.7, SOCKET_2.47
LEROS_PAD_OLEDG_0_7: LEROS_LEDS.8, SOCKET_2.48
LEROS_PAD_O_SPI_CLK_0: FPGA_LEROS.8, SOCKET_3.4
LEROS_PAD_O_SPI_CS_0: FPGA_LEROS.9, SOCKET_3.5
LEROS_PAD_O_SPI_MOSI_0: FPGA_LEROS.10, SOCKET_3.6
LEROS_PAD_SRAM_LOADED_0: J5.2, SOCKET_3.8
LEROS_PAD_SRAM_LOADED_0_FPGA: FPGA_LEROS.12, J5.1
LEROS_PAD_VDD_0: C12.1, C13.1, POWER_LEROS.2, SOCKET_2.52
LEROS_PAD_VDD_DM_RAM_0: C23.1, C24.1, POWER_LEROS.6, SOCKET_3.11
LEROS_PAD_VDD_IM_RAM_0: C11.1, C14.1, POWER_LEROS.4, SOCKET_3.9
MEMSER_PAD_IN_READY: ROCKET_FPGA.24, SOCKET_3.36
MEMSER_PAD_IN_VALID: ROCKET_FPGA.22, SOCKET_3.34
MEMSER_PAD_OUT_BITS_0: ROCKET_FPGA.2, SOCKET_3.13
MEMSER_PAD_OUT_BITS_1: ROCKET_FPGA.4, SOCKET_3.14
MEMSER_PAD_OUT_BITS_2: ROCKET_FPGA.5, SOCKET_3.15
MEMSER_PAD_OUT_BITS_3: ROCKET_FPGA.6, SOCKET_3.16
MEMSER_PAD_OUT_BITS_4: ROCKET_FPGA.7, SOCKET_3.17
MEMSER_PAD_OUT_BITS_5: ROCKET_FPGA.8, SOCKET_3.18
MEMSER_PAD_OUT_BITS_6: ROCKET_FPGA.9, SOCKET_3.19
MEMSER_PAD_OUT_BITS_7: ROCKET_FPGA.10, SOCKET_3.20
MEMSER_PAD_OUT_READY: ROCKET_FPGA.21, SOCKET_3.33
MEMSER_PAD_OUT_VALID: ROCKET_FPGA.23, SOCKET_3.35
MEMSER_SYSTEM_MEMSER_OUTER_IO_IN_BITS_PAD_IN_BITS_0: ROCKET_FPGA.13, SOCKET_3.23
MEMSER_SYSTEM_MEMSER_OUTER_IO_IN_BITS_PAD_IN_BITS_1: ROCKET_FPGA.14, SOCKET_3.24
MEMSER_SYSTEM_MEMSER_OUTER_IO_IN_BITS_PAD_IN_BITS_2: ROCKET_FPGA.15, SOCKET_3.25
MEMSER_SYSTEM_MEMSER_OUTER_IO_IN_BITS_PAD_IN_BITS_3: ROCKET_FPGA.16, SOCKET_3.26
MEMSER_SYSTEM_MEMSER_OUTER_IO_IN_BITS_PAD_IN_BITS_4: ROCKET_FPGA.17, SOCKET_3.27
MEMSER_SYSTEM_MEMSER_OUTER_IO_IN_BITS_PAD_IN_BITS_5: ROCKET_FPGA.18, SOCKET_3.28
MEMSER_SYSTEM_MEMSER_OUTER_IO_IN_BITS_PAD_IN_BITS_6: ROCKET_FPGA.19, SOCKET_3.29
MEMSER_SYSTEM_MEMSER_OUTER_IO_IN_BITS_PAD_IN_BITS_7: ROCKET_FPGA.20, SOCKET_3.30
unnamed: IC7.1 (A1), SERV_SPI.2
unnamed: LED1.C, R14.2
unnamed: IC7.3 (A2), SERV_SPI.4
unnamed: IC7.4 (A3), SERV_SPI.6
unnamed: IC7.5 (A4), SERV_SPI.8
unnamed: JP1.3, R11.1, S3.2 (COM)
unnamed: LED2.C, R3.2
unnamed: LED3.C, R4.2
unnamed: LED4.C, R5.2
unnamed: IC7.6 (A5), SERV_FLASH.2
unnamed: IC7.7 (A6), SERV_FLASH.4
unnamed: IC7.8 (A7), SERV_FLASH.6
unnamed: IC7.9 (A8), SERV_FLASH.8
unnamed: LOADED.C, R6.2
unnamed: J5.3, LOADED.A
unnamed: IC10.9 (A8), SERV_JTAG.10
unnamed: IC10.8 (A7), SERV_JTAG.8
unnamed: IC10.7 (A6), SERV_JTAG.6
unnamed: IC10.6 (A5), SERV_JTAG.4
unnamed: IC10.5 (A4), SERV_JTAG.2
unnamed: IC10.4 (A3), SERV_UART.4
unnamed: IC10.3 (A2), SERV_UART.2
PUF_PUF_TG_0_0: PUF.1, SOCKET_1.33
PUF_PUF_TG_0_1: PUF.2, SOCKET_1.34
PUF_PUF_TG_0_2: PUF.3, SOCKET_1.35
PUF_PUF_TG_0_3: PUF.4, SOCKET_1.36
PUF_PUF_TG_0_4: PUF.5, SOCKET_1.37
PUF_PUF_TG_0_5: PUF.6, SOCKET_1.38
PUF_PUF_TG_0_6: PUF.7, SOCKET_1.39
PUF_PUF_TG_0_7: PUF.8, SOCKET_1.40
PUF_PUF_VDDH_0: POWER_3.3V.2, SOCKET_1.30
RST_SW: R1.1, S1.2 (COM), SERV_RST.2
RST_SW1: LEROS_RST.2, R2.1, S2.2 (COM)
SDRAMIO_SDRAM_ADDR_O_0: IC3.23 (A0), SOCKET_1.13
SDRAMIO_SDRAM_ADDR_O_1: IC3.24 (A1), SOCKET_1.14
SDRAMIO_SDRAM_ADDR_O_2: IC3.25 (A2), SOCKET_1.15
SDRAMIO_SDRAM_ADDR_O_3: IC3.26 (A3), SOCKET_1.16
SDRAMIO_SDRAM_ADDR_O_4: IC3.29 (A4), SOCKET_1.17
SDRAMIO_SDRAM_ADDR_O_5: IC3.30 (A5), SOCKET_1.18
SDRAMIO_SDRAM_ADDR_O_6: IC3.31 (A6), SOCKET_1.19
SDRAMIO_SDRAM_ADDR_O_7: IC3.32 (A7), SOCKET_1.20
SDRAMIO_SDRAM_ADDR_O_8: IC3.33 (A8), SOCKET_1.23
SDRAMIO_SDRAM_ADDR_O_9: IC3.34 (A9), SOCKET_1.24
SDRAMIO_SDRAM_ADDR_O_10: IC3.22 (A10/AP), SOCKET_1.25
SDRAMIO_SDRAM_ADDR_O_11: IC3.35 (A11), SOCKET_1.26
SDRAMIO_SDRAM_ADDR_O_12: IC3.36 (A12), SOCKET_1.27
SDRAMIO_SDRAM_BA_O_0: IC3.21 (BS1), SOCKET_1.28
SDRAMIO_SDRAM_BA_O_1: IC3.20 (BS0), SOCKET_1.29
SDRAMIO_SDRAM_CAS_O: IC3.17 (!CAS), SOCKET_1.7
SDRAMIO_SDRAM_CKE_O: IC3.37 (CKE), SOCKET_1.4
SDRAMIO_SDRAM_CLK_O: IC3.38 (CLK), SOCKET_1.3
SDRAMIO_SDRAM_CS_O: IC3.19 (!CS), SOCKET_1.5
SDRAMIO_SDRAM_DQM_O_0: IC3.15 (LDQM), SOCKET_1.9
SDRAMIO_SDRAM_DQM_O_1: IC3.39 (UDQM), SOCKET_1.10
SDRAMIO_SDRAM_RAS_O: IC3.18 (!RAS), SOCKET_1.6
SDRAMIO_SDRAM_WE_O: IC3.16 (!WE), SOCKET_1.8
SDRAMIO_SYSTEM_SDRAM_0_SDRAM_DATA_I_SDRAM_DATA_0: IC3.2 (DQ0), SOCKET_4.20
SDRAMIO_SYSTEM_SDRAM_0_SDRAM_DATA_I_SDRAM_DATA_1: IC3.4 (DQ1), SOCKET_4.19
SDRAMIO_SYSTEM_SDRAM_0_SDRAM_DATA_I_SDRAM_DATA_2: IC3.5 (DQ2), SOCKET_4.18
SDRAMIO_SYSTEM_SDRAM_0_SDRAM_DATA_I_SDRAM_DATA_3: IC3.7 (DQ3), SOCKET_4.17
SDRAMIO_SYSTEM_SDRAM_0_SDRAM_DATA_I_SDRAM_DATA_4: IC3.8 (DQ4), SOCKET_4.16
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

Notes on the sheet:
SERV_JTAG
SERV_FLASH
SMA
SERV
LEROS
SOCKET
MEMORY
DLDO & PUF
ROCKET_FPGA
POWER
ROCKET
ROHM 2022 ROCKET_SERV LEROS DLDO_PUF Copyright © UEC Pham Lab
W9825G6KH-6I SDRAM from Winbond 32MB
3 regulators of 1.8V Supply of 3.3V is from UART for SERV or GPIO for LEROS and Rocket
Only 4 Leds is implemented to save space
This connector is connected to the last 12 pin of 40 pin GPIO connector
50MHz
32kHz
ROCKET_JTAG

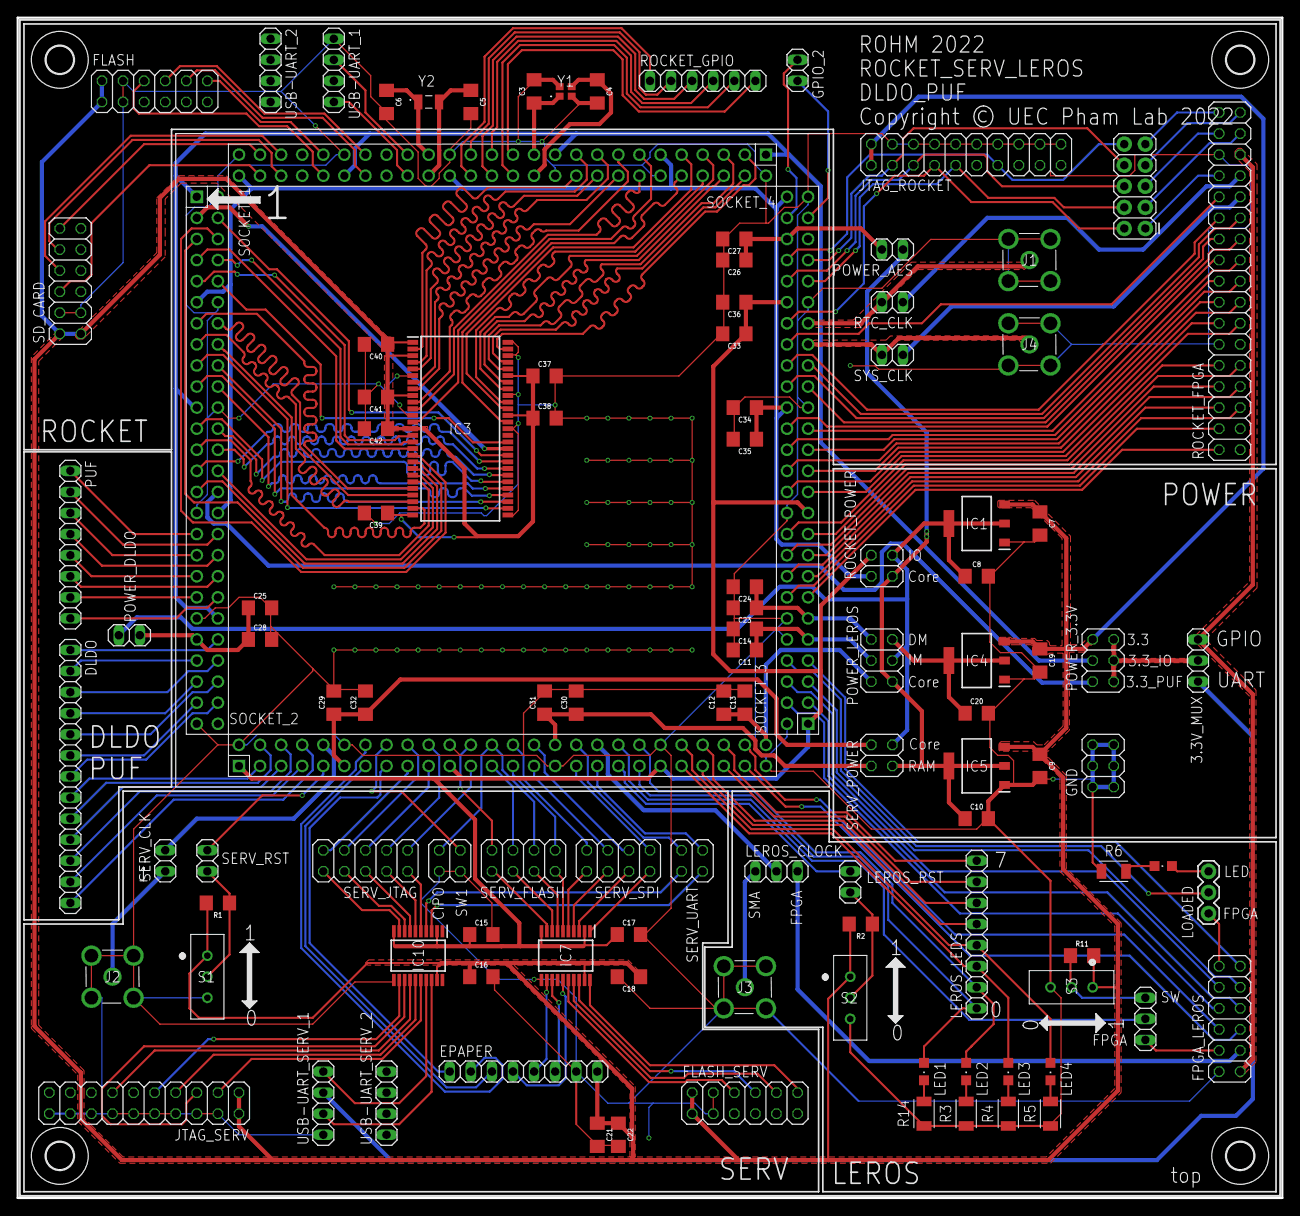
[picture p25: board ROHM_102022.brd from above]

Board: 2 copper layers, 152.4 x 142.2 mm, 115 parts (0 on the bottom side), 219 nets.

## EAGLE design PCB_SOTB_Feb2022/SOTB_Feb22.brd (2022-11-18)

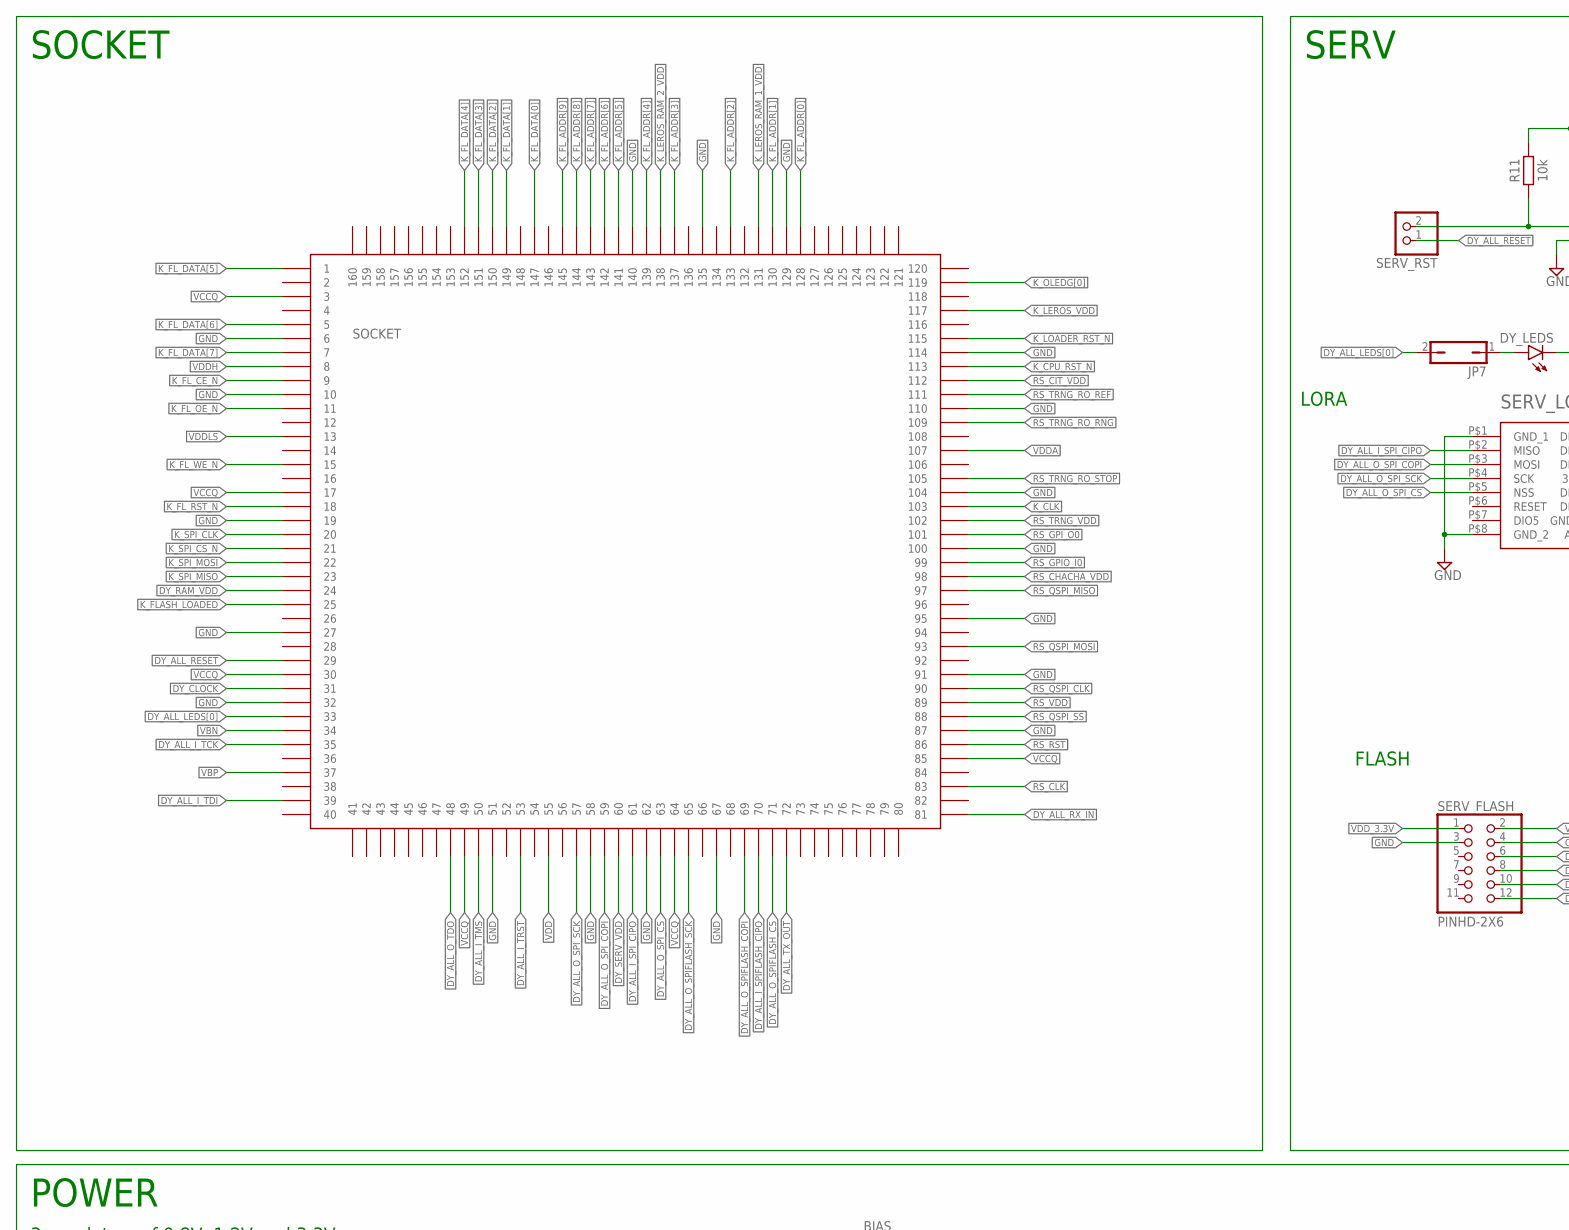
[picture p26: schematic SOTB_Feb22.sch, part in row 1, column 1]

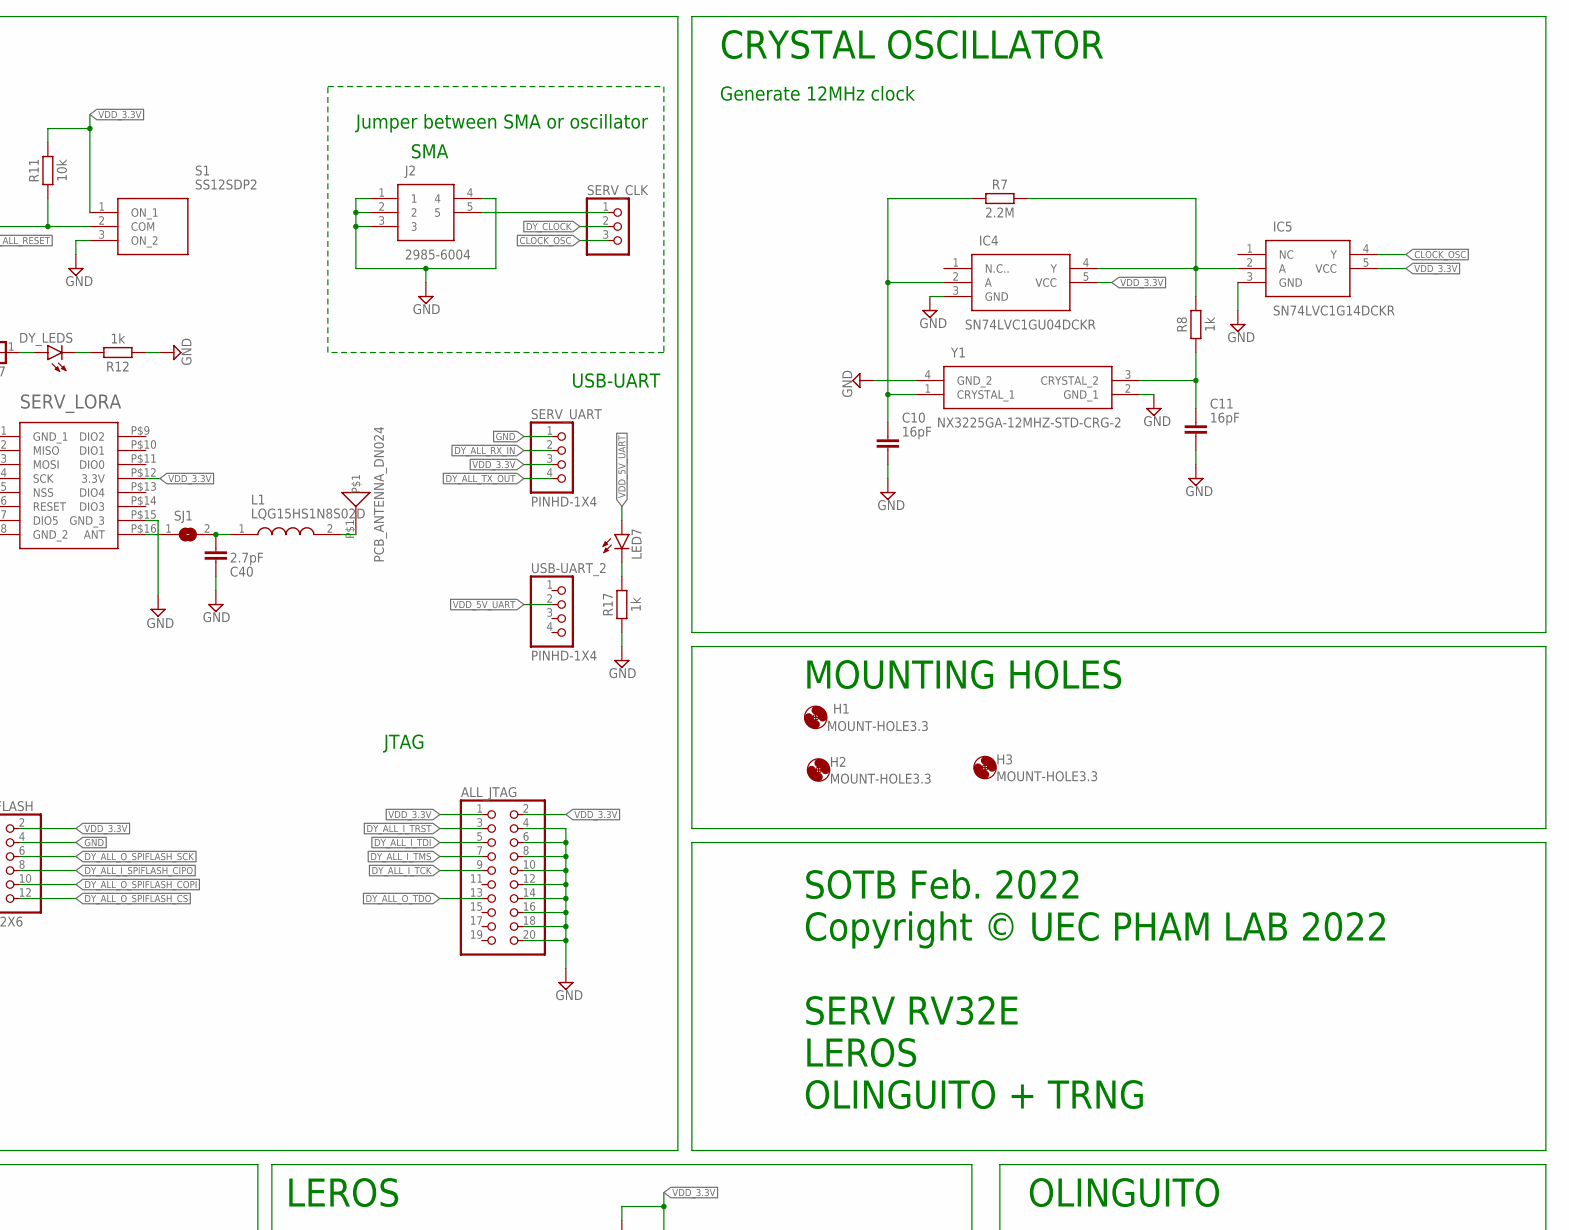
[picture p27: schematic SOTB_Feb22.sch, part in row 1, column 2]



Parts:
ALL_JTAG: PINHD-2X10; 2X10
BIAS: PINHD-2X3; 2X03
C1, C3, C4, C6, C7, C9, C12, C14, C16, C18, C20, C22, C24, C26, C28, C30, C32, C34, C36, C38: 10uF; CAPC3216X135
C2: 4.7nF; CAPC3216X135
C5: 3.3nF; CAPC3216X135
C8: 2.7nF; CAPC3216X135
C10, C11: 16pF; CAPC3216X135
C13, C15, C17, C19, C21, C23, C25, C27, C29, C31, C33, C35, C37, C39: 0.1uF; CAPC3216X135
C40: 2.7pF; CAPC3216X135
CHIP: PINHD-2X4; 2X04
DY_LEDS: LEDCHIPLED_1206; CHIPLED_1206
GND: PINHD-1X3; 1X03
H1, H2, H3: MOUNT-HOLE3.3; 3,3
IC1, IC2, IC3: LP38511MR-ADJ_NOPB; SOIC127P600X170-9N
IC4: SN74LVC1GU04DCKR; SOT65P210X110-5N
IC5: SN74LVC1G14DCKR; SOT65P210X110-5N
J1, J2: 2985-6004; 29856004
JP6, JP7: JP1Q; JP1
K_CPU_RST: PINHD-1X3; 1X03
K_LD_RST: PINHD-1X3; 1X03
K_OLEDG[0]: LEDCHIPLED_1206; CHIPLED_1206
L1: LQG15HS1N8S02D; LQG15WH0N7B02D
LED3, LED4, LED5, LED6, LED7: LEDCHIPLED_1206; CHIPLED_1206
LEROS: PINHD-2X3; 2X03
LEROS_FPGA: PINHD-2X20; 2X20
LEROS_LORA: RFM95W-915S2
POWER_IN: PINHD-1X3; 1X03
R1: 1.07k; RESC3216X70
R2: 1.78k; RESC3216X70
R3: 1.4k; RESC3216X70
R4, R8, R12, R14, R16, R17, R18: 1k; RESC3216X70
R5: 2k; RESC3216X70
R6: 357; RESC3216X70
R7: 2.2M; RESC3216X70
R9, R11, R13, R15: 10k; RESC3216X70
R10: 100; RESC3216X70
R20: 330; RESC3216X70
RS_CLK: PINHD-1X3; 1X03
RS_FLASH: PINHD-2X6; 2X06
RS_RST: PINHD-1X2; 1X02
RS_TRNG: PINHD-1X3; 1X03
RS_UART: PINHD-1X4; 1X04
S1, S2, S3, S4: SS12SDP2
SERV: PINHD-2X2; 2X02
SERV_CLK: PINHD-1X3; 1X03
SERV_FLASH: PINHD-2X6; 2X06
SERV_LORA: RFM95W-915S2
SERV_RST: PINHD-1X2; 1X02
SERV_UART: PINHD-1X4; 1X04
SJ1: SJ
SOCKET: QFP28-160PIN
TRNG: PINHD-2X3; 2X03
U$1: 868MHZA_ANTENNA_DN024; 868MHZ_ANTENNA_DN024
USB-UART_2, USB-UART_4: PINHD-1X4; 1X04
Y1: NX3225GA-12MHZ-STD-CRG-2; NX3225GA12MHZSTDCRG2

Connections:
CLOCK_OSC: IC5.4 (Y), RS_CLK.3, SERV_CLK.3
DY_ALL_I_SPIFLASH_CIPO: SERV_FLASH.8, SOCKET.P$70 (70)
DY_ALL_I_SPI_CIPO: SERV_LORA.P$2 (MISO), SOCKET.P$61 (61)
DY_ALL_I_TCK: ALL_JTAG.9, SOCKET.P$35 (35)
DY_ALL_I_TDI: ALL_JTAG.5, SOCKET.P$39 (39)
DY_ALL_I_TMS: ALL_JTAG.7, SOCKET.P$50 (50)
DY_ALL_I_TRST: ALL_JTAG.3, SOCKET.P$53 (53)
DY_ALL_LEDS[0]: JP7.2, SOCKET.P$33 (33)
DY_ALL_O_SPIFLASH_COPI: SERV_FLASH.10, SOCKET.P$69 (69)
DY_ALL_O_SPIFLASH_CS: SERV_FLASH.12, SOCKET.P$71 (71)
DY_ALL_O_SPIFLASH_SCK: SERV_FLASH.6, SOCKET.P$65 (65)
DY_ALL_O_SPI_COPI: SERV_LORA.P$3 (MOSI), SOCKET.P$59 (59)
DY_ALL_O_SPI_CS: SERV_LORA.P$5 (NSS), SOCKET.P$63 (63)
DY_ALL_O_SPI_SCK: SERV_LORA.P$4 (SCK), SOCKET.P$57 (57)
DY_ALL_O_TDO: ALL_JTAG.13, SOCKET.P$48 (48)
DY_ALL_RESET: SERV_RST.1, SOCKET.P$29 (29)
DY_ALL_RX_IN: SERV_UART.2, SOCKET.P$81 (81)
DY_ALL_TX_OUT: SERV_UART.4, SOCKET.P$72 (72)
DY_CLOCK: SERV_CLK.2, SOCKET.P$31 (31)
DY_RAM_VDD: C26.1, C27.1, SERV.3, SOCKET.P$24 (24)
DY_SERV_VDD: C24.1, C25.1, SERV.1, SOCKET.P$60 (60)
GND: ALL_JTAG.4, ALL_JTAG.6, ALL_JTAG.8, ALL_JTAG.10, ALL_JTAG.12, ALL_JTAG.14, ALL_JTAG.16, ALL_JTAG.18, ALL_JTAG.20, BIAS.6, C1.2, C3.2, C4.2, C6.2, C7.2, C9.2, C10.2, C11.2, C12.2, C13.2, C14.2, C15.2, C16.2, C17.2, C18.2, C19.2, C20.2, C21.2, C22.2, C23.2, C24.2, C25.2, C26.2, C27.2, C28.2, C29.2, C30.2, C31.2, C32.2, C33.2, C34.2, C35.2, C36.2, C37.2, C38.2, C39.2, C40.2, GND.1, GND.2, GND.3, IC1.5 (GND_1), IC1.9 (GND_2), IC2.5 (GND_1), IC2.9 (GND_2), IC3.5 (GND_1), IC3.9 (GND_2), IC4.3 (GND), IC5.3 (GND), J1.1, J1.2, J1.3, J1.4, J2.1, J2.2, J2.3, J2.4, LEROS_FPGA.12, LEROS_FPGA.30, LEROS_LORA.P$1 (GND_1), LEROS_LORA.P$8 (GND_2), LEROS_LORA.P$15 (GND_3), R2.1, R4.1, R6.1, R10.1, R12.1, R14.1, R16.1, R17.1, R18.1, R20.1, RS_FLASH.3, RS_FLASH.4, RS_UART.1, S1.3 (ON_2), S2.3 (ON_2), S3.3 (ON_2), S4.3 (ON_2), SERV_FLASH.3, SERV_FLASH.4, SERV_LORA.P$1 (GND_1), SERV_LORA.P$8 (GND_2), SERV_LORA.P$15 (GND_3), SERV_UART.1, SOCKET.P$6 (6), SOCKET.P$10 (10), SOCKET.P$19 (19), SOCKET.P$27 (27), SOCKET.P$32 (32), SOCKET.P$51 (51), SOCKET.P$58 (58), SOCKET.P$62 (62), SOCKET.P$67 (67), SOCKET.P$87 (87), SOCKET.P$91 (91), SOCKET.P$95 (95), SOCKET.P$100 (100), SOCKET.P$104 (104), SOCKET.P$110 (110), SOCKET.P$114 (114), SOCKET.P$129 (129), SOCKET.P$135 (135), SOCKET.P$140 (140), Y1.2 (GND_1), Y1.4 (GND_2)
IN_3.3: C1.1, C4.1, C7.1, IC1.6 (EN), IC1.7 (IN_1), IC1.8 (IN_2), IC2.6 (EN), IC2.7 (IN_1), IC2.8 (IN_2), IC3.6 (EN), IC3.7 (IN_1), IC3.8 (IN_2), POWER_IN.2
K_CLK: LEROS_FPGA.32, SOCKET.P$103 (103)
K_CPU_RST_N: K_CPU_RST.2, SOCKET.P$113 (113)
K_CPU_RST_N_FPGA: K_CPU_RST.1, LEROS_FPGA.31
K_FLASH_LOADED: LEROS_FPGA.2, SOCKET.P$25 (25)
K_FL_ADDR[0]: LEROS_FPGA.27, SOCKET.P$128 (128)
K_FL_ADDR[1]: LEROS_FPGA.26, SOCKET.P$130 (130)
K_FL_ADDR[2]: LEROS_FPGA.25, SOCKET.P$133 (133)
K_FL_ADDR[3]: LEROS_FPGA.24, SOCKET.P$137 (137)
K_FL_ADDR[4]: LEROS_FPGA.23, SOCKET.P$139 (139)
K_FL_ADDR[5]: LEROS_FPGA.22, SOCKET.P$141 (141)
K_FL_ADDR[6]: LEROS_FPGA.21, SOCKET.P$142 (142)
K_FL_ADDR[7]: LEROS_FPGA.20, SOCKET.P$143 (143)
K_FL_ADDR[8]: LEROS_FPGA.19, SOCKET.P$144 (144)
K_FL_ADDR[9]: LEROS_FPGA.18, SOCKET.P$145 (145)
K_FL_CE_N: LEROS_FPGA.7, SOCKET.P$9 (9)
K_FL_DATA[0]: LEROS_FPGA.17, SOCKET.P$147 (147)
K_FL_DATA[1]: LEROS_FPGA.16, SOCKET.P$149 (149)
K_FL_DATA[2]: LEROS_FPGA.15, SOCKET.P$150 (150)
K_FL_DATA[3]: LEROS_FPGA.14, SOCKET.P$151 (151)
K_FL_DATA[4]: LEROS_FPGA.13, SOCKET.P$152 (152)
K_FL_DATA[5]: LEROS_FPGA.10, SOCKET.P$1 (1)
K_FL_DATA[6]: LEROS_FPGA.9, SOCKET.P$5 (5)
K_FL_DATA[7]: LEROS_FPGA.8, SOCKET.P$7 (7)
K_FL_OE_N: LEROS_FPGA.6, SOCKET.P$11 (11)
K_FL_RST_N: LEROS_FPGA.4, SOCKET.P$18 (18)
K_FL_WE_N: LEROS_FPGA.5, SOCKET.P$15 (15)
K_LEROS_RAM_1_VDD: C30.1, C31.1, LEROS.3, SOCKET.P$131 (131)
K_LEROS_RAM_2_VDD: C28.1, C29.1, LEROS.1, SOCKET.P$138 (138)
K_LEROS_VDD: C32.1, C33.1, LEROS.5, SOCKET.P$117 (117)
K_LOADER_RST_N: K_LD_RST.2, SOCKET.P$115 (115)
K_LOADER_RST_N_FPGA: K_LD_RST.1, LEROS_FPGA.28
K_OLEDG[0]: JP6.2, SOCKET.P$119 (119)
K_SPI_CLK: LEROS_LORA.P$4 (SCK), SOCKET.P$20 (20)
K_SPI_CS_N: LEROS_LORA.P$5 (NSS), SOCKET.P$21 (21)
K_SPI_MISO: LEROS_LORA.P$2 (MISO), SOCKET.P$23 (23)
K_SPI_MOSI: LEROS_LORA.P$3 (MOSI), SOCKET.P$22 (22)
unnamed: C2.2, IC1.3 (ADJ), R1.2, R2.2
unnamed: C5.2, IC2.3 (ADJ), R3.2, R4.2
unnamed: C8.2, IC3.3 (ADJ), R5.2, R6.2
unnamed: C10.1, IC4.2 (A), R7.1, Y1.1 (CRYSTAL_1)
unnamed: IC4.4 (Y), IC5.2 (A), R7.2, R8.2
unnamed: K_OLEDG[0].C, R14.2
unnamed: DY_LEDS.C, R12.2
unnamed: C11.1, R8.1, Y1.3 (CRYSTAL_2)
unnamed: LED3.C, R10.2
unnamed: LED4.C, R20.2
unnamed: LED5.C, R18.2
unnamed: JP6.1, K_OLEDG[0].A
unnamed: DY_LEDS.A, JP7.1
unnamed: LED6.C, R16.2
unnamed: LED7.C, R17.2
unnamed: C40.1, L1.1, SJ1.2
unnamed: L1.2, U$1.P$1
unnamed: SERV_LORA.P$16 (ANT), SJ1.1
OUT_0.8: C2.1, C3.1, CHIP.6, IC1.1 (OUT_1), IC1.2 (OUT_2), LED3.A, R1.1
OUT_1.2: BIAS.2, BIAS.4, C5.1, C6.1, CHIP.8, IC2.1 (OUT_1), IC2.2 (OUT_2), LED4.A, LEROS.2, LEROS.4, LEROS.6, R3.1, SERV.2, SERV.4, TRNG.2, TRNG.4, TRNG.6
OUT_3.3: C8.1, C9.1, CHIP.2, CHIP.4, IC3.1 (OUT_1), IC3.2 (OUT_2), LED5.A, R5.1
RST_SW: R11.1, S1.2 (COM), SERV_RST.2
RST_SW1: K_CPU_RST.3, R13.1, S2.2 (COM)
RST_SW2: K_LD_RST.3, R15.1, S3.2 (COM)
RST_SW3: R9.1, RS_RST.2, S4.2 (COM)
RS_CHACHA_VDD: SOCKET.P$98 (98)
RS_CIT_VDD: SOCKET.P$112 (112)
RS_CLK: RS_CLK.2, SOCKET.P$83 (83)
RS_GPIO_I0: RS_UART.2, SOCKET.P$99 (99)
RS_GPI_O0: RS_UART.4, SOCKET.P$101 (101)
RS_QSPI_CLK: RS_FLASH.6, SOCKET.P$90 (90)
RS_QSPI_MISO: RS_FLASH.8, SOCKET.P$97 (97)
RS_QSPI_MOSI: RS_FLASH.10, SOCKET.P$93 (93)
RS_QSPI_SS: RS_FLASH.12, SOCKET.P$88 (88)
RS_RST: RS_RST.1, SOCKET.P$86 (86)
RS_TRNG_RO_REF: RS_TRNG.1, SOCKET.P$111 (111)
RS_TRNG_RO_RNG: RS_TRNG.2, SOCKET.P$109 (109)
RS_TRNG_RO_STOP: RS_TRNG.3, SOCKET.P$105 (105)
RS_TRNG_VDD: C36.1, C37.1, SOCKET.P$102 (102), TRNG.3
RS_VDD: C38.1, C39.1, SOCKET.P$89 (89), TRNG.5
SMA_CLK: J2.5, SERV_CLK.1
SMA_CLK1: J1.5, RS_CLK.1
VBN: BIAS.5, C16.1, C17.1, SOCKET.P$34 (34)
VBP: BIAS.3, C14.1, C15.1, SOCKET.P$37 (37)
VCCQ: C18.1, C19.1, CHIP.3, SOCKET.P$3 (3), SOCKET.P$17 (17), SOCKET.P$30 (30), SOCKET.P$49 (49), SOCKET.P$64 (64), SOCKET.P$85 (85)
VDD: BIAS.1, C12.1, C13.1, SOCKET.P$55 (55)
VDDA: C34.1, C35.1, SOCKET.P$107 (107), TRNG.1
VDDH: C22.1, C23.1, CHIP.7, SOCKET.P$8 (8)
VDDLS: C20.1, C21.1, CHIP.5, SOCKET.P$13 (13)
VDD_3.3V: ALL_JTAG.1, ALL_JTAG.2, CHIP.1, IC4.5 (VCC), IC5.5 (VCC), LEROS_LORA.P$12 (3.3V), R9.2, R11.2, R13.2, R15.2, RS_FLASH.1, RS_FLASH.2, RS_UART.3, S1.1 (ON_1), S2.1 (ON_1), S3.1 (ON_1), S4.1 (ON_1), SERV_FLASH.1, SERV_FLASH.2, SERV_LORA.P$12 (3.3V), SERV_UART.3
VDD_3.3V_FPGA: LEROS_FPGA.29
VDD_5V_FPGA: LED6.A, LEROS_FPGA.11, POWER_IN.3
VDD_5V_UART: LED7.A, POWER_IN.1, USB-UART_2.2, USB-UART_4.2

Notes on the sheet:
SMA
FLASH
LORA
USB-UART
JTAG
POWER
SOCKET
SERV
CRYSTAL OSCILLATOR
LEROS
OLINGUITO
3 regulators of 0.8V, 1.2V and 3.3V Input source is 5V from UART (if using SERV or OLINGUITO) or FPGA (if using LEROS) 3.3V: VCCQ and peripherials 1.2V: VDDH, VDD of core and RAM 0.8V: VDDLS Bias voltages: VBN to GND, VBP to 1.2V
SOTB Feb. 2022 Copyright © UEC PHAM LAB 2022 SERV RV32E LEROS OLINGUITO + TRNG
MOUNTING HOLES
Generate 12MHz clock
Jumper between SMA or oscillator


Board: 2 copper layers, 138.4 x 127.0 mm, 111 parts (0 on the bottom side), 109 nets.

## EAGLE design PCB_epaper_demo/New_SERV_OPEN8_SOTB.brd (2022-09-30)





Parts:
0.5V, 0.9V: PINHD-1X3; 1X03
0.5V_IN, 0.9V_IN: PINHD-1X2; 1X02
C1, C3: 1.0uF; 0805
C2: 2.2uF; 0805
C4: 4.7uF; 0805
C5, C6, C7, C8, C10, C11, C26, C28, C32, C35, C37, C39, C41: 10uF; 0805
C9, C12, C27, C33, C34, C36, C38, C40, C42: 0.1uF; 0805
C16: 100uF; 0805
C17: 0.01uF; 0805
EPAPER_1: PINHD-1X8; 1X08
FLASH: PINHD-2X6; 2X06
GND: PINHD-2X3; 2X03
H1, H2, H3: MOUNT-HOLE3.3; 3,3
IC2: LT3082EST#PBF; SOT230P700X180-4N
IC3: RP105x; SOT95P280X145-5N
IC4, IC5: SN74AUP1G00DCKR; SOT65P210X110-5N
IC6: LM358AMX_NOPB; SOIC127P600X175-8N
J1, J2: TB006-508-02BE; TB00650802BE
J3: CONN_03; 1X03
JP1, JP2, JP3: PINHD-2X20; 2X20
LED: CONN_01; 1X01
MUX: PINHD-1X2; 1X02
POWER: PINHD-2X6; 2X06
R1: 112k; 0805
R2: 550k; 0805
R3, R4: 100k; 0805
R5, R7, R36: 10k; 0805
R6: 2.2k; 0805
R11: 1k; 0805
S1: SS12SDP2
SWITCH: PINHD-2X3; 2X03
U1: SN74LVC1G32DBVR; SOT95P280X145-5N
U3: SN74AUP1G14DBVR; SOT65P210X110-5N
USB-UART_1, USB-UART_2: PINHD-1X4; 1X04
VBN: PINHD-1X2; 1X02
VBP: PINHD-1X2; 1X02
VR1, VR2, VR3: GF063PB103K
WAKEUP: CONN_02; 1X02
Y1: KC7050A48.0000C50D00; KC7050A480000C50D00

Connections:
DR_ALL_DIPSW[0]: EPAPER_1.1, JP1.20
DR_ALL_DIPSW[1]: JP1.22, SWITCH.5
DR_ALL_DIPSW[2]: JP1.24, SWITCH.3
DR_ALL_DIPSW[3]: JP1.25, SWITCH.1
DR_ALL_I_PROG_COPI: JP1.29
DR_ALL_I_PROG_CS: JP1.33
DR_ALL_I_PROG_SCK: JP1.27
DR_ALL_I_SPIFLASH_CIPO: FLASH.8, JP2.30
DR_ALL_I_SPI_CIPO: JP2.21
DR_ALL_I_TCK: JP1.35
DR_ALL_I_TDI: JP1.39
DR_ALL_I_TMS: JP2.10
DR_ALL_I_TRST: JP2.13
DR_ALL_LEDS[0]: EPAPER_1.3, JP1.9
DR_ALL_LEDS[1]: EPAPER_1.2, JP1.11
DR_ALL_LEDS[2]: JP1.15, U3.2 (A)
DR_ALL_LEDS[3]: JP1.18, LED.1
DR_ALL_O_PROG_CIPO: JP1.31
DR_ALL_O_SPIFLASH_COPI: FLASH.10, JP2.29
DR_ALL_O_SPIFLASH_CS: FLASH.12, JP2.31
DR_ALL_O_SPIFLASH_SCK: FLASH.6, JP2.25
DR_ALL_O_SPI_COPI: EPAPER_1.6, JP2.19
DR_ALL_O_SPI_CS: EPAPER_1.4, JP2.23
DR_ALL_O_SPI_SCK: EPAPER_1.5, JP2.17
DR_ALL_O_TDO: JP2.8
DR_ALL_RESET: C16.1, JP1.7, R11.1
DR_ALL_RX_IN: JP3.1, USB-UART_1.2
DR_ALL_TX_OUT: JP2.32, USB-UART_1.4
DR_CLOCK: JP1.1, Y1.3 (OUTPUT)
DR_MUX: JP1.5, MUX.1, R36.2
DR_OPEN8_VDD: C28.1, C33.1, JP1.21, POWER.4
DR_SERV_VDD: JP2.20
DR_VBN: C35.1, C36.1, JP1.34, VBN.1
DR_VBP: C32.1, C34.1, JP1.37, VBP.2
DR_VDD: C26.1, C27.1, JP2.15, POWER.2, VBP.1
GND: C1.2, C2.2, C3.2, C4.2, C5.2, C6.2, C7.2, C8.2, C9.2, C10.2, C11.2, C12.2, C16.2, C17.2, C26.2, C27.2, C28.2, C32.2, C33.2, C34.2, C35.2, C36.2, C37.2, C38.2, C39.2, C40.2, C41.2, C42.2, EPAPER_1.7, FLASH.3, FLASH.4, GND.1, GND.2, GND.3, GND.4, GND.5, GND.6, IC3.2 (B), IC4.3 (GND), IC5.3 (GND), IC6.4 (GND), J1.2, J2.2, JP1.6, JP1.10, JP1.19, JP1.23, JP1.32, JP2.11, JP2.18, JP2.22, JP2.27, JP3.7, JP3.20, MUX.2, R1.2, R3.2, R5.2, S1.3 (ON_2), SWITCH.2, SWITCH.4, SWITCH.6, U1.3 (GND), U3.3 (GND), USB-UART_1.1, VBN.2, VR1.3 (CW), WAKEUP.1, Y1.2 (CASE_GND)
IN_2: 0.5V_IN.2, C1.1, IC3.1 (A)
IN_3: 0.9V_IN.2, C3.1, IC2.3 (IN)
unnamed: IC2.1 (SET), R3.1
unnamed: IC6.3 (NON-INVERTING_INPUT_A), R1.1, R2.2, R4.1, VR1.2 (WIPER), VR2.3 (CW), VR3.3 (CW)
NOT_Q: IC4.4 (Y), IC5.1 (A), U1.1 (A)
NOT_Q_OR_SW: J3.1, U1.4 (Y)
OUT_0.5V: 0.5V.3, C2.1, IC3.5 (VCC)
OUT_0.9V: 0.9V.3, C4.1, IC2.2 (OUT_1), IC2.4 (OUT_2)
POWER_0.5V: 0.5V.2, POWER.1, POWER.3, POWER.5
POWER_0.9V: 0.9V.2, POWER.7
Q: IC4.2 (B), IC5.4 (Y), Y1.1 (!INH)
RESET: IC4.1 (A), R5.1, U3.4 (Y)
RESET_MUX: J3.2, R11.2
RST_SW: J3.3, R7.2, S1.2 (COM), U1.2 (B)
VCCQ: C41.1, C42.1, JP1.3, JP1.17, JP1.30, JP2.9, JP2.24, JP3.5, POWER.10
VDDH: C39.1, C40.1, JP1.8, POWER.8
VDDLS: C37.1, C38.1, JP1.13, POWER.6
VDD_1.2V_IN: 0.5V.1, 0.5V_IN.1, 0.9V.1, J2.1
VDD_3.3V: C5.1, C6.1, C7.1, C8.1, C9.1, C10.1, C17.1, IC4.5 (VCC), IC5.5 (VCC), IC6.8 (V+), POWER.12, R2.1, R6.1, R7.1, R36.1, S1.1 (ON_1), U1.5 (VCC), U3.5 (VCC), VR3.2 (WIPER), Y1.4 (VCC)
VDD_3.3V_IN: 0.9V_IN.1, C11.1, C12.1, EPAPER_1.8, FLASH.1, FLASH.2, IC3.3 (GND), IC3.4 (Y), J1.1, POWER.9, POWER.11
VDD_5V: USB-UART_2.2
WAKEUP_SIGNAL: IC6.2 (INVERTING_INPUT_A), WAKEUP.2
WS_OPAMP: IC5.2 (B), IC6.1 (OUTPUT_A), R4.2, R6.2, VR2.2 (WIPER)

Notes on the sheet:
CLOCK & RESET
Mounting holes
MUX
FLASH
USB-UART
LED
SWITCH
POWER


Board: 2 copper layers, 126.5 x 109.5 mm, 74 parts (0 on the bottom side), 47 nets.

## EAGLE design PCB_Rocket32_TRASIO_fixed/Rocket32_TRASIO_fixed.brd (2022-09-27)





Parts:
3.3V_GPIO: PINHD-1X2; 1X02
C1, C2, C3, C4, C11, C12: 0.1uF; 1206
C5, C9: 100uF; 1206
C6, C10: 22uF; 1206
C13, C14: 10uF; 1206
CHILD_CLK: PINHD-1X2; 1X02
D1, D2, D3, D4: LED1206; LED-1206
FLASH: PINHD-2X6; 2X06
GND: PINHD-2X3; 2X03
GPIO_1, GPIO_2: PINHD-2X20; 2X20
GPIO_IN: PINHD-1X5; 1X05
GPIO_OUT: PINHD-1X5; 1X05
H1, H2, H3, H4: MOUNT-HOLE3.3; 3,3
IC1, IC2: TXB0108PWR; SOP65P640X120-20N
IC3, IC5: AMS1117-1.8; SOT229P700X180-4N
J1, J2, J4, J5: 2985-6004; 29856004
JP1, JP2, JP3, JP4: PINHD-2X20; 2X20
JTAG: PINHD-2X4; 2X04
JTAG_20_PIN: PINHD-2X10; 2X10
POWER: PINHD-2X2; 2X02
POWER_LED: PINHD-2X2; 2X02
Q5, Q6, Q7, Q8: 2N7002K-7; SOT96P240X100-3N
QSPI: PINHD-2X4; 2X04
R10, R12, R14, R16: 10k; 1206
R11, R13, R15, R17: 330; 1206
RTC_CLK: PINHD-1X2; 1X02
SD: PINHD-2X4; 2X04
SDRAM_CLK: PINHD-1X2; 1X02
SD_CARD: PINHD-2X6; 2X06
SYS_CLK: PINHD-1X2; 1X02
UART: PINHD-2X2; 2X02
USB-UART_1, USB-UART_2: PINHD-1X4; 1X04

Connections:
CHILDCLOCK: CHILD_CLK.2, J5.5, JP4.12
CHILDCLOCK_GPIO: CHILD_CLK.1, GPIO_2.40
CLOCK_GPIO: GPIO_2.39, SYS_CLK.1
CS: IC2.13 (B7), SD_CARD.12
EXTSER_IN_BITS[0]: GPIO_1.36, JP2.28
EXTSER_IN_BITS[1]: GPIO_1.35, JP2.26
EXTSER_IN_BITS[2]: GPIO_1.34, JP2.24
EXTSER_IN_BITS[3]: GPIO_1.33, JP2.23
EXTSER_IN_BITS[4]: GPIO_1.32, JP2.22
EXTSER_IN_BITS[5]: GPIO_1.31, JP2.21
EXTSER_IN_BITS[6]: GPIO_1.28, JP2.20
EXTSER_IN_BITS[7]: GPIO_1.27, JP2.19
EXTSER_IN_READY: GPIO_1.25, JP2.17
EXTSER_IN_VALID: GPIO_1.26, JP2.18
EXTSER_OUT_BITS[0]: GPIO_2.8, JP2.40
EXTSER_OUT_BITS[1]: GPIO_2.7, JP2.38
EXTSER_OUT_BITS[2]: GPIO_2.6, JP2.36
EXTSER_OUT_BITS[3]: GPIO_2.5, JP2.35
EXTSER_OUT_BITS[4]: GPIO_2.4, JP2.34
EXTSER_OUT_BITS[5]: GPIO_2.2, JP2.33
EXTSER_OUT_BITS[6]: GPIO_1.40, JP2.32
EXTSER_OUT_BITS[7]: GPIO_1.39, JP2.31
EXTSER_OUT_READY: GPIO_1.37, JP2.29
EXTSER_OUT_VALID: GPIO_1.38, JP2.30
FLASH_CS: FLASH.12, IC1.16 (B4)
FLASH_MISO: FLASH.8, IC1.18 (B2)
FLASH_MOSI: FLASH.10, IC1.20 (B1)
FLASH_QSPI_CS: JP1.19, QSPI.7
FLASH_QSPI_MISO: JP1.21, QSPI.3
FLASH_QSPI_MOSI: JP1.22, QSPI.1
FLASH_QSPI_SCK: JP1.20, QSPI.5
FLASH_SCK: FLASH.6, IC1.17 (B3)
GND: C1.2, C2.2, C3.2, C4.2, C5.2, C6.2, C9.2, C10.2, C11.2, C12.2, C13.2, C14.2, FLASH.3, FLASH.4, GND.1, GND.2, GND.3, GND.4, GND.5, GND.6, GPIO_1.12, GPIO_1.30, GPIO_2.12, GPIO_2.30, IC1.11 (GND), IC2.11 (GND), IC3.1 (GROUND), IC5.1 (GROUND), J1.1, J1.2, J1.3, J1.4, J2.1, J2.2, J2.3, J2.4, J4.1, J4.2, J4.3, J4.4, J5.1, J5.2, J5.3, J5.4, JP1.3, JP1.15, JP1.25, JP1.37, JP2.3, JP2.15, JP2.27, JP2.37, JP3.3, JP3.13, JP3.27, JP3.37, JP4.3, JP4.15, JP4.25, JP4.37, JTAG_20_PIN.4, JTAG_20_PIN.6, JTAG_20_PIN.8, JTAG_20_PIN.10, JTAG_20_PIN.12, JTAG_20_PIN.14, JTAG_20_PIN.16, JTAG_20_PIN.18, JTAG_20_PIN.20, Q5.2 (S), Q6.2 (S), Q7.2 (S), Q8.2 (S), R10.1, R12.1, R14.1, R16.1, SD_CARD.3, SD_CARD.4, USB-UART_1.1
GPIO_IN[0]: GPIO_IN.1, JP1.7
GPIO_IN[1]: GPIO_IN.2, JP1.6
GPIO_IN[2]: GPIO_IN.3, JP1.5
GPIO_IN[3]: GPIO_IN.4, JP1.4
GPIO_IN[4]: GPIO_IN.5, JP1.2
GPIO_OUT[0]: GPIO_OUT.1, JP1.12, Q7.1 (G), R14.2
GPIO_OUT[1]: GPIO_OUT.2, JP1.11
GPIO_OUT[2]: GPIO_OUT.3, JP1.10
GPIO_OUT[3]: GPIO_OUT.4, JP1.9
GPIO_OUT[4]: GPIO_OUT.5, JP1.8
JRST_N: GPIO_2.36, JP4.17
JTAG_TCK: JP1.17, JTAG.3
JTAG_TDI: JP1.14, JTAG.7
JTAG_TDO: JP1.16, JTAG.5
JTAG_TMS: JP1.18, JTAG.1
MEMSER_IN_BITS[0]: GPIO_1.14, JP2.4
MEMSER_IN_BITS[1]: GPIO_1.13, JP2.2
MEMSER_IN_BITS[2]: GPIO_1.10, JP1.40
MEMSER_IN_BITS[3]: GPIO_1.9, JP1.38
MEMSER_IN_BITS[4]: GPIO_1.8, JP1.36
MEMSER_IN_BITS[5]: GPIO_1.7, JP1.35
MEMSER_IN_BITS[6]: GPIO_1.6, JP1.34
MEMSER_IN_BITS[7]: GPIO_1.5, JP1.33
MEMSER_IN_READY: GPIO_1.2, JP1.31
MEMSER_IN_VALID: GPIO_1.4, JP1.32
MEMSER_OUT_BITS[0]: GPIO_1.24, JP2.16
MEMSER_OUT_BITS[1]: GPIO_1.23, JP2.14
MEMSER_OUT_BITS[2]: GPIO_1.22, JP2.12
MEMSER_OUT_BITS[3]: GPIO_1.21, JP2.11
MEMSER_OUT_BITS[4]: GPIO_1.20, JP2.10
MEMSER_OUT_BITS[5]: GPIO_1.19, JP2.9
MEMSER_OUT_BITS[6]: GPIO_1.18, JP2.8
MEMSER_OUT_BITS[7]: GPIO_1.17, JP2.7
MEMSER_OUT_READY: GPIO_1.15, JP2.5
MEMSER_OUT_VALID: GPIO_1.16, JP2.6
MISO: IC2.15 (B5), SD_CARD.8
MOSI: IC2.16 (B4), SD_CARD.10
unnamed: IC1.1 (A1), QSPI.2
unnamed: IC1.3 (A2), QSPI.4
unnamed: IC1.4 (A3), QSPI.6
unnamed: IC1.5 (A4), QSPI.8
unnamed: IC2.3 (A2), UART.2
unnamed: IC2.4 (A3), UART.4
unnamed: IC1.9 (A8), JTAG.8
unnamed: IC1.8 (A7), JTAG.6
unnamed: IC1.7 (A6), JTAG.4
unnamed: IC1.6 (A5), JTAG.2
unnamed: IC2.5 (A4), SD.2
unnamed: IC2.6 (A5), SD.4
unnamed: IC2.7 (A6), SD.6
unnamed: IC2.8 (A7), SD.8
unnamed: D4.C, Q5.3 (D)
unnamed: D2.C, Q6.3 (D)
unnamed: D3.C, Q7.3 (D)
unnamed: D1.C, Q8.3 (D)
unnamed: D1.A, R11.1
unnamed: D2.A, R13.1
unnamed: D3.A, R15.1
unnamed: D4.A, R17.1
RST_N: GPIO_2.35, JP4.16
RTCCLOCK: J1.5, JP4.19, RTC_CLK.2
RTCCLOCK_GPIO: GPIO_2.38, RTC_CLK.1
RX: IC2.18 (B2), USB-UART_1.2
SCLK: IC2.14 (B6), SD_CARD.6
SDRAMCLOCK: J2.5, JP4.18, SDRAM_CLK.2
SDRAMCLOCK_GPIO: GPIO_2.37, SDRAM_CLK.1
SDRAM_ADDR_O[0]: JP3.29
SDRAM_ADDR_O[1]: JP3.28
SDRAM_ADDR_O[2]: JP3.26
SDRAM_ADDR_O[3]: JP3.24
SDRAM_ADDR_O[4]: JP3.23
SDRAM_ADDR_O[5]: JP3.22
SDRAM_ADDR_O[6]: JP3.21
SDRAM_ADDR_O[7]: JP3.20
SDRAM_ADDR_O[8]: JP3.19
SDRAM_ADDR_O[9]: JP3.18
SDRAM_ADDR_O[10]: JP3.17
SDRAM_ADDR_O[11]: JP3.16
SDRAM_ADDR_O[12]: JP3.14
SDRAM_BA_O[0]: JP3.31
SDRAM_BA_O[1]: JP3.30
SDRAM_CAS_O: JP3.7
SDRAM_CKE_O: JP3.4
SDRAM_CLK_O: JP3.2
SDRAM_CS_O: JP3.5
SDRAM_DATA_I[0]: JP4.38
SDRAM_DATA_I[1]: JP4.36
SDRAM_DATA_I[2]: JP4.35
SDRAM_DATA_I[3]: JP4.34
SDRAM_DATA_I[4]: JP4.33
SDRAM_DATA_I[5]: JP4.32
SDRAM_DATA_I[6]: JP4.31
SDRAM_DATA_I[7]: JP4.30
SDRAM_DATA_I[8]: JP4.29
SDRAM_DATA_I[9]: JP4.28
SDRAM_DATA_I[10]: JP4.26
SDRAM_DATA_I[11]: JP4.24
SDRAM_DATA_I[12]: JP4.23
SDRAM_DATA_I[13]: JP4.22
SDRAM_DATA_I[14]: JP4.21
SDRAM_DATA_I[15]: JP4.20
SDRAM_DATA_O[0]: JP4.11
SDRAM_DATA_O[1]: JP4.10
SDRAM_DATA_O[2]: JP4.9
SDRAM_DATA_O[3]: JP4.8
SDRAM_DATA_O[4]: JP4.7
SDRAM_DATA_O[5]: JP4.6
SDRAM_DATA_O[6]: JP4.5
SDRAM_DATA_O[7]: JP4.4
SDRAM_DATA_O[8]: JP4.2
SDRAM_DATA_O[9]: JP3.40
SDRAM_DATA_O[10]: JP3.38
SDRAM_DATA_O[11]: JP3.36
SDRAM_DATA_O[12]: JP3.35
SDRAM_DATA_O[13]: JP3.34
SDRAM_DATA_O[14]: JP3.33
SDRAM_DATA_O[15]: JP3.32
SDRAM_DQM_O[0]: JP3.12
SDRAM_DQM_O[1]: JP3.11
SDRAM_DQM_O[2]: JP3.10
SDRAM_DQM_O[3]: JP3.9
SDRAM_DRIVE_O: JP4.40
SDRAM_RAS_O: JP3.6
SDRAM_WE_O: JP3.8
SD_QSPI_CS: JP1.23, SD.7
SD_QSPI_MISO: JP1.26, SD.3
SD_QSPI_MOSI: JP1.28, SD.1
SD_QSPI_SCK: JP1.24, SD.5
SYS_CLK: J4.5, JP4.14, SYS_CLK.2
TCK: IC1.14 (B6), JTAG_20_PIN.9
TDI: IC1.12 (B8), JTAG_20_PIN.5
TDO: IC1.13 (B7), JTAG_20_PIN.13
TMS: IC1.15 (B5), JTAG_20_PIN.7
TX: IC2.17 (B3), USB-UART_1.4
UART_RXD: JP1.30, UART.1
UART_TXD: JP1.29, UART.3
VDD: C12.1, C13.1, JP1.13, JP1.39, JP2.13, JP2.39, JP3.15, JP3.39, JP4.13, JP4.39, POWER.2, POWER_LED.1
VDDO: C1.1, C3.1, C11.1, C14.1, IC1.2 (VCCA), IC1.10 (OE), IC2.2 (VCCA), IC2.10 (OE), JP1.1, JP1.27, JP2.1, JP2.25, JP3.1, JP3.25, JP4.1, JP4.27, POWER.4, POWER_LED.3
VDDO_LED: POWER_LED.4, Q6.1 (G), R12.2
VDD_1.8_1: C10.1, IC5.2 (VOUT_1), IC5.4 (VOUT_2), POWER.1
VDD_1.8_2: C6.1, IC3.2 (VOUT_1), IC3.4 (VOUT_2), POWER.3
VDD_3V3: 3.3V_GPIO.1, C2.1, C4.1, C5.1, C9.1, FLASH.1, FLASH.2, IC1.19 (VCCB), IC2.19 (VCCB), IC3.3 (VIN), IC5.3 (VIN), JTAG_20_PIN.1, JTAG_20_PIN.2, Q5.1 (G), R11.2, R13.2, R15.2, R16.2, R17.2, SD_CARD.1, SD_CARD.2, USB-UART_1.3
VDD_3V3_GPIO: 3.3V_GPIO.2, GPIO_1.29, GPIO_2.29
VDD_5V_USB: USB-UART_2.2
VDD_LED: POWER_LED.2, Q8.1 (G), R10.2

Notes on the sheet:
QSPI
SPI (uSD)
JTAG
UART
POWER
CLOCK
LED
GPIO
SOCKET
40-PIN GPIO


Board: 2 copper layers, 167.6 x 111.8 mm, 65 parts (1 on the bottom side), 119 nets.

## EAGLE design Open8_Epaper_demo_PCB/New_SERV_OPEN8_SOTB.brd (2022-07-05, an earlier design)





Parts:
0.7V, 1.2V, 1.8V: PINHD-1X2; 1X02
C1, C3, C22: 1.0uF; 0805
C2, C4, C25: 4.7uF; 0805
C5, C6, C7, C8, C10, C11, C13, C15, C26, C28, C32, C35, C37, C39, C41: 10uF; 0805
C9, C12, C14, C27, C33, C34, C36, C38, C40, C42: 0.1uF; 0805
CLOCK_GND: CONN_02; 1X02
CLOCK_OUT: CONN_01; 1X01
CLOCK_VDD: CONN_02; 1X02
CLOCK_VDD_1.8: CONN_01; 1X01
EPAPER_1, EPAPER_2: PINHD-1X8; 1X08
FLASH: PINHD-2X6; 2X06
GND: PINHD-2X3; 2X03
H2, H3: MOUNT-HOLE3.3; 3,3
IC1, IC2, IC3: TPS7A7001DDAR; SOIC127P600X170-9N
IC4, IC5: SN74AUP1G00DCKR; SOT65P210X110-5N
J3: CONN_03; 1X03
LED: CONN_01; 1X01
MUX: PINHD-1X2; 1X02
OUTPUT_ENABLE: CONN_01; 1X01
POWER: PINHD-2X6; 2X06
POWER_2.5V: CONN_02; 1X02
R1, R3, R24: 30.1k; 0805
R2: 42.2k; 0805
R4: 12k; 0805
R5, R29, R34, R36: 10k; 0805
R25: 78.7k; 0805
S1: SS12SDP2
SWITCH: PINHD-1X2; 1X02
U1: SN74AHC1G08DBVR; SOT95P280X145-5N
U2, U3: SN74AUP1G14DBVR; SOT65P210X110-5N
U$1, U$2, U$3, U$4: 2X41_HEADER
USB-UART_1, USB-UART_2: PINHD-1X4; 1X04
VBN: PINHD-1X2; 1X02
VBP: PINHD-1X2; 1X02
WAKEUP_SIGNAL: CONN_02; 1X02

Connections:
2: U$1.4
4: U$1.6
12: U$1.14
14: U$1.16
16: U$1.18
26: U$1.28
28: U$1.30
36: U$1.38
38: U$1.40
40: U$1.42
41: U$2.1
42: U$2.4
43: U$2.3
44: U$2.6
45: U$2.5
46: U$2.8
47: U$2.7
52: U$2.14
54: U$2.16
56: U$2.18
66: U$2.28
68: U$2.30
73: U$2.33
74: U$2.36
75: U$2.35
76: U$2.38
77: U$2.37
78: U$2.40
79: U$2.39
80: U$2.42
82: U$3.4
83: U$3.3
84: U$3.6
86: U$3.8
88: U$3.10
89: U$3.9
90: U$3.12
91: U$3.11
92: U$3.14
93: U$3.13
94: U$3.16
95: U$3.15
96: U$3.18
97: U$3.17
98: U$3.20
99: U$3.19
101: U$3.21
102: U$3.24
103: U$3.23
104: U$3.26
105: U$3.25
106: U$3.28
107: U$3.27
108: U$3.30
109: U$3.29
110: U$3.32
111: U$3.31
112: U$3.34
113: U$3.33
114: U$3.36
115: U$3.35
116: U$3.38
117: U$3.37
118: U$3.40
119: U$3.39
120: U$3.42
121: U$4.1
122: U$4.4
123: U$4.3
124: U$4.6
125: U$4.5
126: U$4.8
127: U$4.7
128: U$4.10
129: U$4.9
130: U$4.12
131: U$4.11
132: U$4.14
133: U$4.13
134: U$4.16
135: U$4.15
136: U$4.18
137: U$4.17
138: U$4.20
139: U$4.19
140: U$4.22
141: U$4.21
142: U$4.24
143: U$4.23
144: U$4.26
145: U$4.25
146: U$4.28
147: U$4.27
148: U$4.30
149: U$4.29
150: U$4.32
151: U$4.31
152: U$4.34
153: U$4.33
154: U$4.36
155: U$4.35
156: U$4.38
157: U$4.37
158: U$4.40
159: U$4.39
160: U$4.42
DR_ALL_DIPSW[0]: EPAPER_1.1, U$1.22
DR_ALL_DIPSW[1]: EPAPER_2.1, U$1.24
DR_ALL_DIPSW[2]: SWITCH.2, U$1.26
DR_ALL_DIPSW[3]: SWITCH.1, U$1.25
DR_ALL_I_PROG_COPI: U$1.29
DR_ALL_I_PROG_CS: U$1.33
DR_ALL_I_PROG_SCK: U$1.27
DR_ALL_I_SPIFLASH_CIPO: FLASH.8, U$2.32
DR_ALL_I_SPI_CIPO: U$2.21
DR_ALL_I_TCK: U$1.35
DR_ALL_I_TDI: U$1.39
DR_ALL_I_TMS: U$2.12
DR_ALL_I_TRST: U$2.13
DR_ALL_LEDS[0]: EPAPER_1.3, EPAPER_2.3, U$1.9
DR_ALL_LEDS[1]: EPAPER_1.2, EPAPER_2.2, U$1.11
DR_ALL_LEDS[2]: U3.2 (A), U$1.15
DR_ALL_LEDS[3]: LED.1, U$1.20
DR_ALL_O_PROG_CIPO: U$1.31
DR_ALL_O_SPIFLASH_COPI: FLASH.10, U$2.29
DR_ALL_O_SPIFLASH_CS: FLASH.12, U$2.31
DR_ALL_O_SPIFLASH_SCK: FLASH.6, U$2.25
DR_ALL_O_SPI_COPI: EPAPER_1.6, EPAPER_2.6, U$2.19
DR_ALL_O_SPI_CS: EPAPER_1.4, EPAPER_2.4, U$2.23
DR_ALL_O_SPI_SCK: EPAPER_1.5, EPAPER_2.5, U$2.17
DR_ALL_O_TDO: U$2.10
DR_ALL_RESET: J3.2, U$1.7
DR_ALL_RX_IN: U$3.1, USB-UART_1.2
DR_ALL_TX_OUT: U$2.34, USB-UART_1.4
DR_CLOCK: CLOCK_OUT.1, U$1.1
DR_MUX: MUX.1, R36.2, U$1.5
DR_OPEN8_VDD: C37.1, C38.1, POWER.6, U$1.21
DR_SERV_VDD: U$2.22
DR_VBN: C35.1, C36.1, U$1.36, VBN.1
DR_VBP: C32.1, C34.1, U$1.37, VBP.2
DR_VDD: C28.1, C33.1, POWER.4, U$2.15, VBP.1
GND: C1.2, C2.2, C3.2, C4.2, C5.2, C6.2, C7.2, C8.2, C9.2, C10.2, C11.2, C12.2, C13.2, C14.2, C15.2, C22.2, C25.2, C26.2, C27.2, C28.2, C32.2, C33.2, C34.2, C35.2, C36.2, C37.2, C38.2, C39.2, C40.2, C41.2, C42.2, CLOCK_GND.1, CLOCK_GND.2, EPAPER_1.7, EPAPER_2.7, FLASH.3, FLASH.4, GND.1, GND.2, GND.3, GND.4, GND.5, GND.6, IC1.8 (GND), IC1.9 (EP), IC2.8 (GND), IC2.9 (EP), IC3.8 (GND), IC3.9 (EP), IC4.3 (GND), IC5.3 (GND), MUX.2, POWER_2.5V.1, R1.2, R3.2, R5.2, R24.2, S1.3 (ON_2), U1.3 (GND), U2.3 (GND), U3.3 (GND), U$1.8, U$1.12, U$1.19, U$1.23, U$1.34, U$2.11, U$2.20, U$2.24, U$2.27, U$3.7, U$3.22, USB-UART_1.1, VBN.2, WAKEUP_SIGNAL.1
IN_1: 1.8V.2, C22.1, IC1.2 (EN), IC1.3 (IN)
IN_2: 1.2V.2, C1.1, IC2.2 (EN), IC2.3 (IN)
IN_3: 0.7V.2, C3.1, IC3.2 (EN), IC3.3 (IN)
unnamed: IC2.7 (FB), R1.1, R2.2
unnamed: IC3.7 (FB), R3.1, R4.2
unnamed: R34.1, S1.1 (ON_1)
unnamed: IC1.7 (FB), R24.1, R25.2
NOT_Q: IC4.4 (Y), IC5.1 (A), U1.1 (A)
NOT_Q_AND_SW: J3.1, U1.4 (Y)
NOT_WAKEUP_SIGNAL: IC5.2 (B), U2.4 (Y)
OUT_0.7V: C4.1, IC3.6 (OUT), POWER.7, R4.1
OUT_1.2V: C2.1, IC2.6 (OUT), POWER.5, POWER.9, R2.1
OUT_1.8V: C25.1, CLOCK_VDD.1, CLOCK_VDD_1.8.1, IC1.6 (OUT), R25.1
Q: IC4.2 (B), IC5.4 (Y), OUTPUT_ENABLE.1
RESET: IC4.1 (A), R5.1, R29.2, U3.4 (Y)
RST_SW: J3.3, S1.2 (COM), U1.2 (B)
VCCQ: C26.1, C27.1, POWER.2, U$1.3, U$1.17, U$1.32, U$2.9, U$2.26, U$3.5
VDDH: C41.1, C42.1, POWER.10, U$1.10
VDDLS: C39.1, C40.1, POWER.8, U$1.13
VDD_2.5V: C5.1, C6.1, C7.1, C8.1, C9.1, C10.1, C15.1, CLOCK_VDD.2, IC4.5 (VCC), IC5.5 (VCC), POWER.12, R29.1, R34.2, R36.1, U1.5 (VCC), U2.5 (VCC), U3.5 (VCC)
VDD_2.5V_IN: 0.7V.1, 1.2V.1, 1.8V.1, C11.1, C12.1, C13.1, C14.1, EPAPER_1.8, EPAPER_2.8, FLASH.1, FLASH.2, POWER.1, POWER.3, POWER.11, POWER_2.5V.2, USB-UART_1.3
VDD_5V: USB-UART_2.2
WAKEUP_SIGNAL: U2.2 (A), WAKEUP_SIGNAL.2

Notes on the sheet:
SOCKET
RESET
Mounting holes
MUX
FLASH
USB-UART
LED
SWITCH
POWER


Board: 2 copper layers, 126.5 x 100.0 mm, 79 parts (0 on the bottom side), 47 nets.

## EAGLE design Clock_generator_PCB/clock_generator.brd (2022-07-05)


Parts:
C1, C2, C4, C6, C8, C9, C10: 0.1uF; 0805
C3, C5, C7: 10uF; 0805
FB1, FB2, FB3: MMZ2012S601ATD25; 0805
GND: CONN_02; 1X02
IC1: 5X1503L-000NLGI; SON40P200X200X110-11N
IC2: SN74LVC1T45QDCKRQ1; SOT65P210X110-6N
J2, J3, J7: CONN_02; 1X02
J4, J6: CONN_01; 1X01
R1, R2, R3: 22; 0805
R5: 10K; 0805
R6: 10k; 0805

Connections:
CLK_OUT: IC2.4 (B), J6.1
GND: C1.2, C2.2, C3.2, C4.2, C5.2, C6.2, C7.2, C8.2, C9.2, C10.2, GND.1, GND.2, IC1.3 (OE1), IC1.6 (VSS), IC1.11 (EP), IC2.2 (GND), J2.2
unnamed: IC1.7 (OUT3), R3.1
unnamed: IC1.4 (OUT1), R1.2
unnamed: IC1.10 (OUT2), R2.1
OE2: IC1.9 (OE2), J2.1, R6.2
OUT1: R1.1
OUT2: IC2.3 (A), R2.2
OUT3: R3.2
SCLK/OE3/DFC1: IC1.1 (SCL/DFC1), J3.1
SEL/DFC/SDA/DFC0: IC1.2 (SEL_DFC/SDA/DFC0), J3.2, R5.1
VDD: C1.1, C3.1, C4.1, FB1.1, IC1.5 (VDD)
VDD1P8: FB1.2, J4.1, R5.2
VDDO: C2.1, C5.1, C6.1, C10.1, FB2.1, IC1.8 (VDDO), IC2.1 (VCCA), IC2.5 (DIR), R6.1
VDDO_IN: FB2.2, J7.1
VREF: C7.1, C8.1, C9.1, FB3.1, IC2.6 (VCCB)
VREF_IN: FB3.2, J7.2


Board: 2 copper layers, 38.0 x 20.0 mm, 26 parts (0 on the bottom side), 15 nets.

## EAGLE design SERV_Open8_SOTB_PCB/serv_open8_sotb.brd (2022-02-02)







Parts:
ALL_JTAG: PINHD-2X10; 2X10
C1, C3, C5, C7, C9, C22: 1.0uF; 0805
C2, C4, C6, C8, C10, C25: 4.7uF; 0805
C11, C26, C28, C32, C35, C37, C39, C41: 10uF; 0805
C12, C27, C33, C34, C36, C38, C40, C42: 0.1uF; 0805
C24, C29: 36pF; 0805
C30, C31: 22pF; 0805
CLOCK: PINHD-2X3; 2X03
FLASH: PINHD-2X6; 2X06
GND: PINHD-2X3; 2X03
H1, H2, H3, H4: MOUNT-HOLE3.3; 3,3
IC1, IC2, IC5, IC7, IC8, IC9: AP7331-WG-7; SOT95P285X145-5N
IC12, IC13: SN74LVC1GU04DBVR; SOT95P280X145-5N
LED: PINHD-2X4; 2X04
LED1, LED2, LED3, LED4, LED5, LED6, LED7, LED8, LED9, LED10, LED11, LED12: LEDCHIP-LED0805; CHIP-LED0805
MUX: PINHD-1X2; 1X02
POWER: PINHD-2X7; 2X07
POWER_LED: PINHD-2X3; 2X03
Q1, Q2, Q3, Q4, Q5, Q6, Q7, Q8, Q9, Q10, Q11, Q12: BSH103,235; SOT95P230X110-3N
R1, R4, R7, R10, R13, R24, R25: 66.5k; 0805
R2, R11, R14: 133k; 0805
R5, R8: 482k; 0805
R16, R18, R20, R22, R27, R29, R31, R33, R37, R39, R49, R51: 330; 0805
R17, R19, R21, R23, R28, R30, R32, R34, R35, R36, R38, R40, R50, R52, R53, R54, R55, R56: 10k; 0805
R41, R45: 10M; 0805
R42, R43, R46, R47: 47k; 0805
R44: 2k; 0805
R48: 300k; 0805
RESET: REG_IN; JP1
S1, S2, S3, S4, S5: SS12SDP2
SMA: 2985-6004; 29856004
SPI_1: SPI1; FE10
SPI_2: SPI0; FE10
SWITCH: PINHD-2X4; 2X04
U$1, U$2, U$3, U$4: 2X41_HEADER
U$5: RFM95W-915S2
USB-UART_1, USB-UART_2: PINHD-1X4; 1X04
VBN: PINHD-1X2; 1X02
VBP: PINHD-1X2; 1X02
VCCQ: PINHD-1X2; 1X02
VDD: PINHD-1X2; 1X02
VDDH: PINHD-1X2; 1X02
VDDLS: PINHD-1X2; 1X02
VDD_3V3: PINHD-1X2; 1X02
VDD_CORE: PINHD-1X2; 1X02
Y1: Q13FC1350000400
Y3: HC-49SM8MHZ20PF30PPM; HC49SM8MHZ20PF30PPM

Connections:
2: U$1.4
4: U$1.6
8MHZ_CLOCK: CLOCK.3, IC12.4 (Y), R41.2, R44.1
12: U$1.14
14: U$1.16
16: U$1.18
26: U$1.28
28: U$1.30
32KHZ_CLOCK: CLOCK.1, IC13.4 (Y), R45.2, R48.1
36: U$1.38
38: U$1.40
40: U$1.42
41: U$2.1
42: U$2.4
43: U$2.3
44: U$2.6
45: U$2.5
46: U$2.8
47: U$2.7
52: U$2.14
54: U$2.16
56: U$2.18
66: U$2.28
68: U$2.30
73: U$2.33
74: U$2.36
75: U$2.35
76: U$2.38
77: U$2.37
78: U$2.40
79: U$2.39
80: U$2.42
82: U$3.4
83: U$3.3
84: U$3.6
86: U$3.8
88: U$3.10
89: U$3.9
90: U$3.12
91: U$3.11
92: U$3.14
93: U$3.13
94: U$3.16
95: U$3.15
96: U$3.18
97: U$3.17
98: U$3.20
99: U$3.19
101: U$3.21
102: U$3.24
103: U$3.23
104: U$3.26
105: U$3.25
106: U$3.28
107: U$3.27
108: U$3.30
109: U$3.29
110: U$3.32
111: U$3.31
112: U$3.34
113: U$3.33
114: U$3.36
115: U$3.35
116: U$3.38
117: U$3.37
118: U$3.40
119: U$3.39
120: U$3.42
121: U$4.1
122: U$4.4
123: U$4.3
124: U$4.6
125: U$4.5
126: U$4.8
127: U$4.7
128: U$4.10
129: U$4.9
130: U$4.12
131: U$4.11
132: U$4.14
133: U$4.13
134: U$4.16
135: U$4.15
136: U$4.18
137: U$4.17
138: U$4.20
139: U$4.19
140: U$4.22
141: U$4.21
142: U$4.24
143: U$4.23
144: U$4.26
145: U$4.25
146: U$4.28
147: U$4.27
148: U$4.30
149: U$4.29
150: U$4.32
151: U$4.31
152: U$4.34
153: U$4.33
154: U$4.36
155: U$4.35
156: U$4.38
157: U$4.37
158: U$4.40
159: U$4.39
160: U$4.42
DR_ALL_DIPSW[0]: SWITCH.7, U$1.22
DR_ALL_DIPSW[1]: SWITCH.5, U$1.24
DR_ALL_DIPSW[2]: SWITCH.3, U$1.26
DR_ALL_DIPSW[3]: SWITCH.1, U$1.25
DR_ALL_I_PROG_COPI: SPI_2.2, U$1.29
DR_ALL_I_PROG_CS: SPI_2.4, U$1.33
DR_ALL_I_PROG_SCK: SPI_2.1, U$1.27
DR_ALL_I_SPIFLASH_CIPO: FLASH.8, U$2.32
DR_ALL_I_SPI_CIPO: U$2.21, U$5.P$2 (MISO)
DR_ALL_I_TCK: ALL_JTAG.9, U$1.35
DR_ALL_I_TDI: ALL_JTAG.5, U$1.39
DR_ALL_I_TMS: ALL_JTAG.7, U$2.12
DR_ALL_I_TRST: ALL_JTAG.3, U$2.13
DR_ALL_LEDS[0]: LED.7, U$1.9
DR_ALL_LEDS[1]: LED.5, U$1.11
DR_ALL_LEDS[2]: LED.3, U$1.15
DR_ALL_LEDS[3]: LED.1, U$1.20
DR_ALL_O_PROG_CIPO: SPI_2.3, U$1.31
DR_ALL_O_SPIFLASH_COPI: FLASH.10, U$2.29
DR_ALL_O_SPIFLASH_CS: FLASH.12, U$2.31
DR_ALL_O_SPIFLASH_SCK: FLASH.6, U$2.25
DR_ALL_O_SPI_COPI: U$2.19, U$5.P$3 (MOSI)
DR_ALL_O_SPI_CS: U$2.23, U$5.P$5 (NSS)
DR_ALL_O_SPI_SCK: U$2.17, U$5.P$4 (SCK)
DR_ALL_O_TDO: ALL_JTAG.13, U$2.10
DR_ALL_RESET: RESET.1, U$1.7
DR_ALL_RX_IN: U$3.1, USB-UART_1.2
DR_ALL_TX_OUT: U$2.34, USB-UART_1.4
DR_CLOCK: CLOCK.2, CLOCK.4, CLOCK.6, U$1.1
DR_MUX: MUX.1, R36.2, U$1.5
DR_OPEN8_VDD: C37.1, C38.1, POWER.8, POWER_LED.5, U$1.21
DR_OPEN8_VDD_LED: POWER_LED.6, Q5.1 (G), R28.1
DR_SERV_VDD: C26.1, C27.1, POWER.4, POWER_LED.1, U$2.22
DR_SERV_VDD_LED: POWER_LED.2, Q6.1 (G), R30.1
DR_VBN: C35.1, C36.1, U$1.36, VBN.1
DR_VBP: C32.1, C34.1, U$1.37, VBP.2
DR_VDD: C28.1, C33.1, POWER.6, POWER_LED.3, U$2.15, VBP.1
DR_VDD_LED: POWER_LED.4, Q7.1 (G), R32.1
GND: ALL_JTAG.4, ALL_JTAG.6, ALL_JTAG.8, ALL_JTAG.10, ALL_JTAG.12, ALL_JTAG.14, ALL_JTAG.16, ALL_JTAG.18, ALL_JTAG.20, C1.2, C2.2, C3.2, C4.2, C5.2, C6.2, C7.2, C8.2, C9.2, C10.2, C11.2, C12.2, C22.2, C24.1, C25.2, C26.2, C27.2, C28.2, C29.1, C30.1, C31.1, C32.2, C33.2, C34.2, C35.2, C36.2, C37.2, C38.2, C39.2, C40.2, C41.2, C42.2, FLASH.3, FLASH.4, GND.1, GND.2, GND.3, GND.4, GND.5, GND.6, IC1.2 (GND), IC2.2 (GND), IC5.2 (GND), IC7.2 (GND), IC8.2 (GND), IC9.2 (GND), MUX.2, Q1.2 (S), Q2.2 (S), Q3.2 (S), Q4.2 (S), Q5.2 (S), Q6.2 (S), Q7.2 (S), Q8.2 (S), Q9.2 (S), Q10.2 (S), Q11.2 (S), Q12.2 (S), R1.2, R4.2, R7.2, R10.2, R13.2, R17.2, R19.2, R21.2, R23.2, R24.2, R28.2, R30.2, R32.2, R35.2, R38.2, R40.2, R43.1, R47.1, R50.2, R52.2, S1.3 (ON_2), S2.3 (ON_2), S3.3 (ON_2), S4.3 (ON_2), S5.3 (ON_2), SMA.1, SMA.2, SMA.3, SMA.4, SPI_2.10, U$1.8, U$1.12, U$1.19, U$1.23, U$1.34, U$2.11, U$2.20, U$2.24, U$2.27, U$3.7, U$3.22, U$5.P$1 (GND_1), U$5.P$8 (GND_2), U$5.P$15 (GND_3), USB-UART_1.1, VBN.2
IN_VDD: C9.1, IC9.1 (IN), IC9.3 (EN), VDD.2
IN_VDDH: C1.1, IC2.1 (IN), IC2.3 (EN), VDDH.2
IN_VDDLS: C22.1, IC1.1 (IN), IC1.3 (EN), VDDLS.2
IN_VDDQ: C3.1, IC5.1 (IN), IC5.3 (EN), VCCQ.2
IN_VDD_3V3: C5.1, IC7.1 (IN), IC7.3 (EN), VDD_3V3.2
IN_VDD_CORE: C7.1, IC8.1 (IN), IC8.3 (EN), VDD_CORE.2
LED_0: LED.8, Q9.1 (G), R38.1
LED_1: LED.6, Q10.1 (G), R40.1
LED_2: LED.4, Q11.1 (G), R50.1
LED_3: LED.2, Q12.1 (G), R52.1
unnamed: IC2.4 (ADJ), R1.1, R2.2
unnamed: IC5.4 (ADJ), R4.1, R5.2
unnamed: IC7.4 (ADJ), R7.1, R8.2
unnamed: IC8.4 (ADJ), R10.1, R11.2
unnamed: IC9.4 (ADJ), R13.1, R14.2
unnamed: R34.1, S1.1 (ON_1)
unnamed: LED2.C, Q1.3 (D)
unnamed: LED1.C, Q3.3 (D)
unnamed: LED2.A, R18.1
unnamed: LED9.C, Q9.3 (D)
unnamed: LED9.A, R37.1
unnamed: LED1.A, R16.1
unnamed: IC1.4 (ADJ), R24.1, R25.2
unnamed: LED3.C, Q2.3 (D)
unnamed: LED3.A, R20.1
unnamed: RESET.2, S1.2 (COM)
unnamed: LED4.C, Q4.3 (D)
unnamed: LED4.A, R22.1
unnamed: LED10.C, Q10.3 (D)
unnamed: LED5.C, Q5.3 (D)
unnamed: LED5.A, R27.1
unnamed: LED10.A, R39.1
unnamed: LED6.C, Q6.3 (D)
unnamed: LED6.A, R29.1
unnamed: C29.2, IC12.2 (A), R41.1, Y3.2 (CRYSTAL_2)
unnamed: LED7.C, Q7.3 (D)
unnamed: LED7.A, R31.1
unnamed: C24.2, R44.2, Y3.1 (CRYSTAL_1)
unnamed: LED8.C, Q8.3 (D)
unnamed: LED8.A, R33.1
unnamed: IC12.3 (GND), R43.2
unnamed: IC12.5 (VCC), R42.1
unnamed: C31.2, IC13.2 (A), R45.1, Y1.2 (CRYSTAL_2)
unnamed: LED11.C, Q11.3 (D)
unnamed: C30.2, R48.2, Y1.1 (CRYSTAL_1)
unnamed: LED11.A, R49.1
unnamed: IC13.3 (GND), R47.2
unnamed: LED12.C, Q12.3 (D)
unnamed: LED12.A, R51.1
unnamed: IC13.5 (VCC), R46.1
unnamed: R53.1, S2.1 (ON_1)
unnamed: R54.1, S3.1 (ON_1)
unnamed: R55.1, S4.1 (ON_1)
unnamed: R56.1, S5.1 (ON_1)
unnamed: S2.2 (COM), SWITCH.2
unnamed: S3.2 (COM), SWITCH.4
unnamed: S4.2 (COM), SWITCH.6
unnamed: S5.2 (COM), SWITCH.8
OUT_VDD: C10.1, IC9.5 (OUT), POWER.5, R14.1
OUT_VDDH: C2.1, IC2.5 (OUT), POWER.11, R2.1
OUT_VDDLS: C25.1, IC1.5 (OUT), POWER.9, R25.1
OUT_VDDQ: C4.1, IC5.5 (OUT), POWER.1, R5.1
OUT_VDD_3V3: C6.1, IC7.5 (OUT), POWER.13, R8.1
OUT_VDD_CORE: C8.1, IC8.5 (OUT), POWER.3, POWER.7, R11.1
SMA_CLK: CLOCK.5, SMA.5
VCCQ: C11.1, C12.1, POWER.2, Q2.1 (G), R21.1, U$1.3, U$1.17, U$1.32, U$2.9, U$2.26, U$3.5
VDDH: C41.1, C42.1, POWER.12, Q1.1 (G), R19.1, U$1.10
VDDLS: C39.1, C40.1, POWER.10, Q3.1 (G), R17.1, U$1.13
VDD_3V3: ALL_JTAG.1, ALL_JTAG.2, FLASH.1, FLASH.2, POWER.14, Q4.1 (G), R16.2, R18.2, R20.2, R22.2, R23.1, R27.2, R29.2, R31.2, R33.2, R34.2, R36.1, R37.2, R39.2, R42.2, R46.2, R49.2, R51.2, R53.2, R54.2, R55.2, R56.2, U$5.P$12 (3.3V), USB-UART_1.3
VDD_5V: Q8.1 (G), R35.1, USB-UART_2.2, VCCQ.1, VDD.1, VDDH.1, VDDLS.1, VDD_3V3.1, VDD_CORE.1

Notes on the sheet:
SOCKET
RESET
CLOCK GENERATOR
32KHZ
8MHZ
SMA
Mounting holes
MUX
LORA
FLASH
SPI
USB-UART
JTAG
LED
SWITCH
POWER


Board: 2 copper layers, 138.5 x 140.0 mm, 153 parts (0 on the bottom side), 111 nets.

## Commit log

2021-05-26 initial begin
    [de0.brd, de0.sch]
2021-05-31 Connect source for switches
    [de0.brd, de0.sch]
2021-05-31 Organize regulator circuits
    [de0.brd]
2021-05-31 Check USB and UART
    [de0.sch]
2021-05-31 Update layout
    [de0.brd]
2021-06-01 Create plain for power wires
    [de0.brd]
2021-06-01 Update polygons
    [de0.brd]
2021-06-01 Update layout again
    [de0.brd]
2021-06-01 Add more via for power connection
    [de0.brd]
2021-06-04 Organize the schematic and the layout
    [de0.brd, de0.sch]
2021-06-07 Add 4 holes for the screws
    [de0.brd]
2021-06-07 Update again schematic for consistency
    [de0.brd, de0.sch]
2021-06-08 change as Duran's suggest
    [de0.brd, de0.sch]
2021-06-08 change BJT to MOSFET for power leds
    [de0.brd, de0.sch]
2021-06-09 Update again with Duran's suggest
    [de0.brd, de0.sch]
2021-06-10 change USB connector
    [de0.brd, de0.sch]
2021-06-29 Add qfp160 socket and open8 board for SOTB
    [demo_open8.brd, demo_open8.sch, qfp160_socket.brd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]
2021-07-06 add pin numbers for the socket
    [qfp160_socket.brd]
2021-07-09 Add BOM and CPL files
    [Open8-BOM.xlsx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]
2021-08-18 Update schematic for TR4 PCB
    [TR4.brd]
2021-09-13 Add pull resistor for mosfet
    [TR4.brd, TR4.sch]
2021-09-27 new schematic and layout from Thuc's suggestion
    [TR4.brd, TR4.sch]
2021-09-30 Update signal name and connect pin 59 and 60
    [TR4.brd, TR4.sch]
2021-10-01 put header for param[0] signal
    [TR4.brd, TR4.sch]
2021-10-01 update file
    update BOM, position, and Gerber file, change the footprint of the level shifter
    [TR4.sch]
2021-10-01 update for order
    [TEE-ROHM-BOM.xlsx, TR4.brd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]
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2021-10-01 add Gerber for socket
2021-11-01 Update PCB for Open8 & SERV of TSMC and ROHM
    [PINDEF_Pin_Assignment_RO1821_1_R4251.xlsx, Pin_Assignment_TSMC6521_1_20210630.xlsx, serv_open8_rohm.brd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]
2021-11-01 Update new socket PCB for the QFP160
    [qfp160_socket_new.brd, qfp160_socket_new.sch]
2021-11-15 Update gerber, bom and position file for PCB
    [serv_open8_tsmc_bom.xlsx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]
2021-11-15 Change in position of Jtag connector
    [serv_open8_rohm.brd, serv_open8_rohm.sch]
2021-11-15 Update cpl file
    [serv_open8_tsmc_cpl1.xlsx]
2021-12-20 Update PCB of Dao, change switch resistor to 0805
    [BaAnh_rohm_bom.xlsx, PCB_ROHM_BaAnh.brd, PCB_ROHM_BaAnh.sch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]
2021-12-21 change led from white to green
    [BaAnh_rohm_bom.xlsx]
2021-12-21 update boom and gerber file
    [serv_open8_sotb.sch, serv_open8_sotb_bom.xlsx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]
2021-12-21 Upload 20pin jtag to pmod adapter
    [Pmod_to_JTAG.brd, Pmod_to_JTAG.sch]
2022-01-04 Update new PCB for the TEE
    [MappedPin_5x5_newFootprint.xlsx, MappedPin_5x7.5_newFootprint.xlsx, New_U540.brd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]
2022-01-06 Change regulators for higher current
    [New_U540.brd, New_U540.sch]
2022-01-07 Update new footprint for Lora module
    [serv_open8_sotb.brd, serv_open8_sotb.sch]
2022-01-11 Update boom file
    [New_U540.brd, new_u450_rohm_bom.xlsx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]
2022-01-12 Update new bom
    [new_u450_rohm_bom.xlsx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]
2022-02-02 Update new regulators
    [serv_open8_sotb.brd, serv_open8_sotb.sch, serv_open8_sotb_bom.xlsx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]
2022-07-05 Upload clock generator and epaper demo board
    [New_SERV_OPEN8_SOTB.brd, New_SERV_OPEN8_SOTB.sch, Pin_Assignment_RS6521_1_.xlsx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]
2022-08-12 Add PCB for the Rocket32_TRASIO
    [MappedPins.xlsx, Rocket32_TRASIO.brd, Rocket32_TRASIO.sch]
2022-08-29 Upload BOM and gerber files
    [Rocket32_TRASIO_bom.xlsx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]
2022-08-30 Update the new n channel mosfet
    [Rocket32_TRASIO.brd, Rocket32_TRASIO.sch, Rocket32_TRASIO_bom.xlsx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]
2022-09-18 Upload new TRASIO PCB with some fixes
    [MappedPins.xlsx, Rocket32_TRASIO_fixed.brd, Rocket32_TRASIO_fixed.sch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]
2022-09-18 Update position of Flash
    [Rocket32_TRASIO_fixed.brd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]
2022-09-22 Fix SD card position
    [Rocket32_TRASIO_fixed.brd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]
2022-09-25 Update position of SD card again
    [Rocket32_TRASIO_fixed.brd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]
2022-09-27 This should work man
    [Rocket32_TRASIO_fixed.brd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]
2022-09-30 demo PCB for epaper
    [New_SERV_OPEN8_SOTB.brd, New_SERV_OPEN8_SOTB.sch, New_SERV_OPEN8_SOTB_bom.xlsx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]
2022-09-30 add trimmer
    [New_SERV_OPEN8_SOTB.brd, New_SERV_OPEN8_SOTB.sch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]
2022-09-30 update the cpl
    [New_SERV_OPEN8_SOTB_cpl1.xlsx]
2022-10-27 Upload PCB for new ROHM (Rocket + SERV + LEROS)
    [ROHM_102022.brd, ROHM_102022.sch]
2022-10-27 Update pdf for schematic of ROHM102022
    [ROHM_102022.sch]
2022-10-29 Connect JTAG to FPGA
    [ROHM_102022.brd, ROHM_102022.sch]
2022-11-16 Upload new PCB schematic for SOTB Feb.2022
    [Pin_Assignment_SOTB_2022_1.xlsx, SOTB_Feb22.sch]
2022-11-16 Update the pcb of SOTB Feb2022
    [Pin_Assignment_SOTB_2022_1.xlsx, SOTB_Feb22.sch]
2022-11-18 Update the PCB with layout
    [SOTB_Feb22.brd, SOTB_Feb22.sch]
2022-12-02 Upload bom and cpl
    [Pin_Assignment_RO1822_1_R4252_wPackage.xlsx, ROHM_102022.brd, ROHM_102022.sch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]
2023-01-12 Upload PCB for SOTB LWC of Ronaldo
    [SOTB_LWC.brd, SOTB_LWC.sch]
2023-01-13 Upload bom and cpl file for SOTB LWC Jan.2023
    [SOTB_LWC_bom.xlsx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]
2023-01-13 Change led from 1206 to 0805
    [SOTB_LWC.brd, SOTB_LWC.sch, SOTB_LWC_bom.xlsx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]
2023-04-18 upload pin map for lwc pcb
    [LWC_pins.xlsx]
2023-07-26 add pdf for schematic
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

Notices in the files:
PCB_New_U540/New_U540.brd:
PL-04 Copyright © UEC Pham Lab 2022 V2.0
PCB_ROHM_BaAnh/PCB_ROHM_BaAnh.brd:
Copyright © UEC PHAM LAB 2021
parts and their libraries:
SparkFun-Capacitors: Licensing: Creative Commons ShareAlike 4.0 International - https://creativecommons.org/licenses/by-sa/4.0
